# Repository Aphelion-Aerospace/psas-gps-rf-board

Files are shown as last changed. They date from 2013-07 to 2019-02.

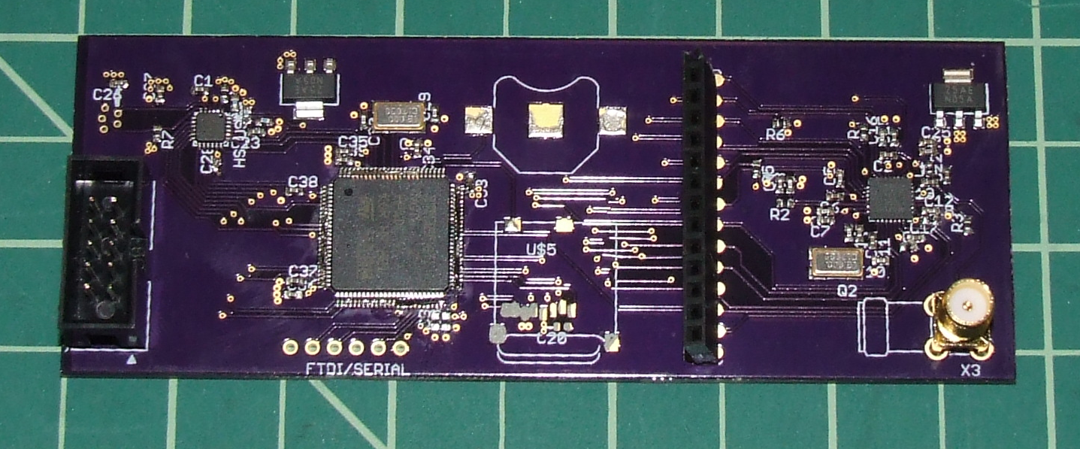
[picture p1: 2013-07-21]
poster/rf-board.png

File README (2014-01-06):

Universal GPS RF Front-end Board

Current status: January 2014 - Ready to order v2 board and parts 

Author: Jenner Hanni <wicker>
School: Portland State University

License: BSD "3 clause" license.

BOM available at 
https://docs.google.com/spreadsheet/ccc?key=0Aj2ugLxWTS6bdDNQeDJjXzUxYTRNRFFiaVJvZ1Nmanc&usp=sharing

This is an RF front-end board that breaks out I and Q signals to serial, USB, and Ethernet for GPS receiver development. 

Several GPS receiver boards exist on the market to receive GPS satellite signals and process it to provide location data but these GPS receivers only give the final location. Getting access to the raw data before they go into correlators means you have to purchase a “RF front end” for hundreds of dollars, at which point you can work on projects like building an FPGA receiver board or developing a software radio receiver. 

Both of these projects are in-progress projects at Portland State, and are stalled on purchasing the very expensive RF front end. This project proposes to design, build, and release an open-source GPS receiver RF front-end board that would offer the GPS raw data over USB and serial outputs. Open source GPS receiver boards do exist, including in Andrew Greenberg’s GPL-GPS Master’s thesis, but all are based on very out dated and out-of-production GPS chipsets and are not easily acquired. 

Cost is also a factor: commercial RF front end boards are hundreds to thousands of dollars. And while the proposed chip for this project, the MAX2769 Universal GPS Receiver, costs only $5, the development kit is $600 -- in other words, cost prohibitive for a small project and frustrating for embedded software developers who may not have the time or experience to design and build their own hardware.

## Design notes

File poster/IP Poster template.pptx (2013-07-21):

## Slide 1

  - Universal GPS RF Front-end Board

  - Jenner Hanni, MEng, ECE

Summary

This is an open source, hand held device that makes raw GPS satellite data available for the development of custom receivers.

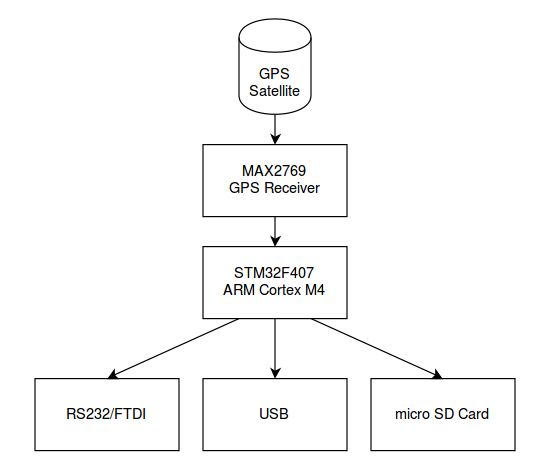
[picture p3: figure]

Figure 1. Data path from satellite to user.

Implementation

Powered by either a 3.3V Coin cell battery or 5V DC power over USB from a laptop.
The data stream is available over USB, serial, or directly to the micro SD card.
STM32F407 is an ARM Cortex M4 chip.
MAX2769 GPS Receiver chip supports a powered or unpowered antenna.
The STM32F407 is a newer chip with extensive documentation and a hobbyist developer community.
All schematics and software are open source so the board can be modified.
Total component cost is under $100.

Claim

GPS receivers turn the reference data from the satellites into an absolute position. Making new and better GPS receivers is good for both consumer product development and academic research with applications from medical devices to autonomous vehicles.
There are many techniques that can be used in the GPS receivers but developers need the raw I and Q signals from a front-end board.
Current boards are closed-source, don't make enough streaming data available or allow for enough of it to be saved, and in any case are prohibitively expensive.


Figure 2. Hardware prototype.

Requirements

Mobile, hand-held. Low cost with readily available components. Multiple ways to save the data and platform independent.
Open source schematics and software.

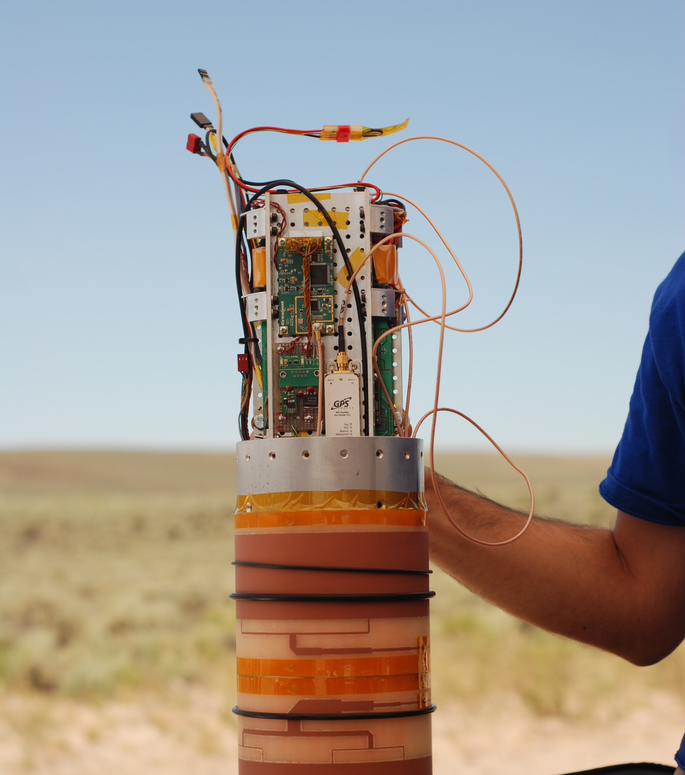
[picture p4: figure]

Figure 3. Rocket avionics module

Collaborators

Bart Massey, Andrew Greenberg and
the Portland State Aerospace Society.
Source code and schematics available at
http://github.com/wicker/

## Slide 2

Hardware

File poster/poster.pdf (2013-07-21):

l Jenner Hanni, MEng, ECE

## lUniversal GPS RF Front-end Board

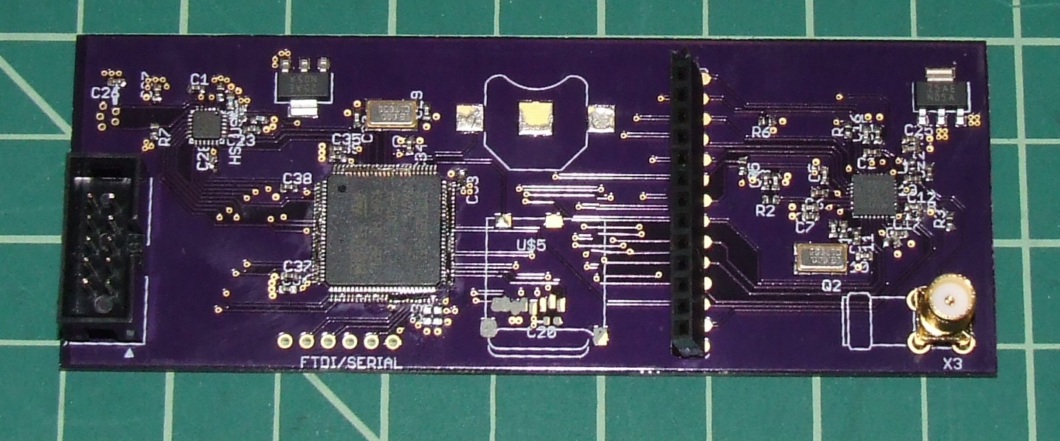
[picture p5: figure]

Figure 2. Hardware prototype.

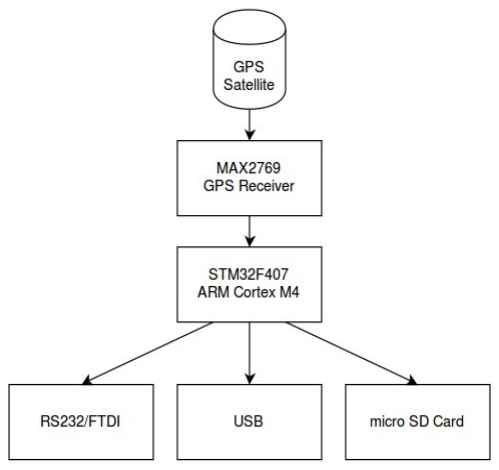
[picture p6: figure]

Figure 1. Data path from satellite to user.

This is an open source, hand held device that makes raw GPS satellite data available for the development of custom receivers.

### Summary

GPS receivers turn the reference data from the satellites into an absolute position. Making new and better GPS receivers is good for both consumer product development and academic research with applications from medical devices to autonomous vehicles.

There are many techniques that can be used in the GPS receivers but developers need the raw I and Q signals from a front-end board.

Current boards are closed-source, don't make enough streaming data available or allow for enough of it to be saved, and in any case are prohibitively expensive.

### Claim

Mobile, hand-held. Low cost with readily available components. Multiple ways to save the data and platform independent. Open source schematics and software.

### Requirements

Powered by either a 3.3V Coin cell battery or 5V DC power over USB from a laptop.

The data stream is available over USB, serial, or directly to the micro SD card.

STM32F407 is an ARM Cortex M4 chip.

MAX2769 GPS Receiver chip supports a powered or unpowered antenna.

The STM32F407 is a newer chip with extensive documentation and a hobbyist developer community.

All schematics and software are open source so the board can be modified.

Total component cost is under $100.

### Implementation

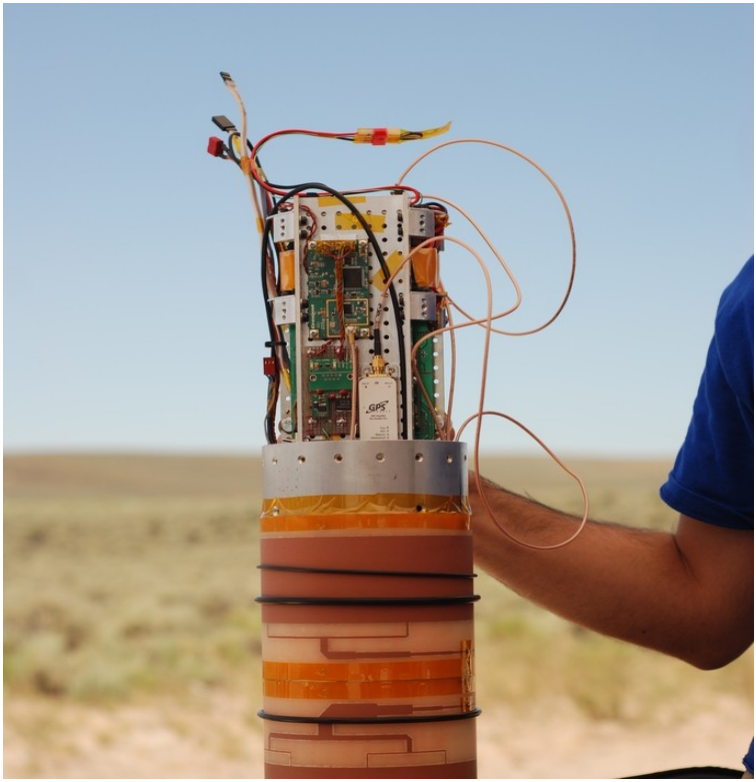
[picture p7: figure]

Figure 3. Rocket avionics module

Bart Massey, Andrew Greenberg and the Portland State Aerospace Society.

Source code and schematics available at http://github.com/wicker/

### Collaborators

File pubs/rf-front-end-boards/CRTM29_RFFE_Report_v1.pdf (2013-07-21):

## Design and Development of an RF Front End Board for NIJ Public Safety Radio

### S.M. Shajedul Hasan∗ and S.W. Ellingson

### July 22, 2008

## Contents

1 Introduction | 2
2 RFFE Board Overview | 2
3 Analog Signal Path Planning | 4
4 Description of Multiplexer Section | 6
5 Description of Amplifier Section | 8
6 Description of Attenuator Section | 8
7 Description of Power Supply Section | 10
8 Description of the Settings | 10
9 Summary | 10
A Bill of Materials | 14
B Schematic | 19
C Layout | 24

∗Bradley Dept. of Electrical & Computer Engineering, 432 Durham Hall, Virginia Polytechnic Institute & State University, Blacksburg, VA 24061 USA. E-mail: hasan@vt.edu

## 1 Introduction

An experimental multi-band/multi-mode radio for public safety applications is being developed in Virginia Tech under a project sponsored by the U.S. Department of Justice [1]. The goal of this project is to develop and demonstrate a single radio which can operate in all the public safety frequency bands presented in [2, 3]. To provide context, Figure 1 shows a conceptual “board-level” overview of a prototype of the proposed radio, consisting of a RF front end board, RFIC transceiver board, ADC/DAC board, baseband processing board, and other control boards. The design and development of the RF front end (RFFE) board is described here.

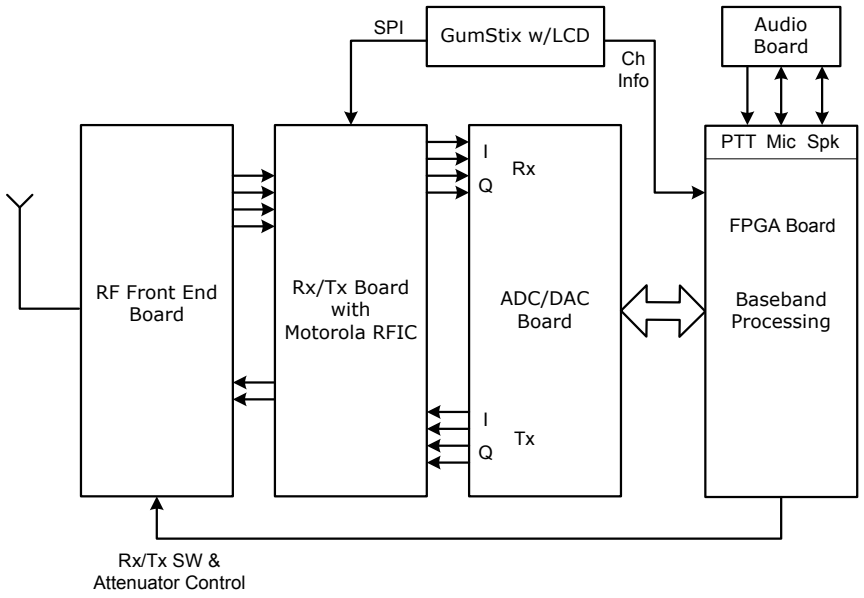
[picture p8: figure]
Rx/Tx Board with Motorola RFIC; RF Front End Board; ADC/DAC Board; Rx/Tx SW & Attenuator Control; Baseband Processing; FPGA Board; GumStix w/LCD SPI; Audio; Board; PTT Mic Spk; Ch Info

Figure 1: Conceptual board-level overview.

Figure 2 shows the image of the RF front end board.

This report is organized as follows. Section 2 presents the summary of the input/output ports of RFFE board. Section 3 describes the signal path planning and Section 4 presents multiplexer design methodology. Section 5 and 6 presents the circuit description of the amplifier and attenuator respectively. Section 6 describes the various jumper and switch settings. Section 7 concludes the report presenting the total cost. Finally, three appendices present the bill of materials, complete schematic and layout images.

## 2 RFFE Board Overview

Figure 3 and Table 1 present all the input/output ports of the RFFE board.

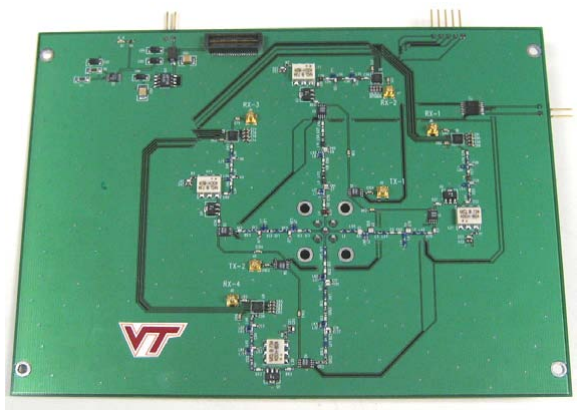
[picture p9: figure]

Figure 2: Image of RF Front End board.

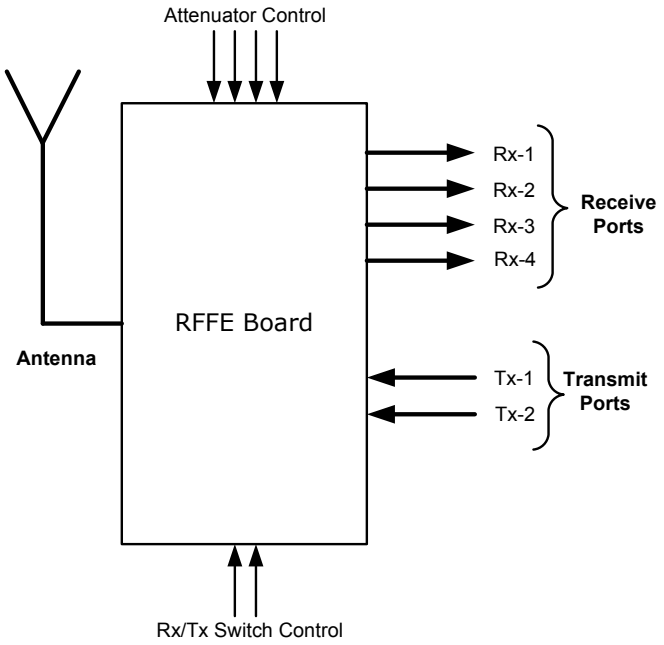
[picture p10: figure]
RFFE Board; Receive; Ports; Transmit; Attenuator Control; Rx/Tx Switch Control; Antenna

Figure 3: Summary of RFFE board.

Function | Port Name | Conn. Name | Characteristics
Receive Ports | RX-1 | J6 | RF Mux Ch-1 receive port
| RX-2 | J7 | RF Mux Ch-2 receive port
| RX-3 | J8 | RF Mux Ch-3 receive port
| RX-4 | J9 | RF Mux Ch-4 receive port
Transmit Ports | TX-1 | J2 | RF Mux Ch-1 or Ch-2 transmit port
| TX-2 | J3 | RF Mux Ch-3 or Ch-4 transmit port
Attenuator Control | ATT CTL | J5 | Attenuator control signals
Rx/Tx switch | SW CTL | J4 | Rx/Tx switch control signals

Table 1: Input/Output ports of the RFFE board.

## 3 Analog Signal Path Planning

This section describes some considerations in planning of the RFFE analog signal path. “Analog signal path” is defined here as the section beginning at the antenna terminals and ending at the input to the analog-to-digital converter (ADC). The analog signal path under consideration contains all the circuitry in the RFFE board, which includes multiplexer, amplifier, additional filtering and attenuators, and the RFIC transceiver board described in [4].

This signal path requirements are developed following the general strategy described in [5]. In order to receive the signal and digitize it appropriately the level of incoming signal should meet the specification of ADC. In this document we use the specifications of Analog Devices AD9248 ADC described in [6]. The relevant parameters and design constraints are shown in Table 2. Given this information, we can compute the required number of bits:

Nb ≥ 1.67 log10

Ptγr

Pextδr

(1)

where Pt

is the sum of the total receive signal power plus Pext, which is approximately equal to the total external noise power calculated using the table from [7]. Also, the minimum required gain in the analog signal path Gmin, and the maximum allowed gain Gr can be found using the following equations:

Gmin =

PQγq

Pext

(2)

Gr =

Pclipδr
Pt

(3)

A summary of the analysis is provided in Table 3, which shows the values of various design parameters (Nb,Gmin,Gr) corresponding to our frequency bands. Table 4, 5, 6, and 7 present the GNI analysis of the analog section for various channels using nominal gain.

Parameter | Value | Definition
Pclip PQ γq δr | +4 dBm -62 dBm +10 dB -10 dB | ADC full scale ADC quantization noise power, referenced to ADC input Desired ratio of Pext to PQ Maximum acceptable input power relative to Pclip

Table 2: Assumed analog-to-digital converter (ADC) specifications and associated design constraints.

Frequency | Pt | Pext | Nb | Gmin | Gr
138-174 MHz | -90.0 dBm | -122.5 dBm | 8.8 | 70.5 dB | 84.0 dB
220-222 MHz | -90.0 dBm | -128.1 dBm | 9.7 | 76.1 dB | 84.0 dB
406-512 MHz | -90.0 dBm | -135.3 dBm | 10.9 | 83.3 dB | 84.0 dB
764-862 MHz | -90.0 dBm | -142.9 dBm | 12.2 | 90.9 dB | 84.0 dB

Table 3: Design implications (Nb,Gmin,Gr) corresponding to various choices of frequency range and response. Gain here defined is defined from antenna terminals to ADC input.

Section | Gain (dB) | IP3 (dBm) | Noise Figure (dB)
Muiltiplexer | -8 | 200 | 8
Preamp | 25 | 12.9 | 2.7
Filter | -1 | 200 | 1
Attenuator | -1 | 30 | 1
RFIC | 69 | -6 | 7
GNI Analysis | 84 | -21.0 | 10.75
Sensitivity | -117.8 dBm

Table 4: GNI analysis of Channel-1 for nominal gain.

Section | Gain (dB) | IP3 (dBm) | Noise Figure (dB)
Muiltiplexer | -4 | 200 | 4
Preamp | 25 | 12.9 | 2.7
Filter | -1 | 200 | 1
Attenuator | -5 | 30 | 5
RFIC | 69 | -6 | 7
GNI Analysis | 84 | -21.0 | 6.84
Sensitivity | -120.8 dBm

Table 5: GNI analysis of Channel-2 for nominal gain.

Section | Gain (dB) | IP3 (dBm) | Noise Figure (dB)
Muiltiplexer | -1 | 200 | 1
Preamp | 25 | 12.9 | 2.7
Filter | -1 | 200 | 1
Attenuator | -8 | 30 | 8
RFIC | 69 | -6 | 7
GNI Analysis | 84 | -21.0 | 3.98
Sensitivity | -127.8 dBm

Table 6: GNI analysis of Channel-3 for nominal gain.

Section | Gain (dB) | IP3 (dBm) | Noise Figure (dB)
Muiltiplexer | -5.0 | 200 | 5.0
Preamp | 25 | 12.9 | 2.7
Filter | -1 | 200 | 1
Attenuator | -1.0 | 30 | 1.0
RFIC | 66 | -6 | 7
GNI Analysis | 84 | -24.0 | 7.75
Sensitivity | -125.5 dBm

Table 7: GNI analysis of Channel-4 for nominal gain.

## 4 Description of Multiplexer Section

A four channel multiplexer has been designed using the methodology described in [8]. As we know sensitivity depends on signal to noise ratio and external noise can be very strong in practical scenarios, especially at low frequencies (below ˜400 MHz). So, when the ratio of external noise to internal noise is large, additional effort to minimize reflection co-efficient or internal noise will have little effect on sensitivity. Therefore, our main idea is to design a multiplexer, which may be poorly matched with the antenna impedance, in such a way that the front end is dominated by the external noise and provide acceptable sensitivity.

In our design we use a simple monopole antenna ANT-433-CW from Antenna Factor. The length of this antenna is 17.3 cm long and diameter is 6 mm. The measured impedance of this antenna is shown in Figure 4.

Figure 5 shows the response of the designed multiplexer optimized to match with the antenna impedance to provide acceptable sensitivity. These results are expressed in terms of transducer power gain (TPG), defined as the ratio of power delivered by a matching network to a load, to the power delivered to a perfectly matched load directly from the antenna. Note that the performance is unacceptable, especially in the 138-174 MHz band. However, this poor matching gives us the sensitivity of -117.8 dBm, which is acceptable for our receiver.

Each of the channel of our designed multiplexer uses fifth order chebyshev topology, which is shown in Figure 6. Table 8 shows the component values of multiplexer before and

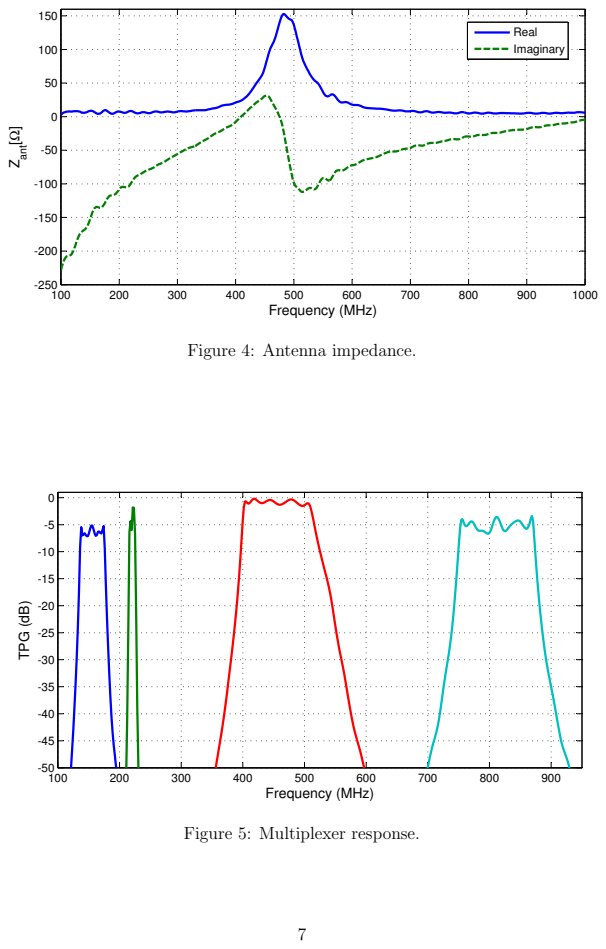
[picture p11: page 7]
Frequency (MHz); Zant; Real; Imaginary; TPG (dB)

Figure 4: Antenna impedance.

Figure 5: Multiplexer response.

after the optimization. L1 | C1
L2 | C2
L3 | C3
L4 | C4
L5 | C5

50Ω

Receiver
Input To Antenna

Figure 6: Multiplexer topology of each channel.

Component | Channel–1 | Channel–2 | Channel–3 | Channel–4
| Before | After | Before | After | Before | After | Before | After
L1 (nH) | 377.1 | 306.0 | 1357.4 | 1350 | 111.2 | 120 | 114.9 | 130
C1 (pF) | 2.8 | 5.4 | 0.4 | 0.41 | 1.1 | 1.1 | 0.3 | 0.308
L2 (nH) | 9.7 | 7.8 | 1.3 | 1.32 | 3.1 | 3.1 | 0.9 | 1.15
C2 (pF) | 108.7 | 139.0 | 391.4 | 399 | 39.0 | 39.0 | 42.8 | 33.8
L3 (nH) | 561.6 | 426.0 | 2021.9 | 2027 | 173.4 | 175 | 182.0 | 178
C3 (pF) | 1.9 | 2.45 | 0.3 | 0.255 | 0.7 | 0.7 | 0.2 | 0.216
L4 (nH) | 9.7 | 9.0 | 1.3 | 1.32 | 3.1 | 3.1 | 0.9 | 1.15
C4 (pF) | 108.7 | 118.0 | 391.4 | 393.0 | 39.0 | 39.0 | 42.8 | 33.7
L5 (nH) | 377.1 | 246.0 | 1357.4 | 1380 | 112.2 | 110 | 114.9 | 105.6
C5 (pF) | 2.8 | 4.33 | 0.4 | 0.375 | 1.1 | 1.1 | 0.3 | 0.368

Table 8: Component values of the multiplexer before and after the optimization.

## 5 Description of Amplifier Section

In our design we use GALI-74 amplifier from Minicircuits. This amplifier is chosen mainly for its low cost and low noise characteristics. ADCH-80A, a wideband choke from Minicircuits, is also used to minimize the RF loss caused by the DC biasing resistor. The circuit of this amplifier is designed for 9V DC bias. Fig. 7 shows the circuit diagram example for the amplifier. Detailed circuit diagrams can be found in “Amplifier” sheet in Appendix B. This sheet also contains four fifth order chebyshev bandpass filters after each of the amplifiers to perform additional filtering.

## 6 Description of Attenuator Section

To control the attenuation of the received signal we use a 5-bit digitally controlled attenuator HMC470LP3 from Hittite Microwave Inc. Fig. 8 shows the circuit diagram of the attenuator. Detailed circuit diagrams can be found in “Attenuator” sheet in Appendix B.

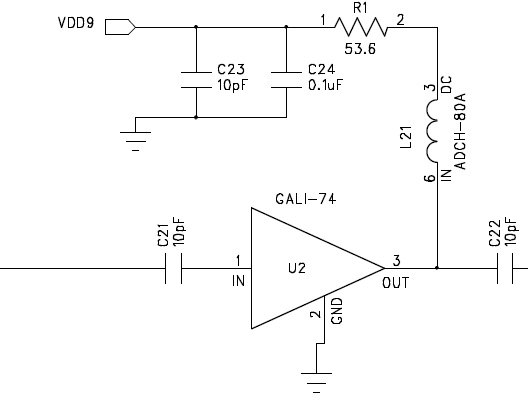
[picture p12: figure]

Figure 7: Amplifier section ( the unconnected line on the left side connects the input port of the amplifier with the RX switches and right side goes to input of the bandpass filter).

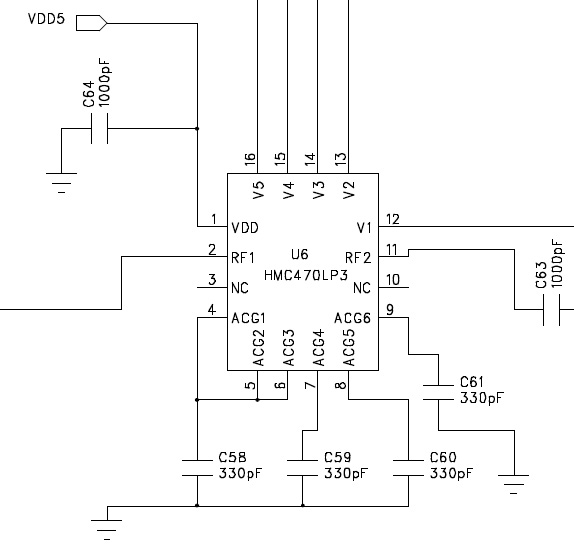
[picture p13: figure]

Figure 8: Attenuator section (RF1 and RF2 are the input and output port of the attenuator. Other unconnected lines in the figure are the control signal to vary the attenuation).

## 7 Description of Power Supply Section

One 9V supply voltage for amplifiers and one 5V supply voltage for RF switches and attenuators, have been created from a single 16V power source. This 16V input voltage is fed into a 1.1A low dropout regulator IC LT1965 to create a 9V positive voltage. 5V regulated voltage is supplied by the 500 mA low dropout regulator ICs LT763. Both of these regulator ICs are manufactured by Linear Technology Inc. Detailed circuit diagrams can be found in “Power Supply” sheet in Appendix B.

## 8 Description of the Settings

Table 9 shows the specification of attenuator control signals to get various attenuation.

V1 16dB | V2 8dB | v3 4dB | V4 2dB | V5 1dB | ATT State
High | High | High | High | High | Insertion Loss
High | High | High | High | Low | 1dB
High | High | High | Low | High | 2dB
High | High | Low | High | High | 4dB
High | Low | High | High | High | 8dB
Low | High | High | High | High | 16dB
Low | Low | Low | Low | Low | 31dB

Table 9: Attenuator control signals.

Table 10 shows the Rx/Tx swtich control signals.

S0 | S1 | Rx/Tx Mode
High | X | RX Mode
Low | Low | TX Mode ( Ch.1 or Ch.3 )
Low | High | TX Mode ( Ch.2 or Ch.4 )

Table 10: Rx/Tx Switch Control Signals.

## 9 Summary

A summary of the cost for one RFFE board is given in Table 11. Since we prepared just two boards for the present study using the quickest manufacturing time, the PCB fabrication and assembly cost is not representative of the cost to build the same device in large quantities.

Component | Quantity | Price(US $)
Regulator ICs | 2 | 8.58
Amplifier | 4 | 18.80
RF Choke | 4 | 59.0
Attenuator | 4 | 15.32
RF Switch | 6 | 7.08
Capacitor | 109 | 16.35
Inductor | 61 | 45.75
Resistor | 7 | 1.00
MMCX Connector | 6 | 60.30
Other Connectors | 5 | 10.0
Other Components | 3 | 3.50
| Subtotal | 245.68
PC Board | 1 | 450.00
PC Board Assembly | 1 | 925.00
| Total | 1620.68

Table 11: Summary of the cost for one RFFE board.

## References

[1] NIJ project web site, http://www.ece.vt.edu/swe/chamrad/.
[2] S. W. Ellingson, “Phase I Technical Report,” Virginia Tech, VA, Tech. Rep. 15, Oct. 2006. [Online]. Available: http://www.ece.vt.edu/swe/chamrad/.
[3] S. W. Ellingson, S.M. Hasan, M. Harun, and C.R. Anderson, “Phase II Technical Report,” Virginia Tech, VA, Tech. Rep. 23, Oct. 2007. [Online]. Available: http://www.ece.vt.edu/swe/chamrad/.
[4] S.M. Hasan and S.W. Ellingson, “Design and Development of an Evaluation Board with RFIC Ver. 4,” Virginia Tech, VA, Tech. Rep. 22, Sep. 2007. [Online]. Available: http://www.ece.vt.edu/swe/chamrad/.
[5] D.W.A. Taylor III, Design of Ultrawideband Digitizing Receivers for the VHF Low Band, M.S. Thesis, Virginia Polytechnic Institute & State University, 2006. [Online]. Available: http://scholar.lib.vt.edu/theses/available/etd-05162006-161217/.
[6] S.M. Hasan and S.W. Ellingson, “ Design and Development of an ADC/DAC Evaluation Board for NIJ Public Safety Radio,” Virginia Tech, VA, Tech. Rep. 24, Nov. 2007. [Online]. Available: http://www.ece.vt.edu/swe/chamrad/.
[7] S.M. | Hasan | and | S.W. | Ellingson, | “ | Optimum | Noise | Figure | Specifica-
tion,” | Virginia Tech, | VA, Tech. Rep. 20, | Apr. 2007. [Online]. Available:
http://www.ece.vt.edu/swe/chamrad/.
[8] S.M. Hasan and S.W. Ellingson, “Multiband Antenna-Receiver Integration using an RF Multiplexer with Sensitivity-Constrained Design”, IEEE 2008 International Symposium on Antenna and Propagation, San Diego, July, 2008.

# Appendices

## A Bill of Materials

This section presents the bill of materials.

Bill of Materials
RFFE Board, Ver.2.0
MPRG/Virginia Tech
Prepared By: S.M. Hasan, Date: MAR 11, 2008
Item | Qty | Reference | Part Name | Package | Manufacturer | Manufacturer Part# | Distributor | Distributor Part# | Description
1 | 1 | U1 | 74VHCT04AMTC | 14-TSSOP | FAIRCHILD | 74VHCT04AMTC | Mouser | 512-74VHCT04AMTC | HEX INVERTER
2 | 4 | L21 L27 L33 L39 | ADCH-80A | CD542 | Minicircuits | ADCH-80A+ | Minicircuits | ADCH-80A+ | RF Choke
3 | 1 | C93 | 0.01uF 100V | CAP_1210 | AVX Corporation | 12101C103KAT2A | Digikey | 478-1608-1-ND | SURFACE MOUNT CAPACITOR 0.098 X 0.126 INCHES
4 | 1 | C92 | 1uF 100V | CAP_1210 | AVX Corporation | 12101C105KAT2A | Digikey | 478-2570-1-ND | SURFACE MOUNT CAPACITOR 0.098 X 0.126 INCHES
5 | 4 | C24 C33 C42 C51 | 0.1uF 50V | CAP_0603 | Murata Electronics | GRM188R71H104KA93D | Digikey | 490-1519-1-ND | SURFACE MOUNT CAPACITOR 0603 Size
6 | 3 | C52 C54 C56 | 0.3pF 50V | CAP_0603 | AVX Corporation | 06035J0R3PBTTR | Digikey | 478-2801-1-ND | SURFACE MOUNT CAPACITOR 0603 Size
7 | 1 | C86 | 0.4pF 250V | CAP_0603 | AVX Corporation | SQCSVA0R4BAT1A | Digikey | 478-3483-1-ND | SURFACE MOUNT CAPACITOR 0603 Size
8 | 3 | C10 C36 C99 | 0.5pF 100V | CAP_0603 | Murata Electronics | GQM1885C2AR50CB01D | Digikey | 490-3551-1-ND | SURFACE MOUNT CAPACITOR 0603 Size
9 | 1 | C106 | 0.6pF 250V | CAP_0603 | AVX Corporation | SQCSVA0R6BAT1A | Digikey | 478-3484-1-ND | SURFACE MOUNT CAPACITOR 0603 Size
10 | 4 | C8 C13 C78 C107 | 0.7pF 50V | CAP_0603 | AVX Corporation | 06035J0R7PBSTR | Digikey | 478-4445-1-ND | SURFACE MOUNT CAPACITOR 0603 Size
11 | 4 | C16 C34 C38 C101 | 0.8pF 250V | CAP_0603 | AVX Corporation | SQCSVA0R8BAT1A | Digikey | 478-3485-1-ND | SURFACE MOUNT CAPACITOR 0603 Size
12 | 3 | C20 C105 C109 | 0.9pF 50V | CAP_0603 | AVX Corporation | 06035J0R9PBTTR | Digikey | 478-2807-1-ND | SURFACE MOUNT CAPACITOR 0603 Size
13 | 2 | C11 C15 | 1.1pF 250V | CAP_0603 | AVX Corporation | SQCSVA1R1BAT1A | Digikey | 478-3487-1-ND | SURFACE MOUNT CAPACITOR 0603 Size
14 | 4 | C43 C47 C97 C108 | 1.5pF 250V | CAP_0603 | AVX Corporation | SQCSVA1R5BAT1A | Digikey | 478-3489-1-ND | SURFACE MOUNT CAPACITOR 0603 Size
15 | 1 | C27 | 1.8pF 250V | CAP_0603 | AVX Corporation | SQCSVA1R8BAT1A | Digikey | 478-3490-1-ND | SURFACE MOUNT CAPACITOR 0603 Size
16 14 | | C63-64 C71-72 C79-80 C87-88 C96 C98 C100 C102-104 | 1000pF 50V | CAP_0603 | AVX Corporation | 06035C102KAT2A | Digikey | 478-1215-1-ND | SURFACE MOUNT CAPACITOR 0603 Size
17 | 2 | C2 C4 | 100pF 50V | CAP_0603 | AVX Corporation | 06035A101KAT2A | Digikey | 478-3717-1-ND | SURFACE MOUNT CAPACITOR 0603 Size
18 | 12 | C21-23 C30-32 C39-41 C48-50 | 10pF 250V | CAP_0603 | AVX Corporation | SQCSVA100JAT1A | Digikey | 478-3502-1-ND | SURFACE MOUNT CAPACITOR 0603 Size
19 | 2 | C26 C28 | 110pF 100V | CAP_0603 | Murata Electronics | GRM1885C2A111JA01D | Digikey | 490-1352-1-ND | SURFACE MOUNT CAPACITOR 0603 Size
20 | 1 | C70 | 18pF 250V | CAP_0603 | AVX Corporation | SQCSVA180JAT1A | Digikey | 478-3505-1-ND | SURFACE MOUNT CAPACITOR 0603 Size
21 | 3 | C6 C18 C45 | 1pF 250V | CAP_0603 | AVX Corporation | SQCSVA1R0BAT1A | Digikey | 478-3486-1-ND | SURFACE MOUNT CAPACITOR 0603 Size

Item | Qty | Reference | Part Name | Package | Manufacturer | Manufacturer Part# | Distributor | Distributor Part# | Description
22 | 1 | C57 | 2.4pF 250V | CAP_0603 | AVX Corporation | SQCSVA2R4BAT1A | Digikey | 478-3493-1-ND | SURFACE MOUNT CAPACITOR 0603 Size
23 | 2 | C25 C29 | 2.7pF 250V | CAP_0603 | AVX Corporation | SQCSVA2R7BAT1A | Digikey | 478-3494-1-ND | SURFACE MOUNT CAPACITOR 0603 Size
24 | 2 | C35 C37 | 200pF 100V | CAP_0603 | Murata Electronics | GRM1885C2A201JA01D | Digikey | 490-1358-1-ND | SURFACE MOUNT CAPACITOR 0603 Size
25 | 16 | C58-61 C66-69 C74-77 C82-85 | 330pF 50V | CAP_0603 | Panasonic | ECJ-1VC1H331J | Digikey | PCC331ACVCT-ND | SURFACE MOUNT CAPACITOR 0603 Size
26 | 5 | C17 C19 C53 C55 C95 | 33pF 250V | CAP_0603 | AVX Corporation | SQCSVA330JAT1A | Digikey | 478-3511-1-ND | SURFACE MOUNT CAPACITOR 0603 Size
27 | 2 | C7 C9 | 360pF 100V | CAP_0603 | Murata Electronics | GRM1885C2A361JA01D | Digikey | 490-1364-1-ND | SURFACE MOUNT CAPACITOR 0603 Size
28 | 6 | C12 C14 C44 C46 C62 C81 | 39pF 250V | CAP_0603 | AVX Corporation | SQCSVA390JAT1A | Digikey | 478-3512-1-ND | SURFACE MOUNT CAPACITOR 0603 Size
29 | 1 | C1 | 3pF 250V | CAP_0603 | AVX Corporation | SQCSVA3R0BAT1A | Digikey | 478-3495-1-ND | SURFACE MOUNT CAPACITOR 0603 Size
30 | 1 | C65 | 4.7pF 250V | CAP_0603 | AVX Corporation | SQCSVA4R7CAT1A | Digikey | 478-3498-1-ND | SURFACE MOUNT CAPACITOR 0603 Size
31 | 1 | C3 | 5.1pF 100V | CAP_0603 | Murata Electronics | GQM1885C2A5R1CB01D | Digikey | 490-3559-1-ND | SURFACE MOUNT CAPACITOR 0603 Size
32 | 1 | C5 | 8.2pF 250V | CAP_0603 | AVX Corporation | SQCSVA8R2CAT1A | Digikey | 478-3501-1-ND | SURFACE MOUNT CAPACITOR 0603 Size
33 | 1 | C73 | 9.1pF 50V | CAP_0603 | Murata Electronics | GQM1885C1H9R1CB01D | Digikey | 490-3569-1-ND | SURFACE MOUNT CAPACITOR 0603 Size
34 | 4 | C89-91 C94 | 10uF 16V | CAP_3216 | Rohm | TCA1C106M8R | Digikey | 511-1473-1-ND | CAP TANTALUM
35 | 1 | J11 | CONN_SAM8128_HEADE R | Plug | Samtec Inc | QTE-020-01-X-D-A | Digikey | SAM8128-ND | HIGH SPEED HEADER 40 PINS
36 | 1 | J1 | CONN_RPSMA-THROUGH | SMA | Linx Technologies | CONREVSMA001 | Digikey | CONREVSMA001-ND | SMA Through Hole Connector
37 | 4 | U2-5 | GALI-74 | DF782 | Mincircuits | GALI-74+ | Minicircuits | GALI-74+ | Monolithic Amplifier
38 | 6 | S1-6 | HMC284MS8G | MS8G | HITTITE | HMC284MS8G | HITTITE | HMC284MS8G | RF SWITHC
39 | 4 | U6-9 | HMC470LP3 | LP3 | HITTITE | HMC470LP3 | HITTITE | HMC470LP3 | 5 BIT DIGITAL ATTENUATOR
40 | 1 | D1 | LED_SMT | SMT | LITE-ON | LTST-C190GKT | Digikey | 160-1183-1-ND | LIGHT EMITTING DIODE
41 | 1 | E2 | LT1965 | MSOP8G | LINEAR TECHNOLOGY | LT1965 | Digikey | LT1965IMS8E#PBF-ND | LINEAR LDO REGULATOR
42 | 4 | L17 L19 L41 L43 | 1.6nH | L_0603 | Coilcraft | 0603CS-1N6X_LU | Coilcraft | 0603CS-1N6X_LU | Surface Mount Inductor 0603 Size
43 | 1 | L30 | 1000nH | L_0603 | Coilcraft | 0603LS-102X_LB | Coilcraft | 0603LS-102X_LB | Surface Mount Inductor 0603 Size
44 | 4 | L15-16 L20 L56 | 100nH | L_0603 | Coilcraft | 0603CS-R10X_LU | Coilcraft | 0603CS-R10X_LU | Surface Mount Inductor 0603 Size
45 | 1 | L58 | 10nH | L_0603 | Coilcraft | 0603CS-10NX_LU | Coilcraft | 0603CS-10NX_LU | Surface Mount Inductor 0603 Size
46 | 1 | L18 | 110nH | L_0603 | Coilcraft | 0603CS-R11X_LU | Coilcraft | 0603CS-R11X_LU | Surface Mount Inductor 0603 Size
47 | 2 | L8 L10 | 1200nH | L_0603 | Coilcraft | 0603LS-122X_LB | Coilcraft | 0603LS-122X_LB | Surface Mount Inductor 0603 Size
48 | 5 | L11 L36 L40 L42 L44 | 120nH | L_0603 | Coilcraft | 0603CS-R12X_LU | Coilcraft | 0603CS-R12X_LU | Surface Mount Inductor 0603 Size

Item | Qty | Reference | Part Name | Package | Manufacturer | Manufacturer Part# | Distributor | Distributor Part# | Description
49 | 1 | L2 | 12nH | L_0603 | Coilcraft | 0603CS-12NX_LU | Coilcraft | 0603CS-12NX_LU | Surface Mount Inductor 0603 Size
50 | 1 | L54 | 180nH | L_0603 | Coilcraft | 0603CS-R18X_LU | Coilcraft | 0603CS-R18X_LU | Surface Mount Inductor 0603 Size
51 | 2 | L7 L53 | 2.2nH | L_0603 | Coilcraft | 0603CS-2N2X_LU | Coilcraft | 0603CS-2N2X_LU | Surface Mount Inductor 0603 Size
52 | 6 | L29 L31 L62-65 | 2.6nH | L_0603 | Coilcraft | 0604HQ-2N6XJLB | Coilcraft | 0604HQ-2N6XJLB | Surface Mount Inductor 0603 Size
53 | 1 | L5 | 210nH | L_0603 | Coilcraft | 0603HP-R21X_LU | Coilcraft | 0603HP-R21X_LU | Surface Mount Inductor 0603 Size
54 | 1 | L46 | 22nH | L_0603 | Coilcraft | 0603CS-22NX_LU | Coilcraft | 0603CS-22NX_LU | Surface Mount Inductor 0603 Size
55 | 2 | L6 L50 | 2700nH | L_0603 | Coilcraft | 0603LS-272X_LB | Coilcraft | 0603LS-272X_LB | Surface Mount Inductor 0603 Size
56 | 1 | L1 | 270nH | L_0603 | Coilcraft | 0603HP-R27X_LU | Coilcraft | 0603HP-R27X_LU | Surface Mount Inductor 0603 Size
57 | 4 | L9 L35 L37 L51 | 3.3nH | L_0603 | Coilcraft | 0603HP-3N3X_LU | Coilcraft | 0603HP-3N3X_LU | Surface Mount Inductor 0603 Size
58 | 1 | L59 | 30nH | L_0603 | Coilcraft | 0603HP-30NX_LU | Coilcraft | 0603HP-30NX_LU | Surface Mount Inductor 0603 Size
59 | 3 | L45 L47 L49 | 36nH | L_0603 | Coilcraft | 0603HP-36NX_LU | Coilcraft | 0603HP-36NX_LU | Surface Mount Inductor 0603 Size
60 | 3 | L3 L22 L26 | 390nH | L_0603 | Coilcraft | 0603CS-R39X_LU | Coilcraft | 0603CS-R39X_LU | Surface Mount Inductor 0603 Size
61 | 1 | L48 | 4.3nH | L_0603 | Coilcraft | 0603HP-4N3X_LU | Coilcraft | 0603HP-4N3X_LU | Surface Mount Inductor 0603 Size
62 | 1 | L4 | 4.7nH | L_0603 | Coilcraft | 0603HP-4N7X_LU | Coilcraft | 0603HP-4N7X_LU | Surface Mount Inductor 0603 Size
63 | 3 | L12 L14 L61 | 5.6nH | L_0603 | Coilcraft | 0603HP-5N6X_LU | Coilcraft | 0603HP-5N6X_LU | Surface Mount Inductor 0603 Size
64 | 1 | L24 | 560nH | L_0603 | Coilcraft | 0603LS-561X_LB | Coilcraft | 0603LS-561X_LB | Surface Mount Inductor 0603 Size
65 | 2 | L55 L57 | 6.8nH | L_0603 | Coilcraft | 0603HP-6N8X_LU | Coilcraft | 0603HP-6N8X_LU | Surface Mount Inductor 0603 Size
66 | 2 | L28 L32 | 680nH | L_0603 | Coilcraft | 0603LS-681X_LB | Coilcraft | 0603LS-681X_LB | Surface Mount Inductor 0603 Size
67 | 1 | L60 | 68nH | L_0603 | Coilcraft | 0603HP-68NX_LU | Coilcraft | 0603HP-68NX_LU | Surface Mount Inductor 0603 Size
68 | 1 | L13 | 75nH | L_0603 | Coilcraft | 0603HP-75NX_LU | Coilcraft | 0603HP-75NX_LU | Surface Mount Inductor 0603 Size
69 | 1 | L52 | 827nH | L_0603 | Coilcraft | 0603LS-821X_LB | Coilcraft | 0603LS-821X_LB | Surface Mount Inductor 0603 Size
70 | 2 | L34 L38 | 82nH | L_0603 | Coilcraft | 0603HP-82NX_LU | Coilcraft | 0603HP-82NX_LU | Surface Mount Inductor 0603 Size
71 | 2 | L23 L25 | 9.5nH | L_0603 | Coilcraft | 0603HP-9N5X_LU | Coilcraft | 0603HP-9N5X_LU | Surface Mount Inductor 0603 Size
72 | 6 | J2-3 J6-9 | MMCX_PLUG | MMCX | Emerson | 135-3801-201 | Digikey | J601-ND | MMCX CONNECTOR
73 | 2 | J4 J10 | RA_SINGLEHEADER_2PIN | Male Header | TYCO | 87232-2 | Digikey | A28764-ND | 2-Pin R/A Single Row Header

Item | Qty | Reference | Part Name | Package | Manufacturer | Manufacturer Part# | Distributor | Distributor Part# | Description
74 | 1 | J5 | RA_SINGLEHEADER_5PIN | Male Header | TYCO | 87232-5 | Digikey | A28770-ND | 5-Pin R/A Single Row Header
75 | 4 | R1-4 | 53.6 1/10W | RES_0603 | Panasonic | ERJ-3EKF53R6V | Digikey | P53.6HCT-ND | SURFACE MOUNT RESISTOR 0603 Size
76 | 1 | R5 | 698 1/10W | RES_0603 | Rohm | MCR03EZPFX6980 | Digikey | RHM698HCT-ND | SURFACE MOUNT RESISTOR 0603 Size
77 | 1 | R6 | 26.1K 1/4W | RES_1206 | Rohm | MCR18EZHF2612 | Digikey | RHM26.1KFCT-ND | SURFACE MOUNT RESISTOR 1206 Size
78 | 1 | R7 | 4.02K 1/14W | RES_1206 | Rohm | MCR18EZHF4021 | Digikey | RHM4.02KFCT-ND | SURFACE MOUNT RESISTOR 1206 Size
79 | 1 | E1 | SM_BEADS_DIFF | SMT | FAIR-RITE PRODUCTS CORP | 2743019447 | Mouser | 623-2743019447LF | SM BEADS DIFFERENTIAL
80 | 1 | U10 | REGULATOR | SO-8 | Linear Technology | LT1763CS8-5 | Digikey | LT1763CS8-5-ND | Linear Regulator

## B Schematic

This section presents the schematic of the RFFE board. This schematic contains the following four pages-

- Multiplexer and Switch Circuits
- Amplifier Circuits
- Attenuator Circuits
- Power Supply Circuits

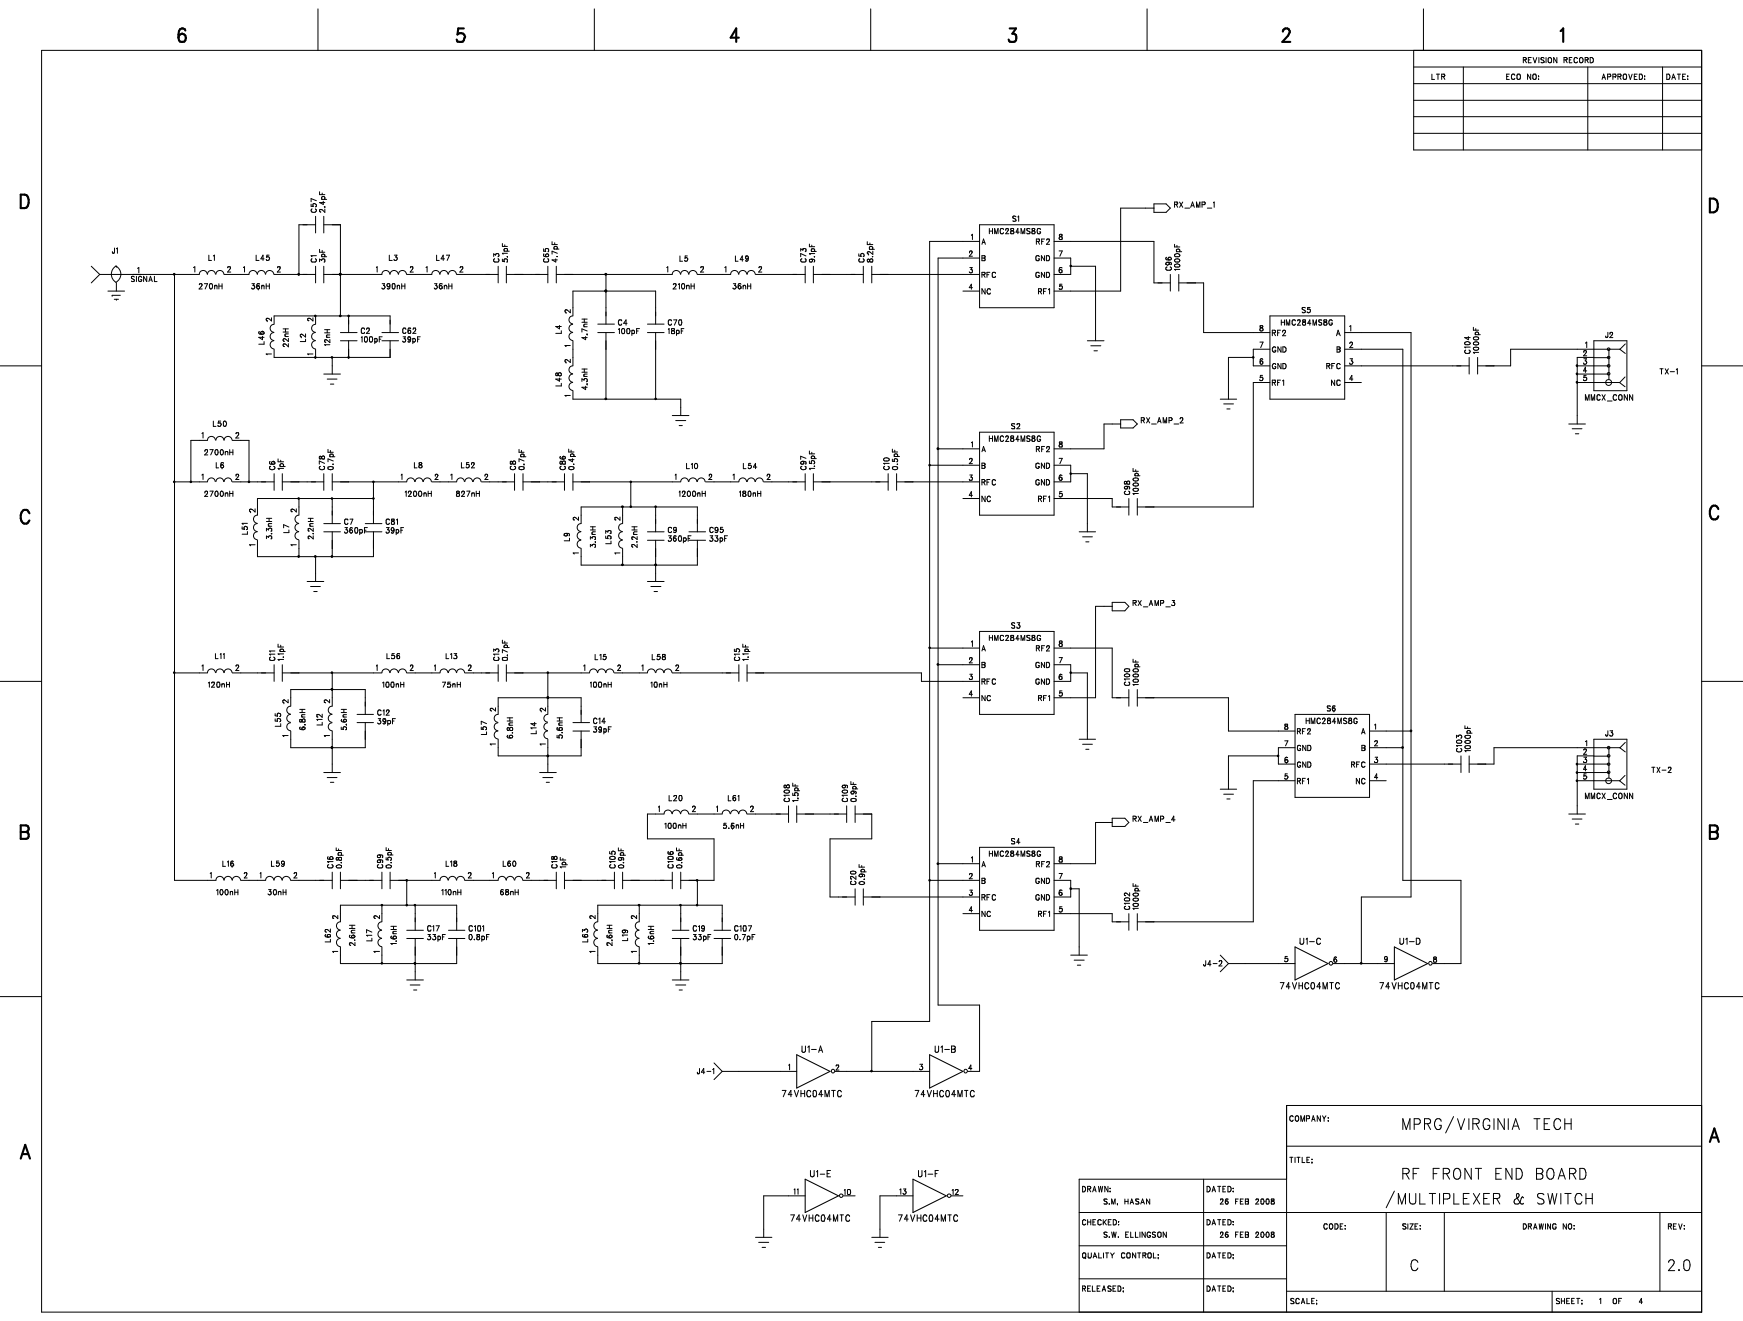
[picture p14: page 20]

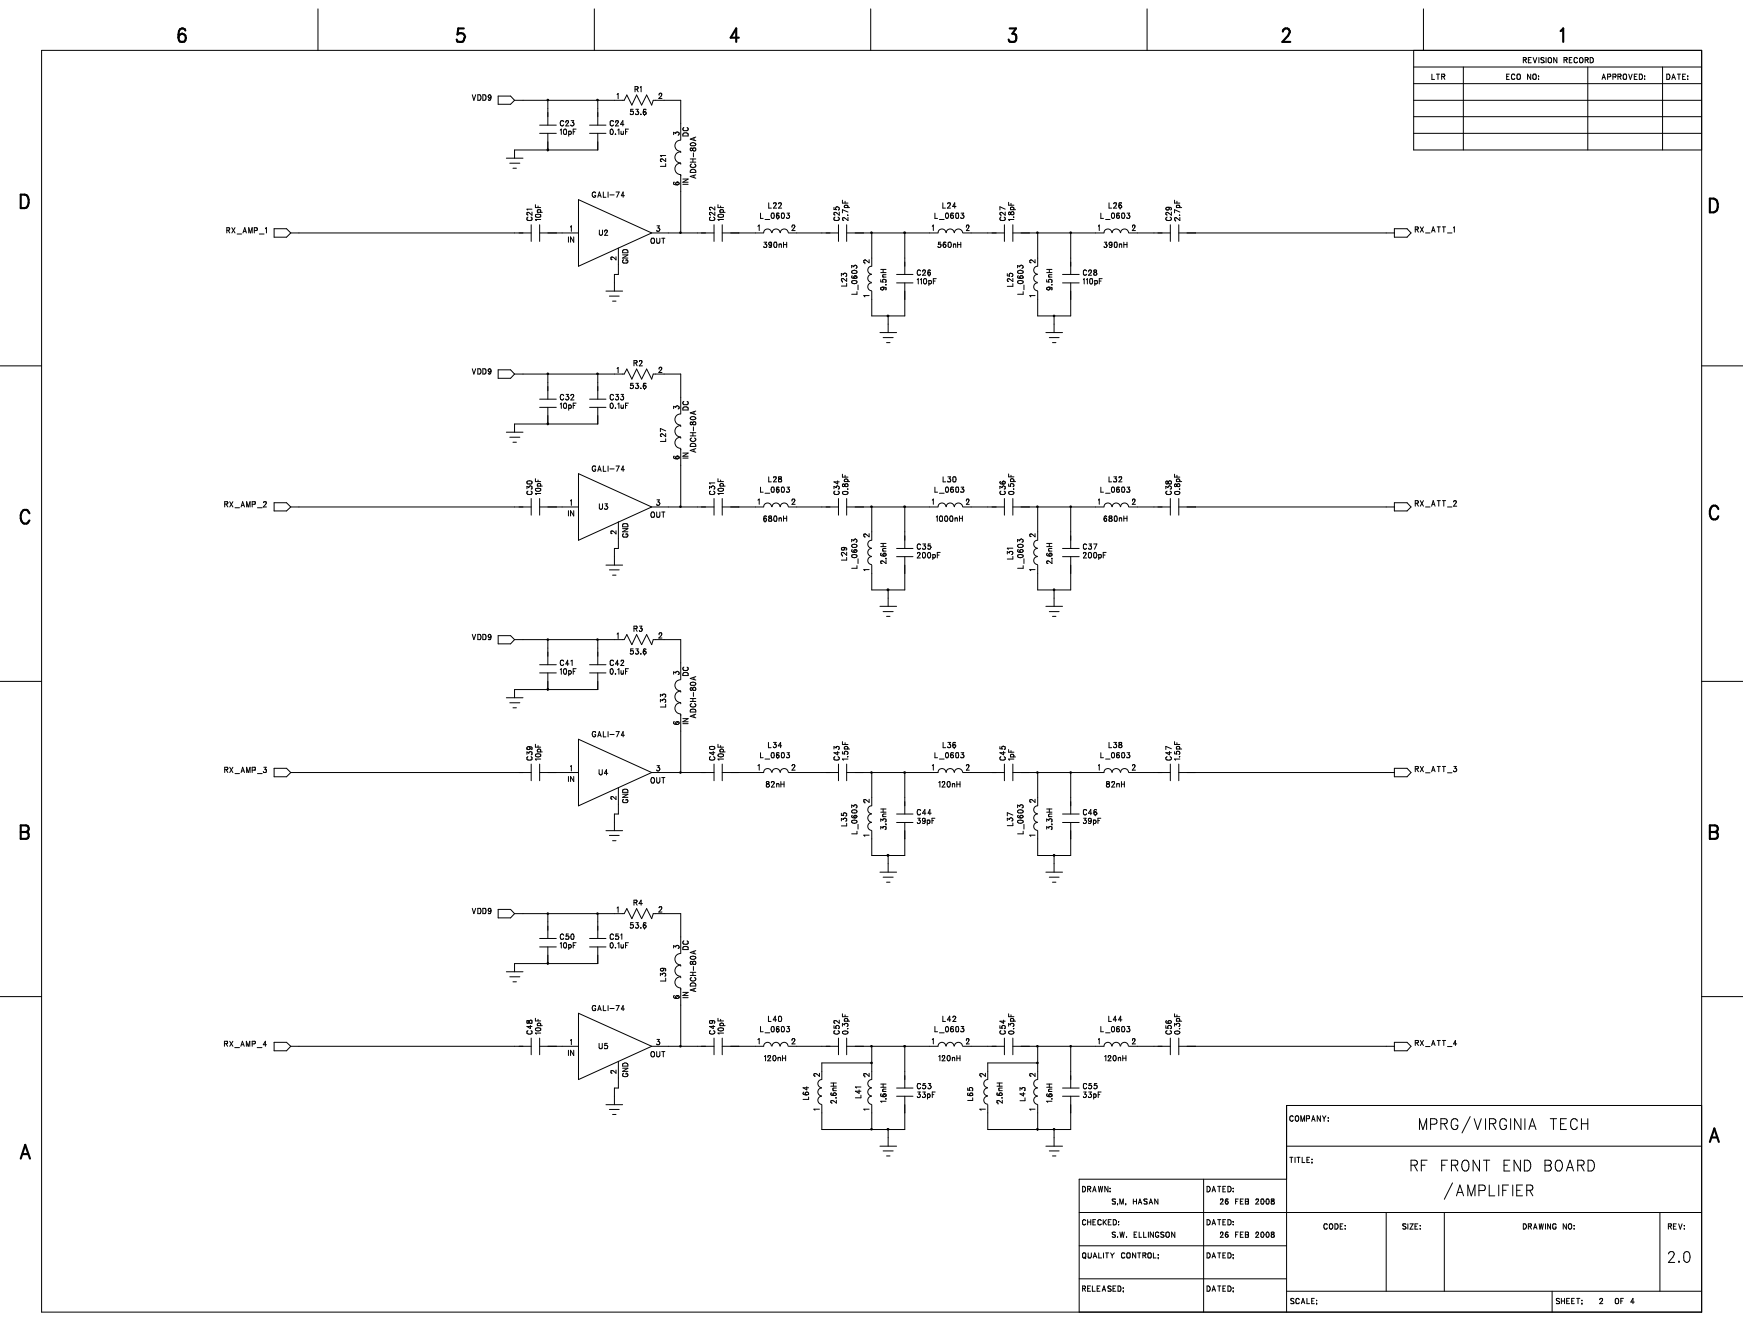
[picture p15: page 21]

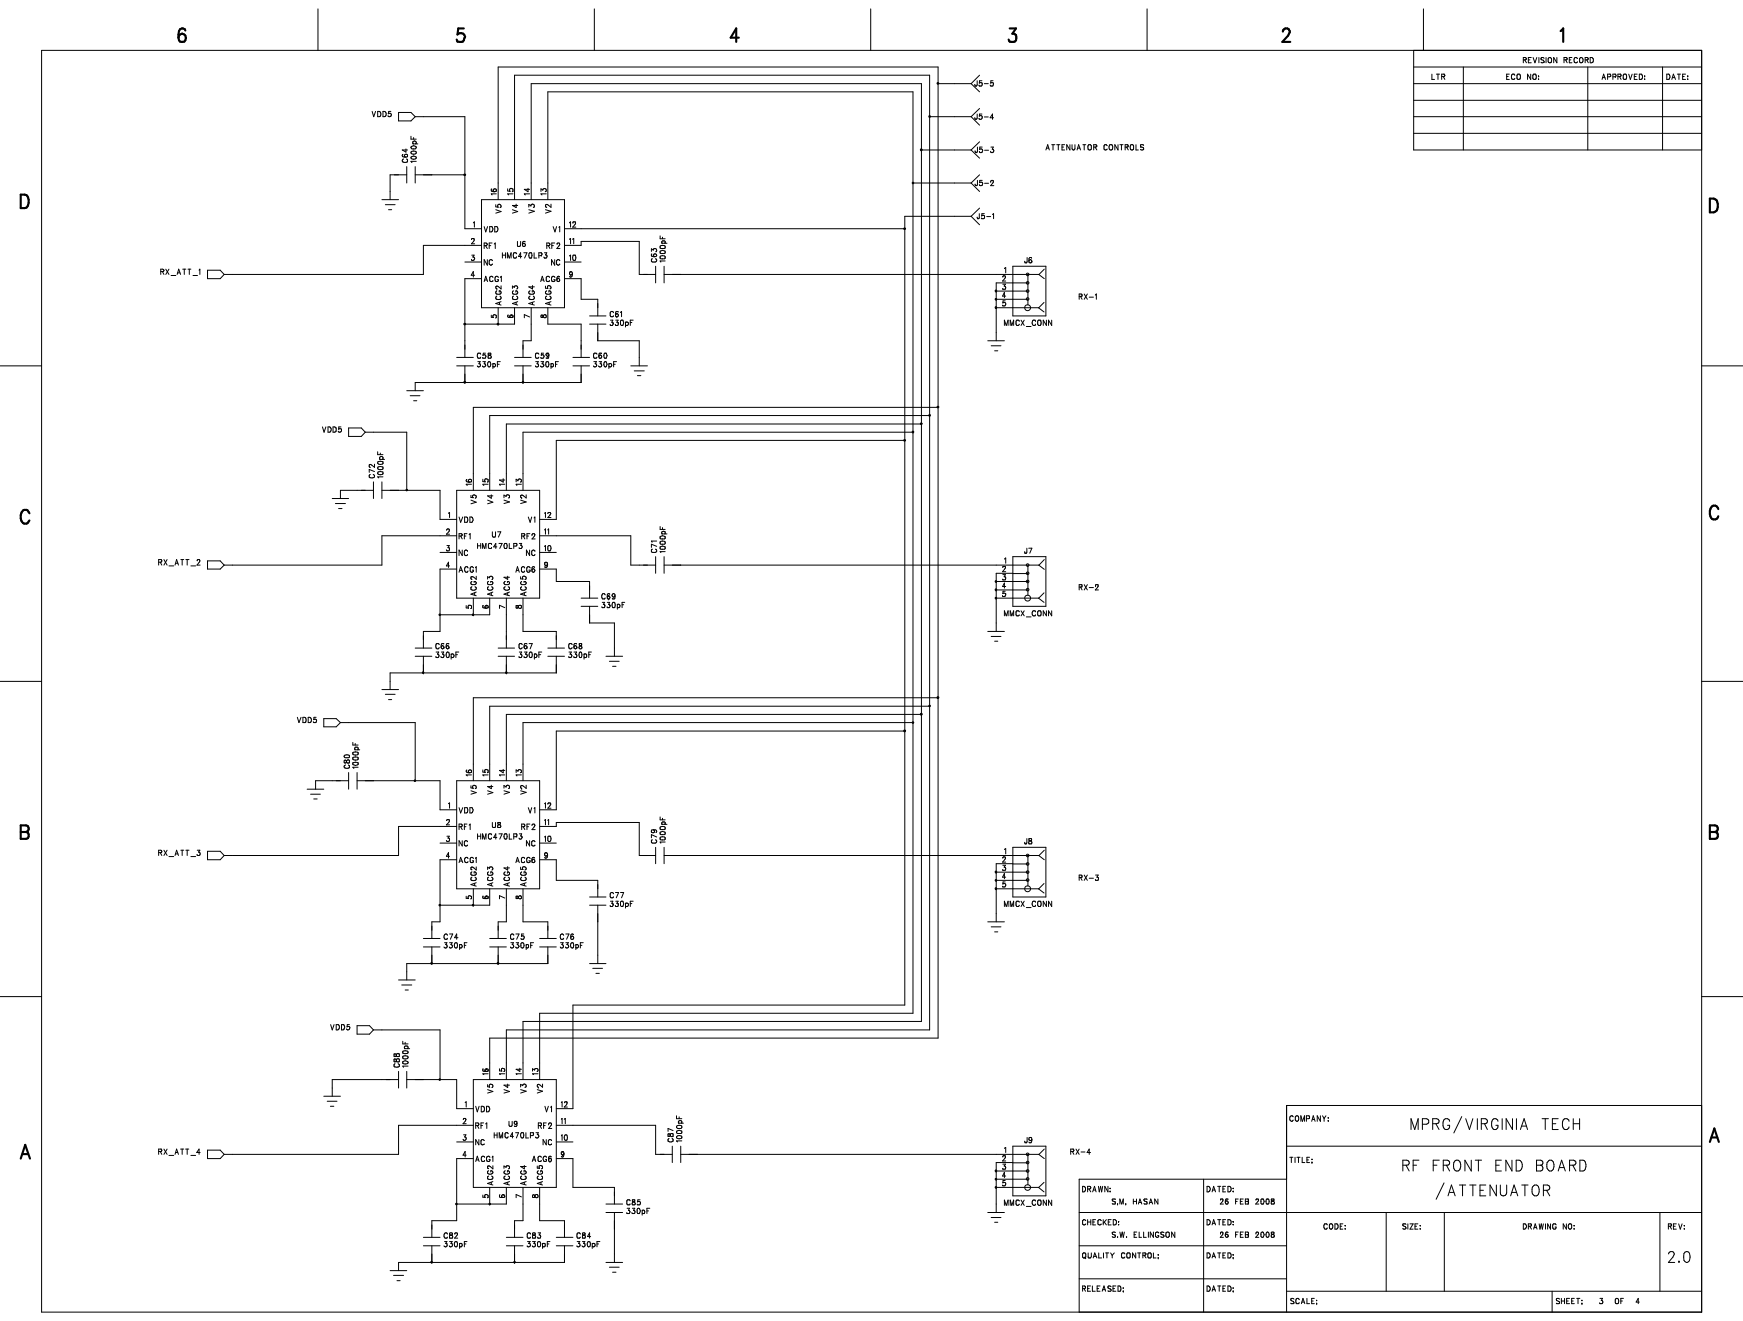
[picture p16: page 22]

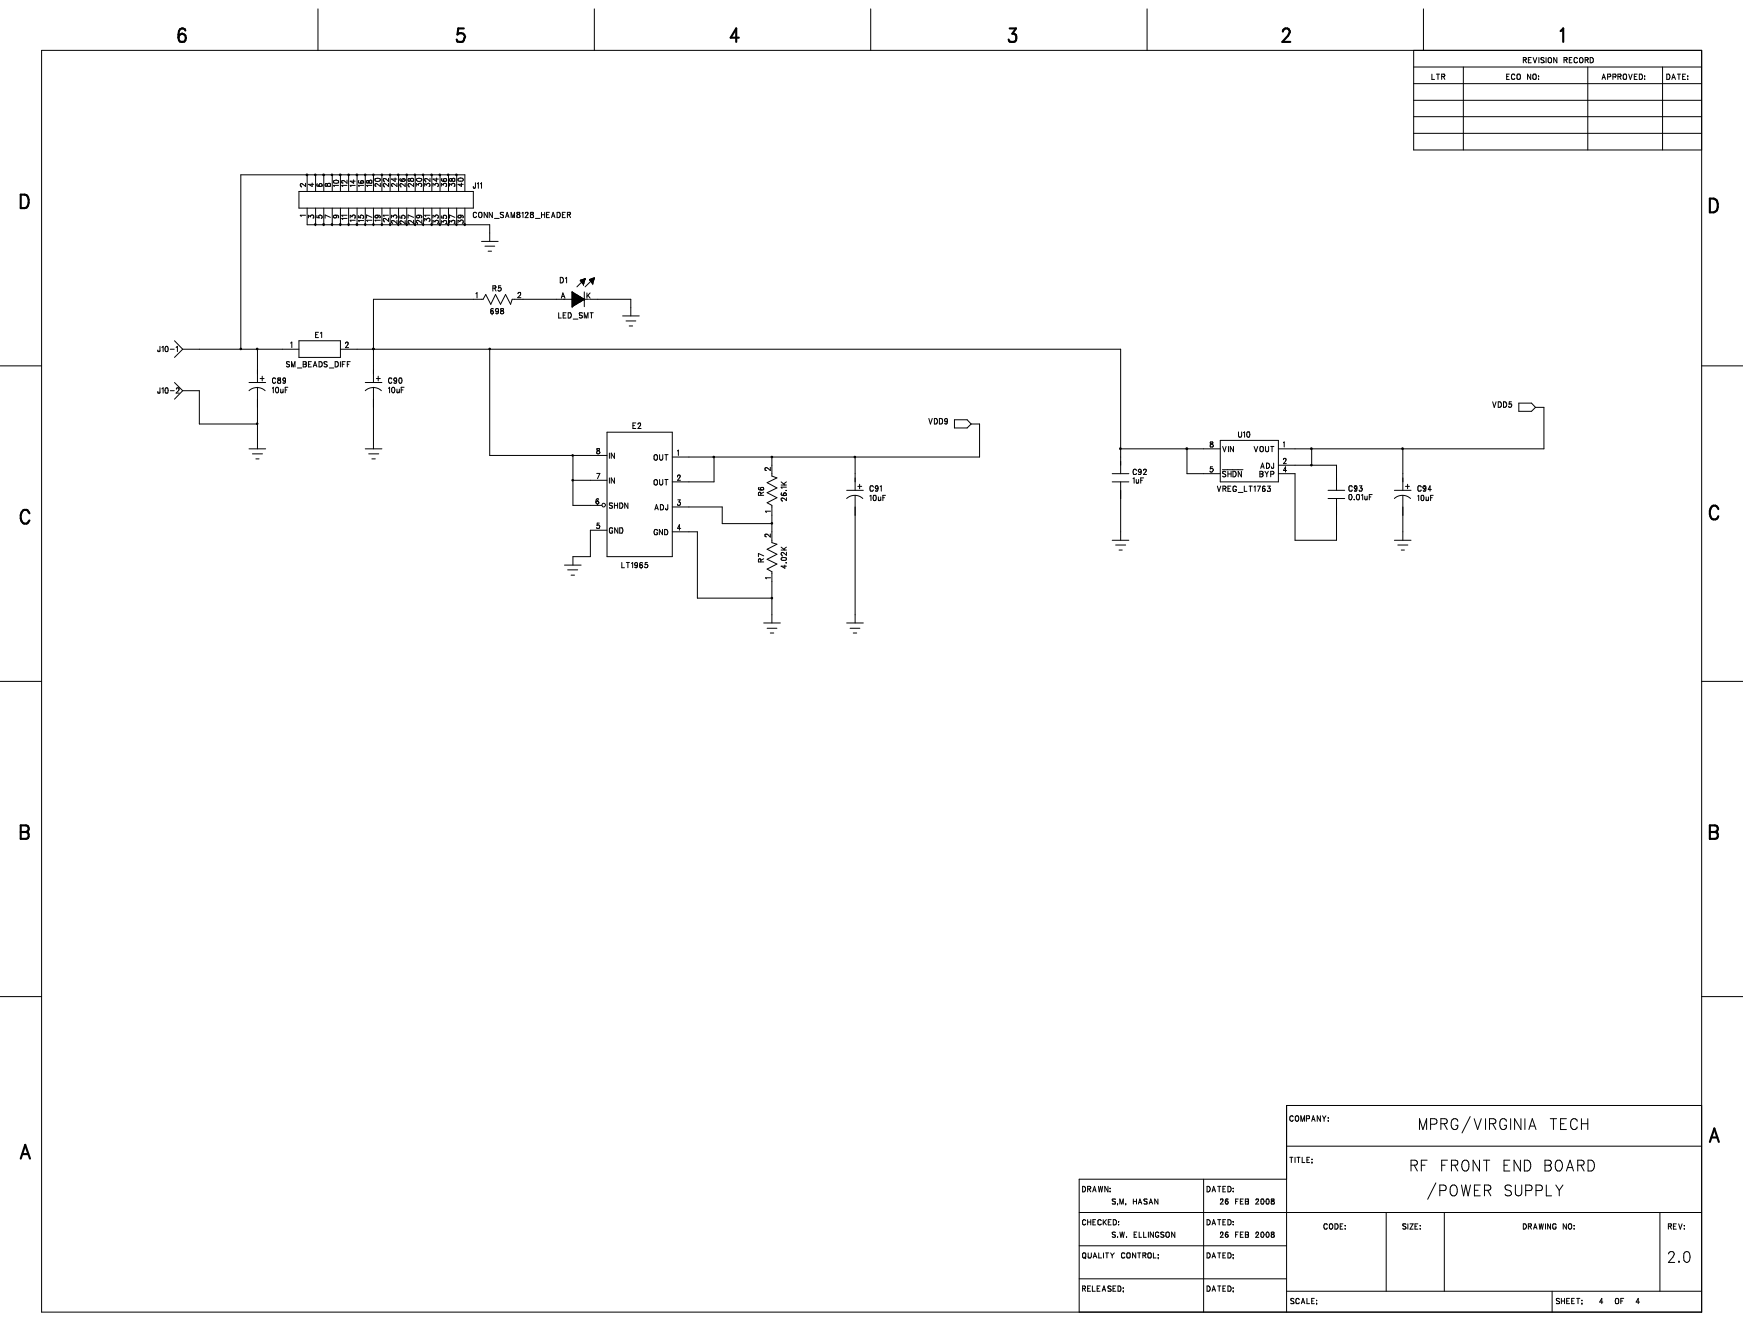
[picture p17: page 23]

## C Layout

This section presents the layout and component placement of the RFFE board. The pages are added in the following order -

- Top layer (primary component side)
- Bottom layer (secondary component side)
- First inner layer (power layer)
- Second inner layer (ground layer)
- Component placement in top layer, and
- Component placement in bottom layer.

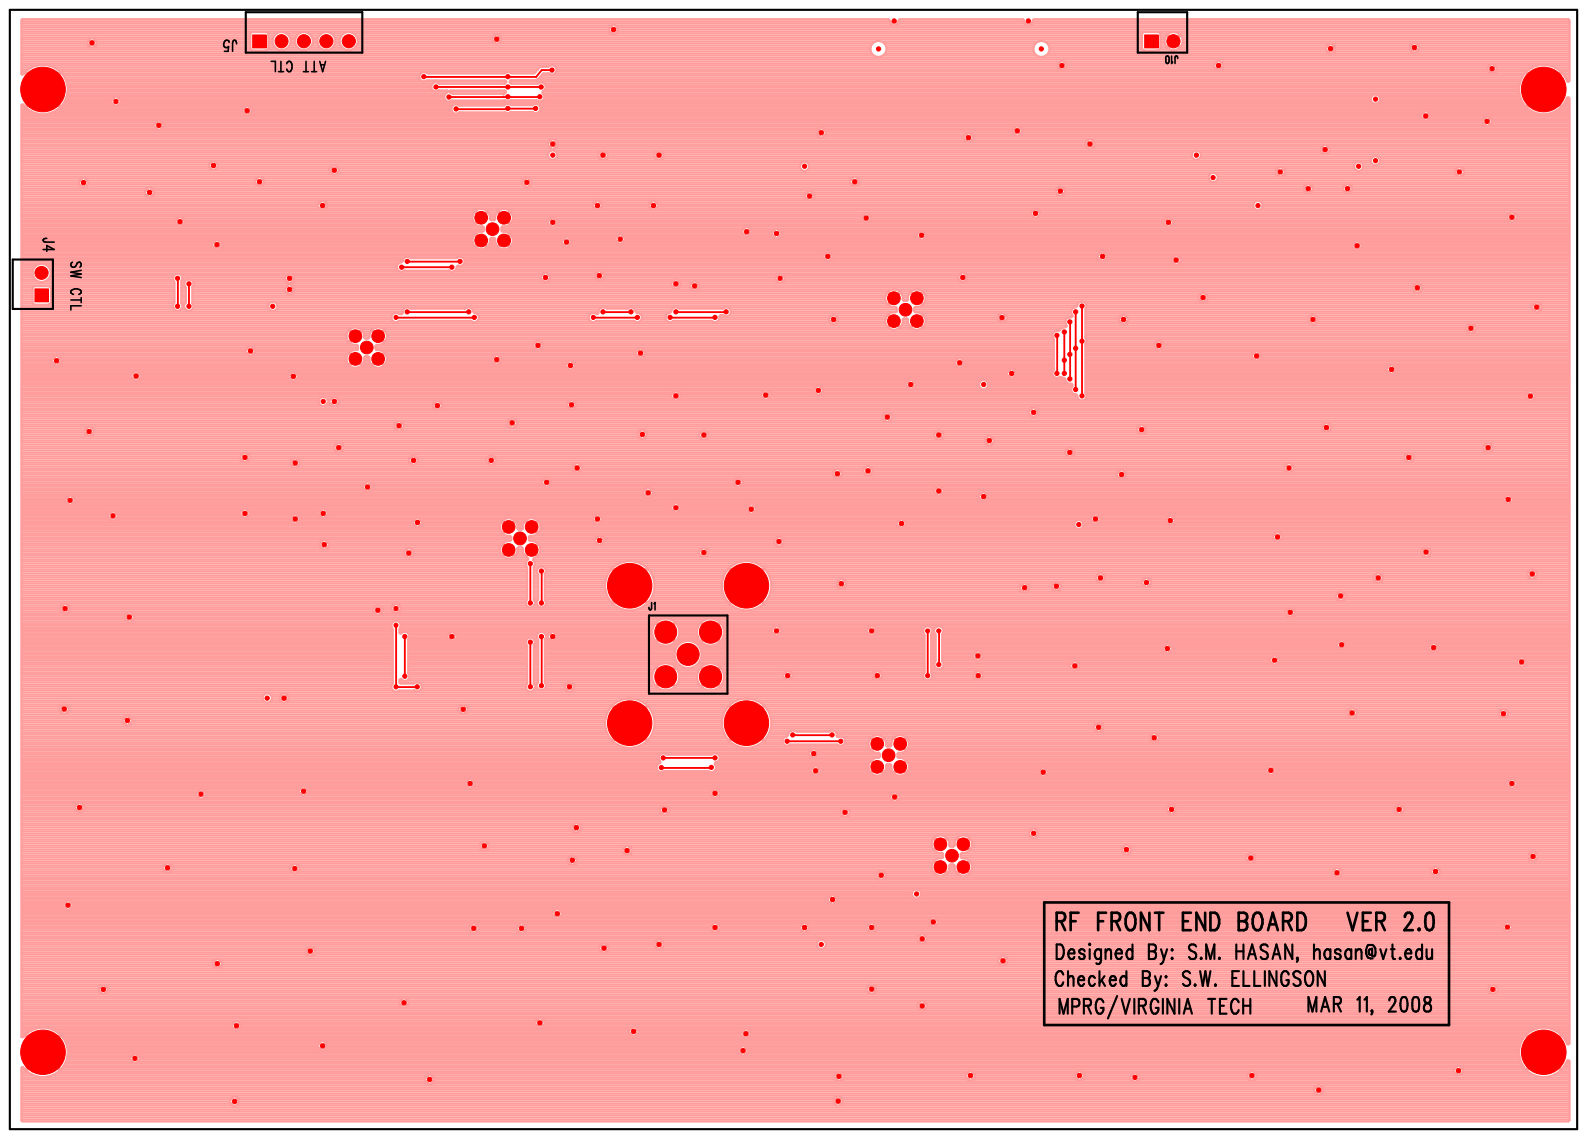
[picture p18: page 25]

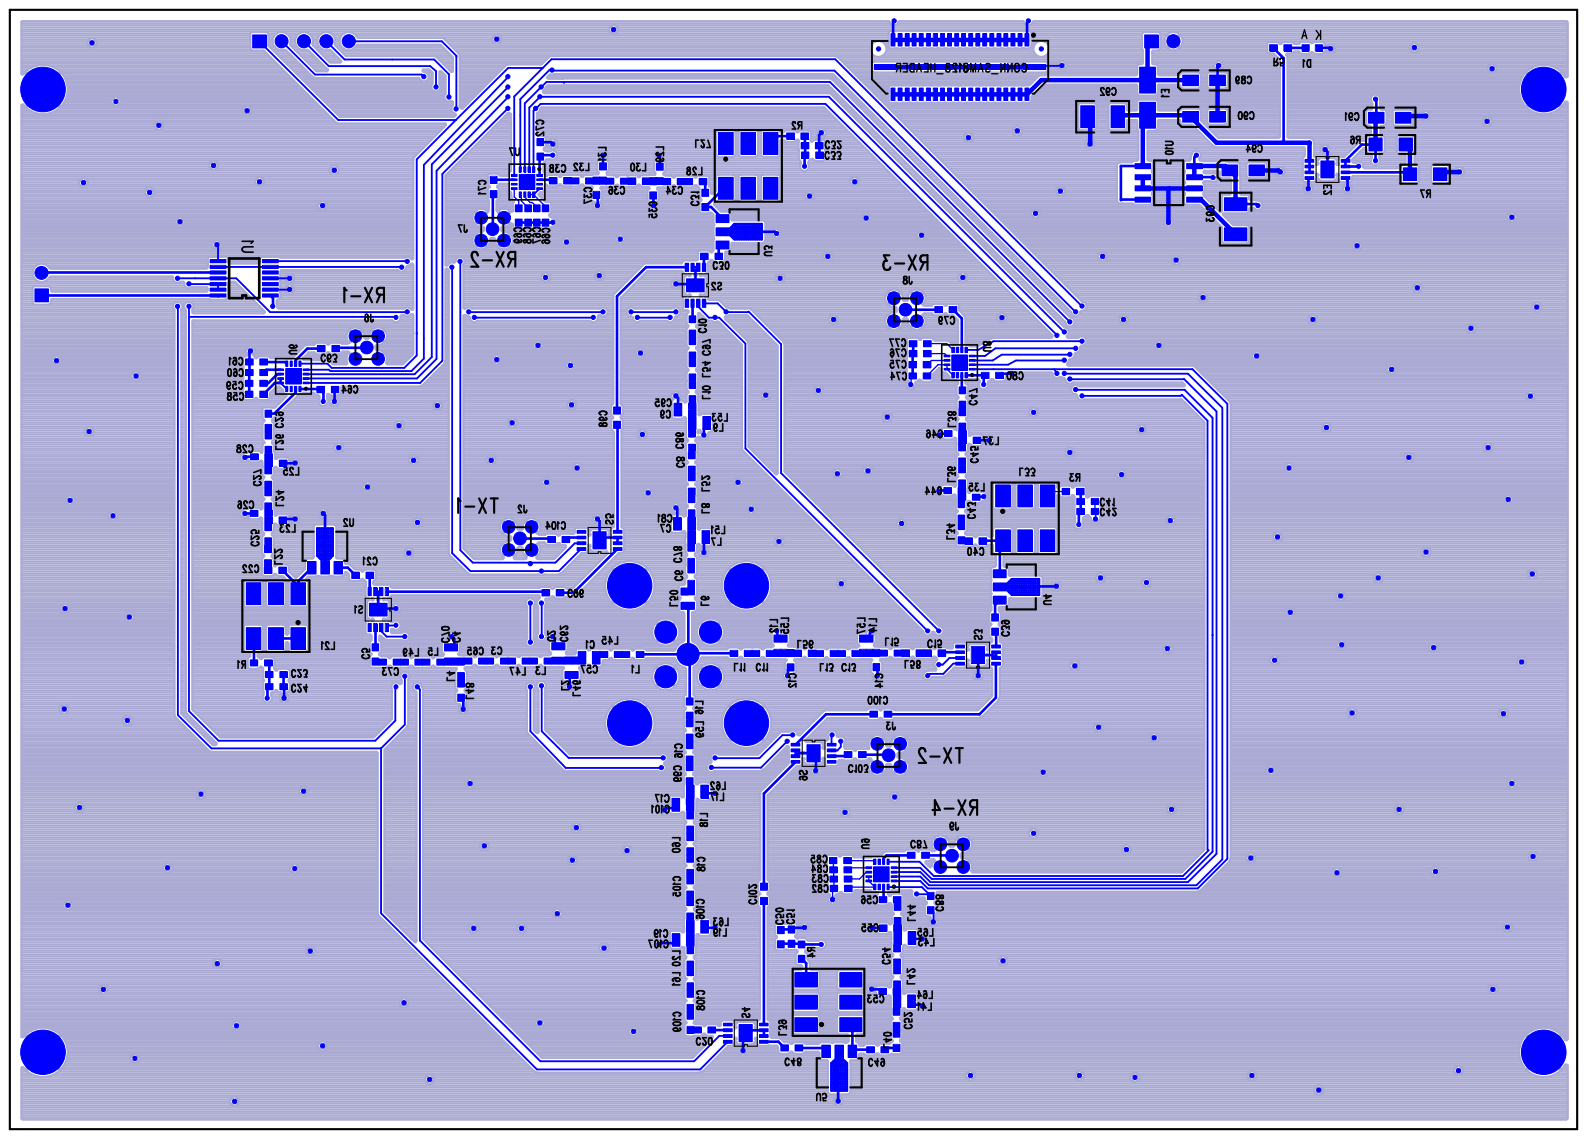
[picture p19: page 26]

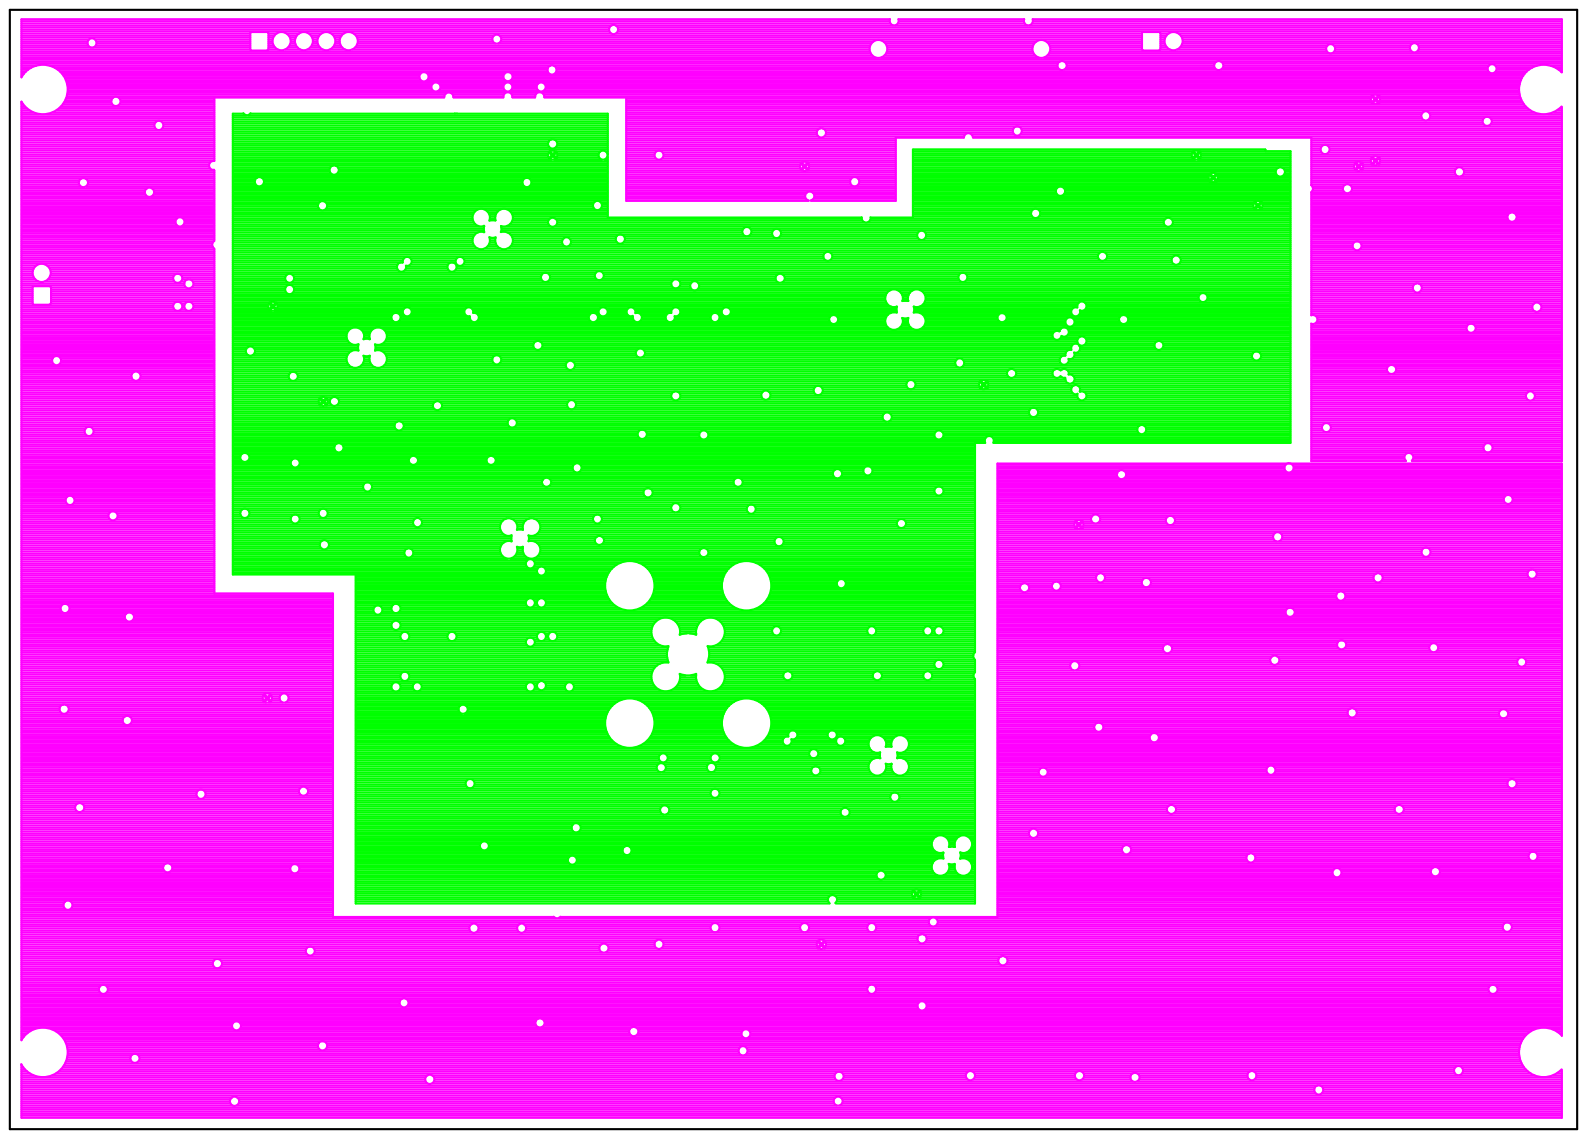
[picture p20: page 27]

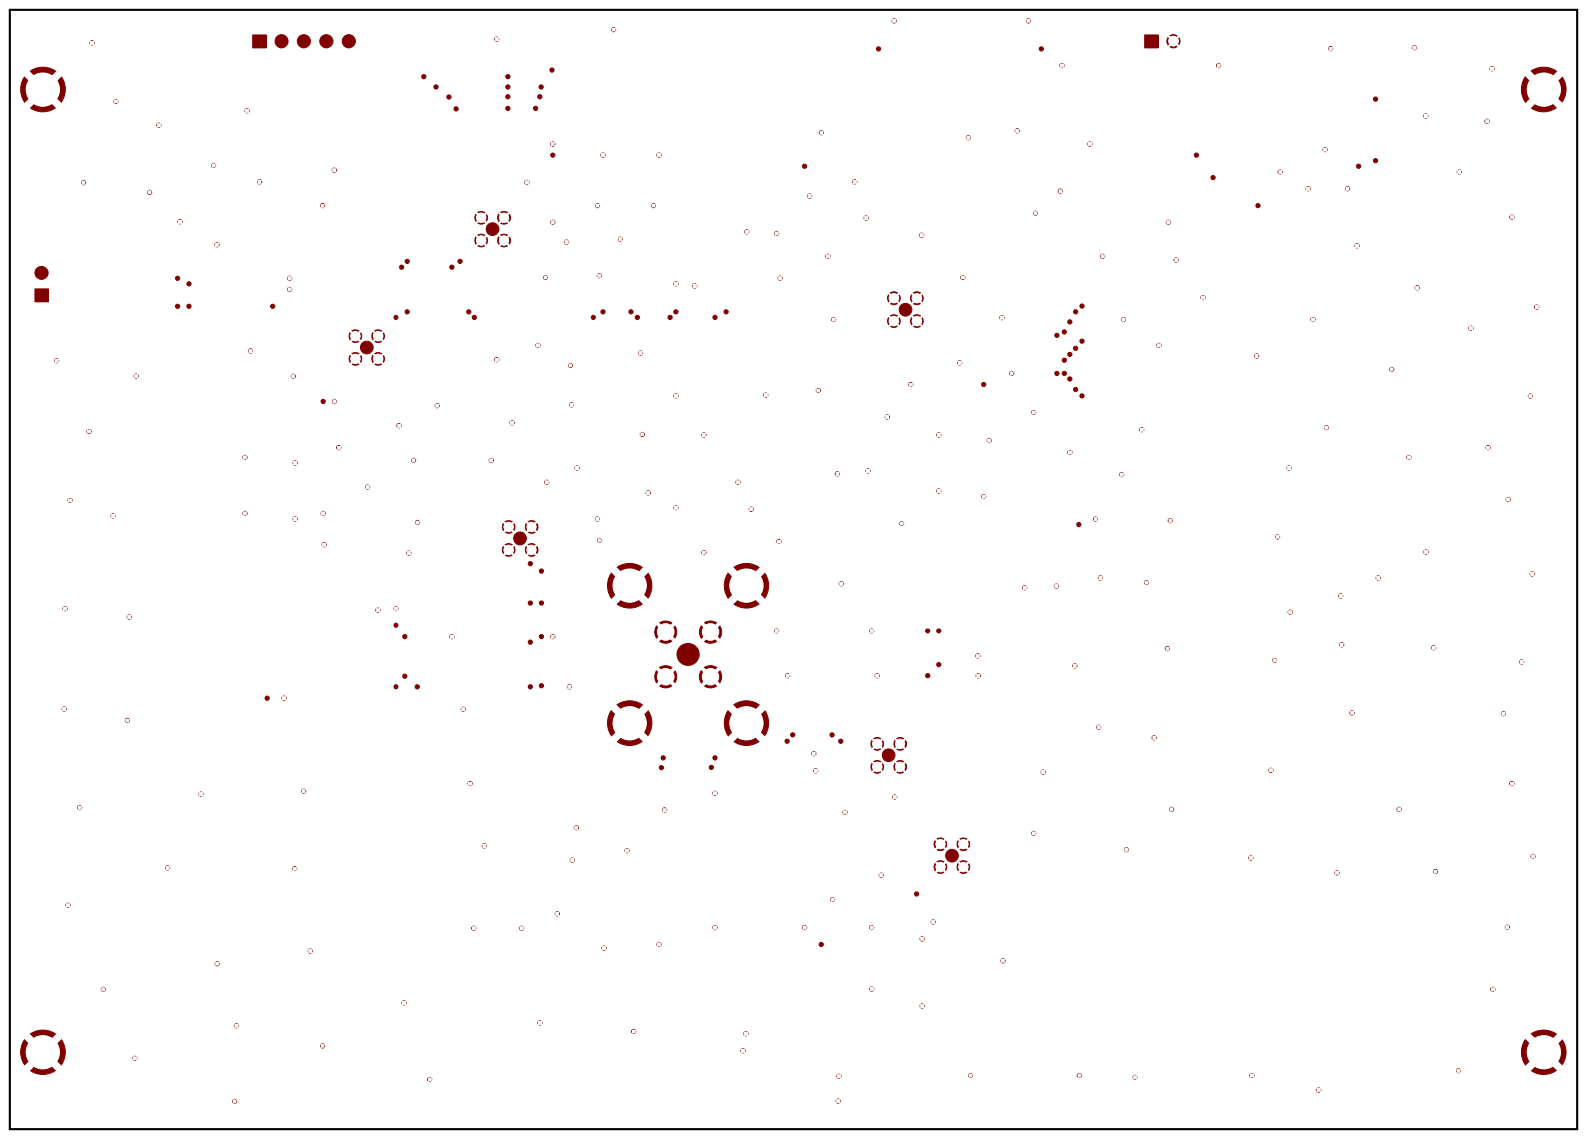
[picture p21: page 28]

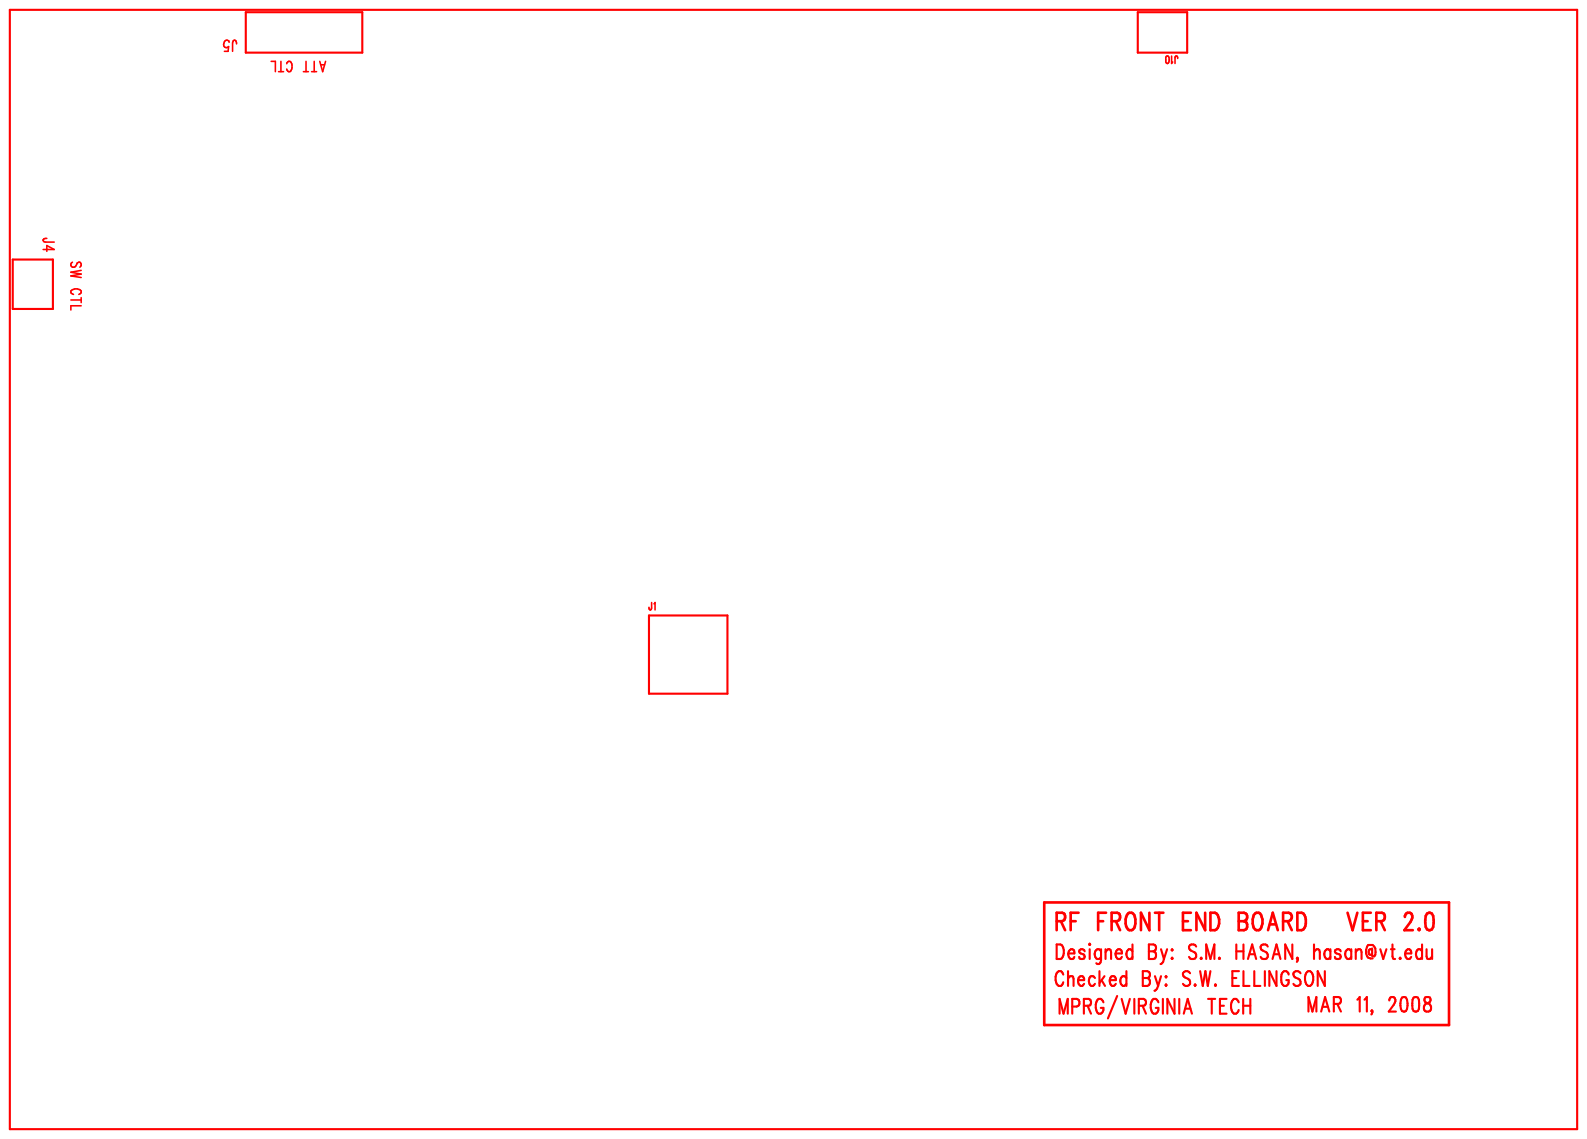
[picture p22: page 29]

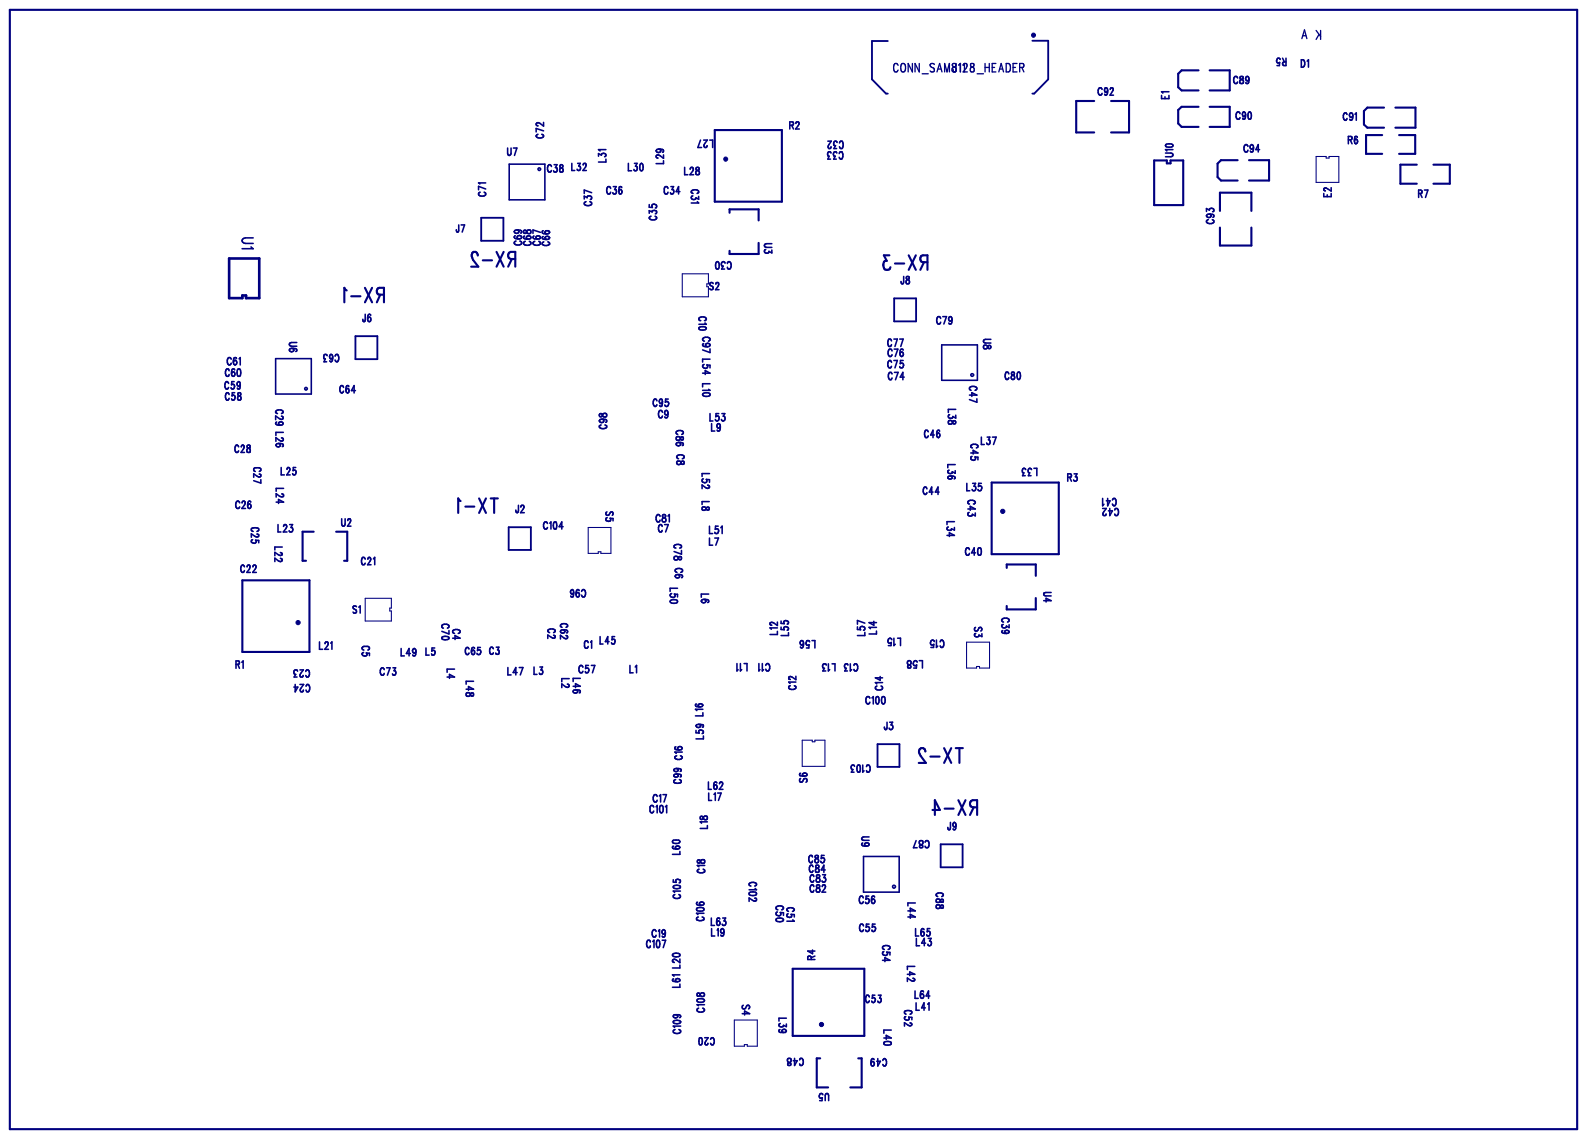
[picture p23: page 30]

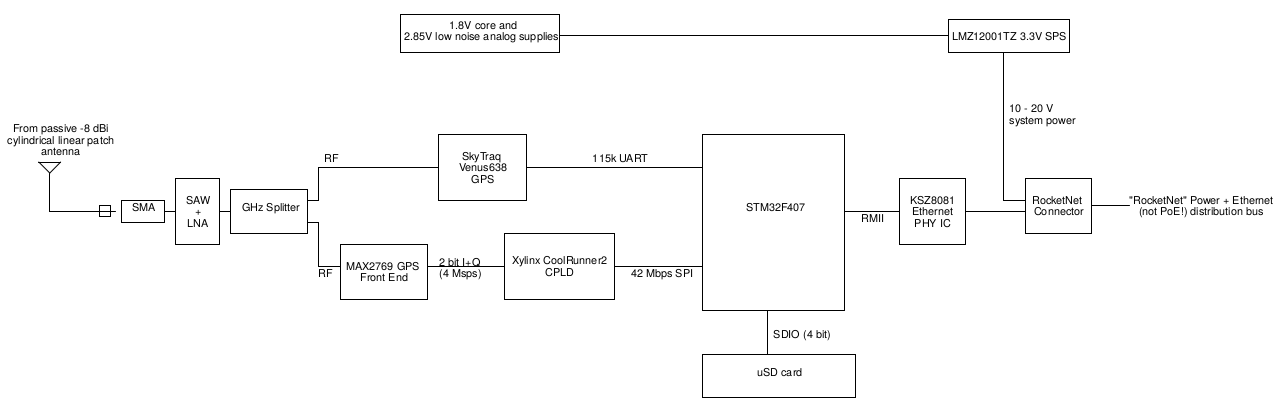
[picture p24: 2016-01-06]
media/gps-v3-block-diagram.png

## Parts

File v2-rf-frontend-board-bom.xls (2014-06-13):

Qty | Parts | Value | Mfg | Device | Package | Description | Digi-Key | Mouser
2 | C29,C30 | 10p | Samsung | CL05C100JB5NNNC | 0402-C-NOSILK |  | 1276-1139-1-ND
1 | C3 | 27p | Samsung | CL05C270JB5NCNC | 0402-C-NOSILK |  | 1276-1671-1-ND
11 | C6,C8,C12,C14,C16,C17,C19,C22,C24, C57,C63 | 100p | Samsung | CL05C101JB5NNNC | 0402-C-NOSILK |  | 1276-1025-1-ND
1 | C4 | 470p | Samsung | CL05C471JB5NNNC | 0402-C-NOSILK |  | 1276-1117-1-ND
1 | C44 | 1n 2kv | TDK | CGA2B3X7S2A102K050BB | 0402-C-NOSILK |  | 445-6904-1-ND
4 | C2,C43,C56,C60 | 10n | Samsung | CL05B103KA5NNNC | 0402-C-NOSILK |  | 1276-1057-1-ND
1 | C26 | 22n | Samsung | CL05B223KA5NNNC | 0402-C-NOSILK |  | 1276-1537-1-ND
27 | C5,C7,C9,C10,C11,C13,C15,C18,C21,C23,C25,C27,C31,C34,C35,C37,C45,C46,C47,C48,C49,C50,C54,C55,C61,C62,C64 | 100n 50V | Samsung | CL05B104KP5NNNC | 0402-C-NOSILK |  | 1276-1002-1-ND
6 | C39,C40,C41,C42,C59,C65 | 1u 50V | Samsung | CL10A105KB8NNNC | 0603-B-NOSILK |  | 1276-1860-1-ND
6 | C20,C36,C53,C58,C51,C52 | 2.2u | Samsung | CL10A225KQ8NNNC | 0603-B-NOSILK |  | 1276-1183-1-ND
1 | C33 | 10u 50V | Samsung | CL31A106KBHNNNE | 1206-C |  | 1276-2876-1-ND
2 | C28,C32 | 22u | Samsung | CL31A226KAHNNNE | 1206-C |  | 1276-3047-1-ND
1 | C38 | 100u | Vishay | TR3C107K010C0100 | EIA6032 |  | 718-1324-1-ND
1 | D2 | - | Comchip | CDBU0520 | 0603-B-NOSILK-DIODE | 500mA diode | 641-1332-1-ND
1 | J1 | - | Samtec | FTSH-105-01-F-D-K | 1.27MM_2X5 | STM32 SWD connector | FTSH-105-01-F-D-K-ND
1 | J2 | - | Emerson | 142-0701-801 | SMA-CON-EMERSON | SMA end-fire connector | J502-ND
1 | J3 | - | Harwin | M50-3500842 | ROCKETNET-M-16 | Rocketnet connector | 952-1385-ND
1 | J4 | - | Hirose | ZX62D-B-5P8 | ZX62D-B-5P8 | MicroUSB connector for debug | H11610CT-ND
1 | J5 | - |  | HEADER-11X02 | HEADER-11X02 | 0.1" 2x11 pin header | --
1 | J6 | - |  | PINHD-1X6 | 1X06 | 0.1" 1x6 pin header | --
1 | J7 | - | Hirose | DM3D-SF | HIROSE_DM3D(MICRO-SD) | MicroSD card connector push/pull | HR1941CT-ND
2 | L1,L4 | 190mOhm | TDK | ACM2012-900-2P-T002 | TDK-ACM2012 | Ethernet common mode choke | 445-2207-1-ND
1 | L2 | 6.2nH | Abracon | AISC-0402-6N2J-T | 0402-C-NOSILK | 6.2 nH 0402 inductor | 535-10433-1-ND
1 | L3 | 10 Ohm | TDK | HF70ACC201209-T | 0805-C-NOSILK | FERRITE CHIP 10 OHM 1.5A | 445-6183-1-ND
1 | L5 | 9.1nH | TDK | MHQ1005P9N1JT000 | 0402-C-NOSILK | 9.1 nH 0402 inductor | 445-9424-1-ND
2 | L6,L8 |  | AVX | SF14-1575F5UU19 | SAW_1.4X1.1 | 1.57542 GHz SAW filter | 478-5246-1-ND |  | NO STOCK ANYWHERE
1 | LED1 | GRN | OSRAM | LEDCHIPLED_0603 | CHIPLED_0603 | Green 0603 LED | 475-1409-1-ND
4 | LED2,LED4,LED5,LED6 | YLW | OSRAM | LEDCHIPLED_0603 | CHIPLED_0603 | Yellow 0603 LED | 475-2558-1-ND
1 | LED3 | RGB | OSRAM | LED_RGB_PLCC-6 | PLCC-6 | TOVA LED | -- |  | NO STOCK ANYWHERE?!
1 | Q1 |  | ON | NTR4101PT1G | SOT23 | MOSFET P-CH 20V 1.8A SOT-23 | NTR4101PT1GOSCT-ND | 863-NTR4101PT1G | NO STOCK ANYWHERE
1 | R40 | 27 | Panasonic | R-US_0402-C-NOSILK | 0402-C-NOSILK |  | P27.0LCT-ND
2 | R38,R39 | 68 | Panasonic | R-US_0402-C-NOSILK | 0402-C-NOSILK |  | P68.0LCT-ND
2 | R10,R11 | 75 | Panasonic | R-US_0402-C-NOSILK | 0402-C-NOSILK |  | P75.0LCT-ND
1 | R13 | 470 | Panasonic | R-US_0402-C-NOSILK | 0402-C-NOSILK |  | P470LCT-ND
8 | R4,R6,R14,R16,R17,R20,R42,R43 | 1k | Panasonic | R-US_0402-C-NOSILK | 0402-C-NOSILK |  | P1.00KLCT-ND
1 | R3 | 1.07k | Panasonic | R-US_0402-C-NOSILK | 0402-C-NOSILK |  | P1.07KLCT-ND
1 | R12 | 1.5k | Panasonic | R-US_0402-C-NOSILK | 0402-C-NOSILK |  | P1.50KLCT-ND
1 | R1 | 3.32k | Panasonic | R-US_0402-C-NOSILK | 0402-C-NOSILK |  | P3.32KLCT-ND
1 | R15 | 6.49k | Panasonic | R-US_0402-C-NOSILK | 0402-C-NOSILK |  | P6.49KLCT-ND
5 | R5,R8,R9,R18,R19 | 10k | Panasonic | R-US_0402-C-NOSILK | 0402-C-NOSILK |  | P10.0KCT-ND
1 | R2 | 20k | Panasonic | R-US_0402-C-NOSILK | 0402-C-NOSILK |  | P20.0KLCT-ND
1 | R7 | 61.9k | Panasonic | R-US_0402-C-NOSILK | 0402-C-NOSILK |  | P61.9KLCT-ND
2 | T1,T2 | 220uH | TDK | ALT4532M-201-T001 | TDK-ALT4532 | Ethernet transformer | 445-15085-1-ND
1 | U1 |  | Maxim | MAX2769ETI+ | 90-0023 | GPS receiver IC | MAX2769ETI+-ND
1 | U2 |  | ST | STM32F407VGT6 | LQFP100 | ARM CORTEX-M4 microcontroller | 497-11605-ND
1 | U3 |  | Micrel | KSZ8081RNDCA TR | QFN-24 | Ethernet PHY IC | 576-4177-1-ND
1 | U4 |  | TXC | 7Q-16.368MBG-T | TCX_7Q | 16.386 MHz TCXO | 887-1548-1-ND
1 | U5 |  | Torex | XC2401A8167R-G | USPN-4B02 | GPS LNA | 893-1155-1-ND
2 | U6,U7 |  | Maxim | MAX8510EXK29+T | SC70 | 2.85V LDO | NON-STOCK
1 | U8 |  | TI | LMZ12001TZ-ADJ/NOPB | TO-PMOD-7 | Monolithic buck DC-DC | LMZ12001TZ-ADJ/NOPBCT-ND
1 | X1 | 25MHz | TXC | 8Y-25.000MEEQ-T | 8Y | 25 MHz SMT crystal | 887-1819-1-ND
122 | TOTAL PARTS (!)

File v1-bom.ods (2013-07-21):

GPS RF Board parts list (v1)
Note
Bought a kit for the resistors and capacitors.
microUSB part shown here is the wrong footprint.
Category | Part | Qty | Unit | P/N | Vendor
Battery | 12mm Coin | 1 | $0.25 | P189-ND | Digikey/Panasonic
Card | microSD | 1 | $37.23 | SFSD1024N1BN1TO-E-DF-151-STD | Digikey/Swissbit
Connector | SMA | 1 | $2.85 | 5-1814832-1 | Digikey/TE Connect
Connector | microSD | 1 | $2.42 | 2908-05WB-MG | Mouser/3M
Connector | 12mm Batt | 1 | $0.55 | 3003K-ND | Digikey/Keystone
IC | MAX2769 | 1 | $4.00 | MAX2769ETI+ | Digikey/Maxim
IC | STM32F407 | 1 | $12.78 | STM32FR07VGT6 | Digikey/STM
IC | USB3318 | 1 | $2.80 | USB3318-CP-TR | Digikey/SMSC
Ind | 33nH | 1 | $0.08 | ELJ-RF33NJFB | Digikey/Panasonic
Voltage Reg | LM1117SOT223 | 2 | $1.10 | LM1117MPX-3.3CT | Digikey/National Semi
Connector | microUSB | 1 | $1.50 | PRT-08533 | Sparkfun
Crystal | CTS406 | 2
Header | 1x14 | 1
Caps (0402) | 4.7uF | 1
Caps (0402) | 2.2uF | 8
Caps (0402) | 1uF | 1
Caps (0402) | 100nF | 5
Caps (0402) | 10nF | 2
Caps (0402) | 6.8nF | 2
Caps (0402) | 470pF | 1
Caps (0402) | 100pF | 14
Caps (0402) | 27pF | 1
Caps (0402) | 16pF | 2
Res (0402) | 0.47nF | 1
Res (0402) | 1.5k | 1
Res (0402) | 10k | 1
Res (0402) | 1k | 3
Res (0402) | 20k | 5
Connector | Molex_CortexM3 | 1

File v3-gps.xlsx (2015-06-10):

Qty | Parts | Value | Description | Mfg | Mfg Part No | Digkey Part No | Other | $/1 | $/10 | $/100 |  | Extended
2 | C29,C30 | 10p | 0402 cap, X7R, 10%, Vw >= 6V | Samsung | CL05C100JB5NNNC | 1276-1139-1-ND |  | 0.1 | 0.0013 | 0.006 |  | 0.6
1 | C3 | 27p | 0402 cap, X7R, 10%, Vw >= 6V | Samsung | CL05C270JB5NCNC | 1276-1671-1-ND |  | 0.1 | 0.0013 | 0.006 |  | 0.3
1 | C81 | 47p | 0402 cap, X7R, 10%, Vw >= 6V | Samsung | CL05C470JB5NNNC | 1276-1699-1-ND |  | 0.1 | 0.0013 | 0.006 |  | 0.3
10 | C6,C8,C12,C14,C16,C17,C22,C57,C63,C80 | 100p | 0402 cap, X7R, 10%, Vw >= 6V | Samsung | CL05C101JB5NNNC | 1276-1025-1-ND |  | 0.1 | 0.0013 | 0.006 |  | 0.039
1 | C1 | 330p | 0402 cap, X7R, 10%, Vw >= 6V | Samsung | CL05C331JB5NNNC | 1276-1685-1-ND |  | 0.1 | 0.0013 | 0.006 |  | 0.3
1 | C4 | 470p | 0402 cap, X7R, 10%, Vw >= 6V | Samsung | CL05C471JB5NNNC | 1276-1117-1-ND |  | 0.1 | 0.0013 | 0.006 |  | 0.3
2 | C44,C62 | 1n 2kv | 0402 cap, X7R, 10%, Vw >= 6V | TDK | CGA2B3X7S2A102K050BB | 445-6904-1-ND |  | 0.1 | 0.072 | 0.033 |  | 0.6
5 | C2,C43,C60,C69 | 10n | 0402 cap, X7R, 10%, Vw >= 6V | Samsung | CL05B103KA5NNNC | 1276-1057-1-ND |  | 0.1 | 0.0013 | 0.006 |  | 0.0195
1 | C26 | 22n | 0402 cap, X7R, 10%, Vw >= 6V | Samsung | CL05B223KA5NNNC | 1276-1537-1-ND |  | 0.1 | 0.0013 | 0.006 |  | 0.3
36 | C5,C7,C9,C10,C11,C13,C15,C18,C21,C23,C24,C27,C31,C34,C35,C37,C45,C46,C47,C48,C49,C50,C54,C55,C56,C61,C64,C70,C71,C72,C73,C74,C77,C78,C82,C83,C84 | 100n | 0402 cap, X7R, 10%, Vw >= 6V | TDK | CGA2B3X7R1H104K050BB | 445-6899-1-ND |  | 0.16 | 0.11 | 0.052 |  | 5.616
1 | C25 | 100n 50V | 0402 cap, X7R, 10%, Vw >= 50V | TDK | CGA2B3X7R1H104K050BB | 445-6899-1-ND |  | 0.16 | 0.11 | 0.052 |  | 0.48
11 | C19,C39,C40,C41,C42,C59,C67,C68,C75,C79 | 1u | 0603 cap, X7R, 10%, Vw >= 6V | Samsung | CL10A105KB8NNNC | 1276-1860-1-ND |  | 0.16 | 0.11 | 0.052 |  | 3.63
1 | C65 | 1u 50V | 0603 cap, X7R, 10%, Vw >= 50V | Samsung | CL10A105KB8NNNC | 1276-1860-1-ND |  | 0.16 | 0.11 | 0.052 |  | 0.48
6 | C20,C36,C51,C52,C53,C58,C76 | 2.2u | 0603 cap, X7R, 10%, Vw >= 6V | Samsung | CL10A225KQ8NNNC | 1276-1183-1-ND |  | 0.12 | 0.87 | 0.0398 |  | 15.66
1 | C33 | 10u 50V | 1206 cap, X7R, 10%, Vw >= 50V | Samsung | CL31A106KBHNNNE | 1276-2876-1-ND |  | 0.65 | 0.624 | 0.303 |  | 1.95
2 | C28,C32 | 22u | 1206 cap, X7R, 10%, Vw >= 6V | Samsung | CL31A226KAHNNNE | 1276-3047-1-ND |  | 0.83 | 0.791 | 0.384 |  | 4.98
1 | C38 | 100u | 2312 cap, Tant, 10%, 10V | Vishay | TR3C107K010C0100 | 718-1324-1-ND |  | 1.44 | 1.18 | 0.95 |  | 4.32
1 | C85 | 330m | 330 mF supercap | Elna | DSK-3R3H334T-HL | 604-1160-1-ND |  | 2.52 | 2.089 | 1.84 |  | 7.56
2 | D1,D2 | - | 0603 500mA schottky | Comchip | CDBU0520 | 641-1332-1-ND |  | 0.47 | 0.331 | 0.217 |  | 2.82
1 | J1 | - | 0.050" 2x5 SWD connector | Samtec | FTSH-105-01-F-D-K | FTSH-105-01-F-D-K-ND | STOCK? | 2.89 | 2.89 | 2.89 |  | 8.67
1 | J2 | - | SMA end-fire connector | Emerson | 142-0701-801 | J502-ND |  | 5.09 | 4.53 | 3.33 |  | 15.27
1 | J3 | - | Rocketnet connector (0.050" 2x8) | Harwin | M50-3500842 | 952-1385-ND |  | 1.47 | 1.33 | 1.145 |  | 4.41
1 | J4 | - | MicroUSB connector for debug | Hirose | ZX62D-B-5P8 | H11610CT-ND |  | 1.2 | 1.059 | 0.912 |  | 3.6
1 | J7 | - | MicroSD card connector push/pull | Hirose | DM3D-SF | HR1941CT-ND |  | 1.88 | 1.7 | 1.46 |  | 5.64
1 | JP1 | - | 0.1" 1x6 pin header | Harwin | M20-9990645 | 952-2269-ND |  | 0.26 | 0.244 | 0.169 |  | 0.78
2 | L1,L4 | - | Ethernet common mode choke | TDK | ACM2012-900-2P-T002 | 445-2207-1-ND |  | 0.5 | 0.448 | 0.336 |  | 3
1 | L3 | - | 0805 ferrite 10 OHM 1.5A | TDK | HF70ACC201209-T | 445-6183-1-ND |  | 0.25 | 0.193 | 0.124 |  | 0.75
1 | L8 | - | L band saw filter | AVX | SF14-1575F5UU19 | 478-5246-2-ND | STOCK? |  |  |  |  | 0
1 | L5 | 1.8n | L-US0402-B-NOSILK | Panasonic | ELJ-RF1N8DFB | PCD1926CT-ND |  | 0.08 | 0.074 | 0.065 |  | 0.24
1 | L2 | 22n | L-US0402-B-NOSILK | Murata | LQW15AN22NJ00D | 490-1150-1-ND |  | 0.32 | 0.286 | 0.206 |  | 0.96
1 | LED1 | GREEN | Green 0603 LED | Kingbright | APT1608SGC | 754-1121-1-ND |  | 0.16 | 0.117 | 0.085 |  | 0.48
5 | LED2,LED4,LED5,LED6,LED7 | YLW | Yellow 0603 LED | Kingbright | APT1608YC | 754-1125-1-ND |  | 0.16 | 0.117 | 0.085 |  | 1.755
1 | LED3 | SMLV56RGB1W1 | RGB LED | Rohm | SMLV56RGB1W1 | 846-1000-1-ND |  | 2.2 | 1.76 | 1.22 |  | 6.6
1 | Q1 | NTR4101P | NTR4101P | ON | NTR4101PT1G | NTR4101PT1GOSCT-ND |  | 0.45 | 0.317 | 0.208 |  | 1.35
1 | R13 | 10 | 0402 1% resistor | Panasonic | ERJ-2RKF10R0X | P10.0LCT-ND |  | 0.1 | 0.019 | 0.015 |  | 0.3
2 | R10,R11 | 75 | 0402 1% resistor | Panasonic | ERJ-2RKF75R0X | P75.0LCT-ND |  | 0.1 | 0.019 | 0.015 |  | 0.6
6 | R4,R6,R17,R23,R24,R42,R43 | 1k | 0402 1% resistor | Panasonic | ERJ-2RKF1001X | P1.00KLCT-ND |  | 0.1 | 0.019 | 0.015 |  | 0.342
1 | R3 | 1.07k | 0402 1% resistor | Panasonic | ERJ-2RKF1071X | P1.07KLCT-ND |  | 0.1 | 0.019 | 0.015 |  | 0.3
7 | R1,R14,R16,R20,R38,R39,R40 | 3.32k | 0402 1% resistor | Panasonic | ERJ-2RKF3321X | P3.32KLCT-ND |  | 0.1 | 0.019 | 0.015 |  | 0.399
1 | R25 | 4.7k | 0402 1% resistor | Panasonic | ERJ-2RKF4701X | P4.70KLCT-ND |  | 0.1 | 0.019 | 0.015 |  | 0.3
1 | R15 | 6.49k | 0402 1% resistor | Panasonic | ERJ-2RKF6491X | P6.49KLCT-ND |  | 0.1 | 0.019 | 0.015 |  | 0.3
11 | R5,R8,R9,R12,R18,R19,R22,R26,R27 | 10k | 0402 1% resistor | Panasonic | ERJ-2RKF1002X | P10.0KLCT-ND |  | 0.1 | 0.019 | 0.015 |  | 0.627
1 | R2 | 20k | 0402 1% resistor | Panasonic | ERJ-2RKF2002X | P20.0KLCT-ND |  | 0.1 | 0.019 | 0.015 |  | 0.3
1 | R21 | 33k | 0402 1% resistor | Panasonic | ERJ-2RKF3302X | P33.0KLCT-ND |  | 0.1 | 0.019 | 0.015 |  | 0.3
1 | R7 | 61.9k | 0402 1% resistor | Panasonic | ERJ-2RKF6192X | P61.9KLCT-ND |  | 0.1 | 0.019 | 0.015 |  | 0.3
1 | SH1 | BMI-S-202-SHIELD | RF shield with removable cover | Laird Technologies | BMI-S-202-F | 903-1051-1-ND |  | 1.79 | 1.58 | 1.25 |  | 5.37
1 | SH1 | BMI-S-202-SHIELD | Removable cover for RF shield | Laird Technologies | BMI-S-202-C | 903-1014-ND |  | 1.38 | 12.26 | 0.969 |  | 4.14
2 | T1,T2 | ALT4532 | Mini Ethernet transformer | TDK | ALT4532M-201-T001 | 445-15085-1-ND |  | 1.49 | 1.19 | 0.92 |  | 8.94
1 | U1 | MAX2769 | GPS receiver Front End | Maxim | MAX2769ETI+ | MAX2769ETI+T-ND | Mouser 700-MAX2769ETI+ | 7.15 | 6.5 | 4.88 |  | 21.45
1 | U2 | STM32F407VG | CORTEX-M4 uC, 100 pin LQFP | ST | STM32F407VGT6 | 497-11605-ND |  | 12.78 | 11.622 | 9.878 |  | 38.34
1 | U3 | KSZ8081 | Ethernet PHY | Micrel | KSZ8081RNDCA TR | 576-4177-1-ND |  | 1.52 | 13.4 | 1.0584 |  | 4.56
1 | U4 | 7Q-16.368MBG-T | 16.386Mhz TCXO, ? PPM | TXC | 7Q-16.368MBG-T | 887-1548-1-ND |  | 3.58 | 3.402 | 2.899 |  | 10.74
1 | U5 | LT1719S6 | Fast push/pull comparator | Linear | LT1719CS6#TRMPBF | LT1719CS6#TRMPBFCT-ND |  | 3.49 | 3.11 | 2.8 |  | 10.47
3 | U6,U7,U11 | MAX8510EXK29+T | 2.85V low noise LDO | Maxim | MAX8510EXK29+T | MAX8510EXK29+TCT-ND |  | 1.22 | 1.15 | 0.803 |  | 10.98
1 | U8 | LMZ12001TZ-ADJ/NOPB | Monolithic buck DC-DC | TI | LMZ12001TZ-ADJ/NOPB | LMZ12001TZ-ADJ/NOPBCT-ND |  | 7.92 | 7.7 | 7.05 |  | 23.76
1 | U9 | VENUS838FLPX-L | Single chip GPS COTS receiver | SkyTraq | Venus838FLPx-L | - | Tindie's Smokingresistor | 39.95 | 35.96 | 31.96 |  | 119.85
1 | U10 | BP2G+ | L band splitter | Minicircuits | BP2G+ | - | MiniCircuits BP2G+ | 0.96 | 0.96 | 0.96 |  | 2.88
1 | U12 | ALM-GP003 | L band SAW filter + LNA | Avago | ALM-GP003-BLKG | - | Mouser 630-ALM-GP003-BLKG | 3.59 | 2.88 | 2.44 |  | 10.77
1 | U13 | XC2C64A-5VQG44C | CPLD | Xilinx | XC2C64A-5VQG44C | 122-1420-ND |  | 1.25 | 1.25 | 1.25 |  | 3.75
1 | U14 | MIC5319-1.8YD5 | 1.8V LDO | Micrel | MIC5319-1.8YD5 | 576-2864-1-ND | STOCK? | 2.71 | 2.45 | 1.97 |  | 8.13
1 | X1 | 25 MHz | 25 Mhz SMT crystal, 20ppm | TXC | 8Y-25.000MEEQ-T | 887-1819-1-ND |  | 1.89 | 1.81 | 1.512 |  | 5.67
 |  |  |  |  |  |  |  |  |  |  | TOTAL | $397.63
Boards to manufacture: |  |  | 3

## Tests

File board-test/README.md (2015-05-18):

####Here lies the scattered remains of tools that may have been used to test board functionality.

* max2769-bit_density.py
  * Take a bitstream received from the max2769 and count bits.  Based on GAINREF configuration, we should see about 33% magnitude bit density.

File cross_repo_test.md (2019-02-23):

---
title: GPS SDR
layout: default
nav_data:
  - name: ADCS
    link: /OreSat_Review/Design/ADCS/
    defcolor: red
---

This markdown is in psas/gps-rf-board repo.  We can link to other stuff there like the [README](readme.mdwn).

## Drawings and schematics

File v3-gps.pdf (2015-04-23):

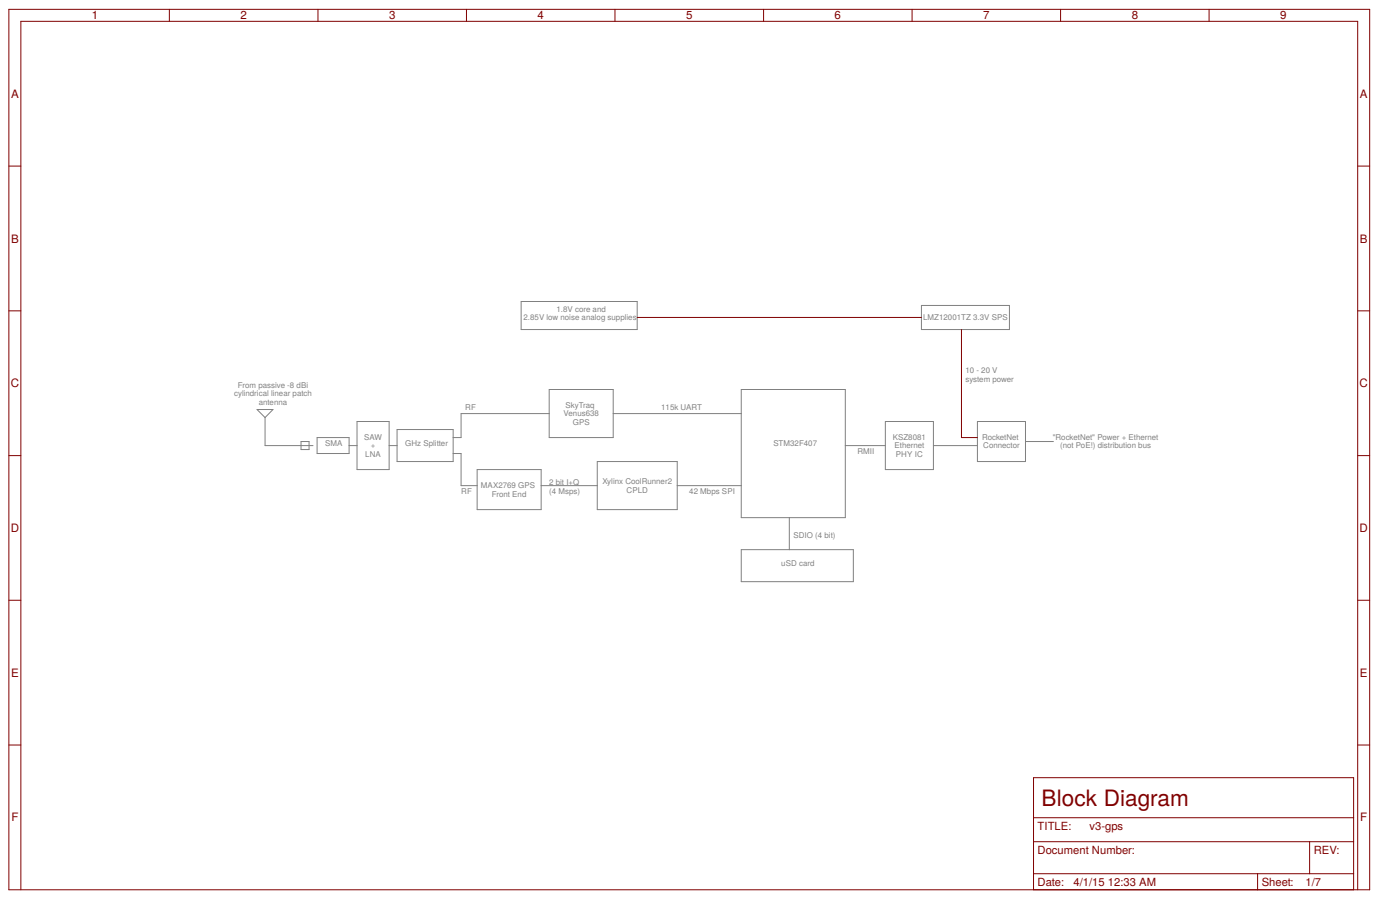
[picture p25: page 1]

2.85V low noise analog supplies

From passive -8 dBi cylindrical linear patch
antenna

(4 Msps) GHz Splitter RF

"RocketNet" Power + Ethernet (not PoE!) distribution bus

SDIO (4 bit) uSD card

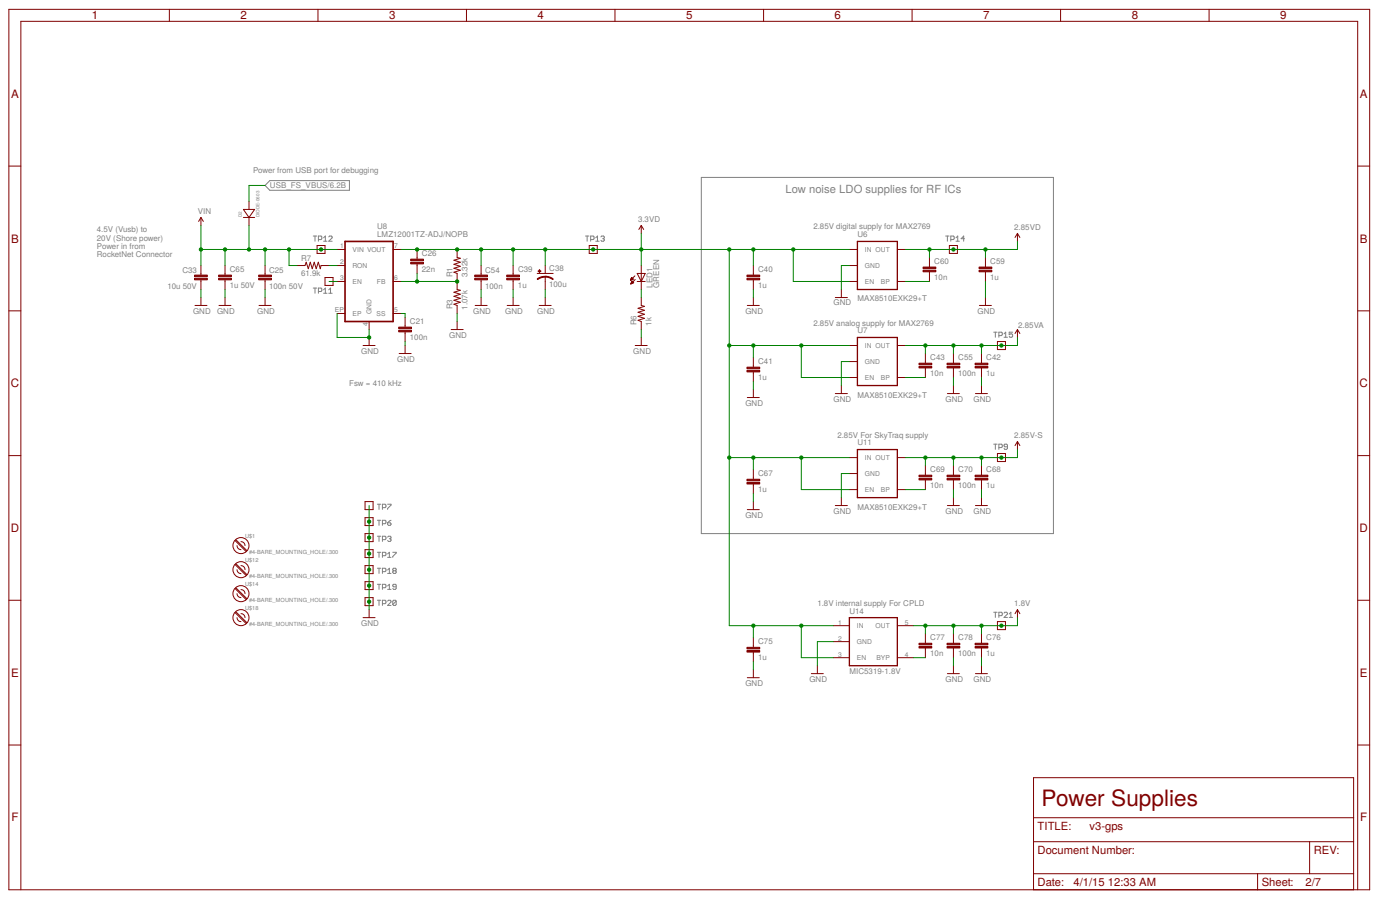
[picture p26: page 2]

Power from USB port for debugging
USB_FS_VBUS/6.2B

Low noise LDO supplies for RF ICs

4.5V (Vusb) to
20V (Shore power) Power in from

1.8V internal supply For CPLD

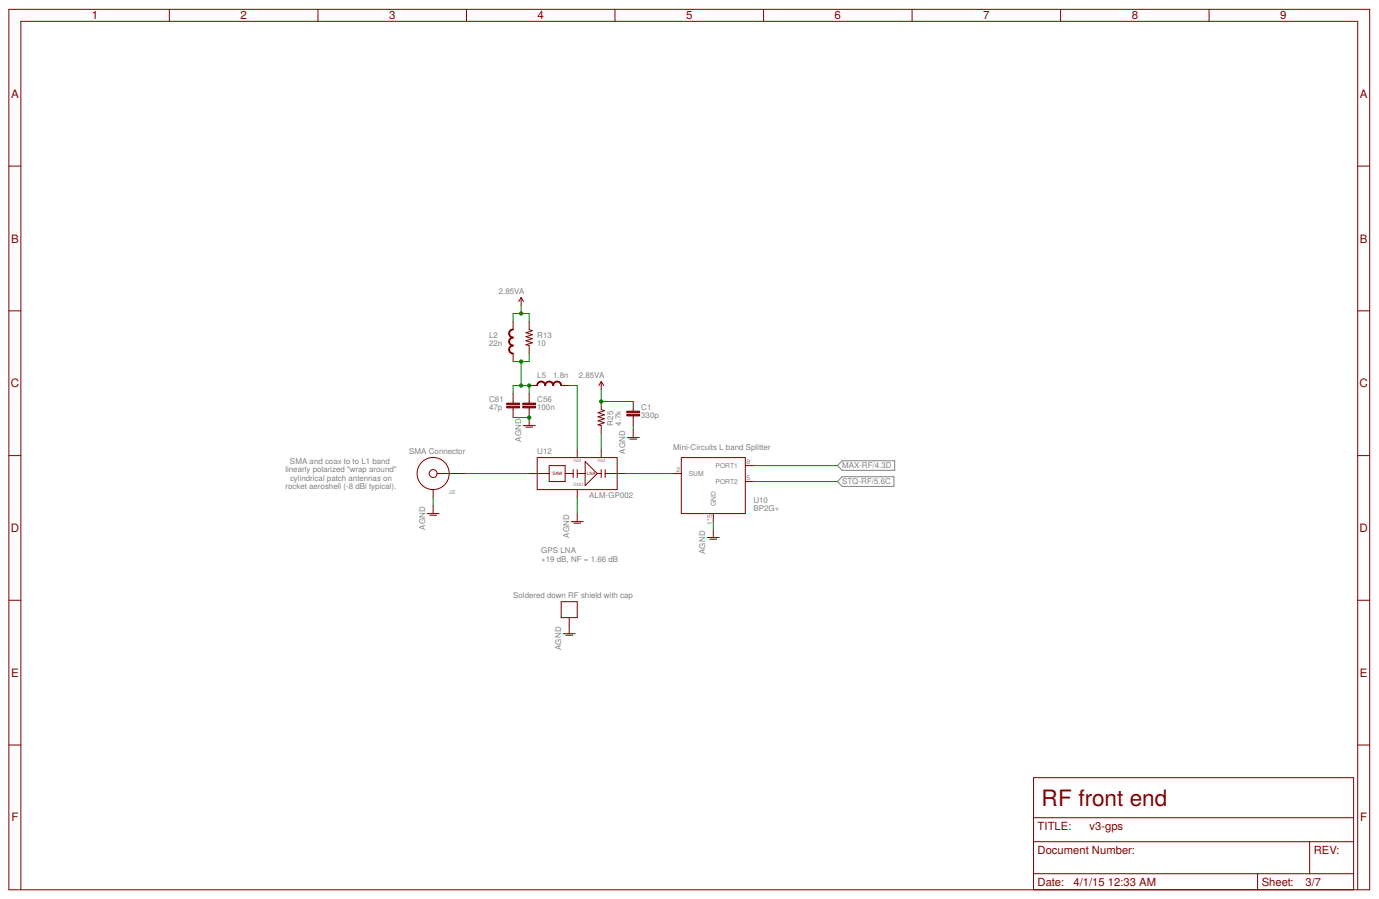
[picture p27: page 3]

Mini-Circuits L band Splitter

SMA and coax to to L1 band
linearly polarized "wrap around" cylindrical patch antennas on
rocket aeroshell (-8 dBi typical).

STQ-RF/5.6C MAX-RF/4.3D

Soldered down RF shield with cap

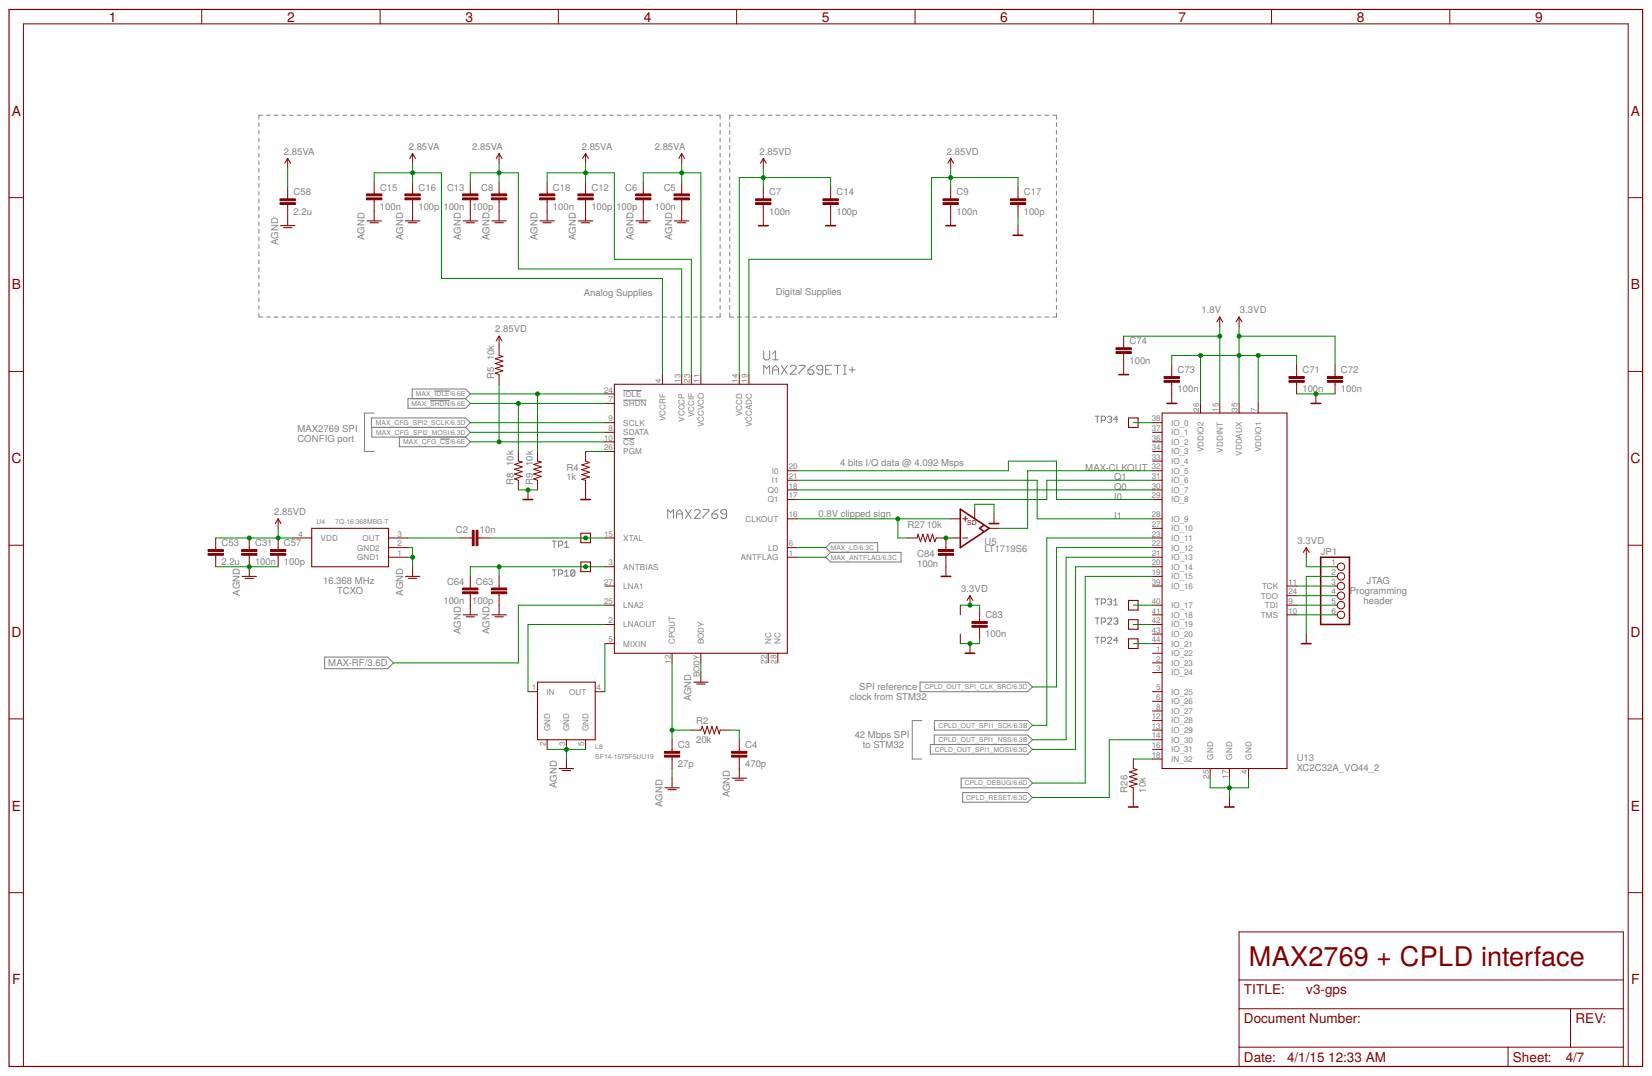
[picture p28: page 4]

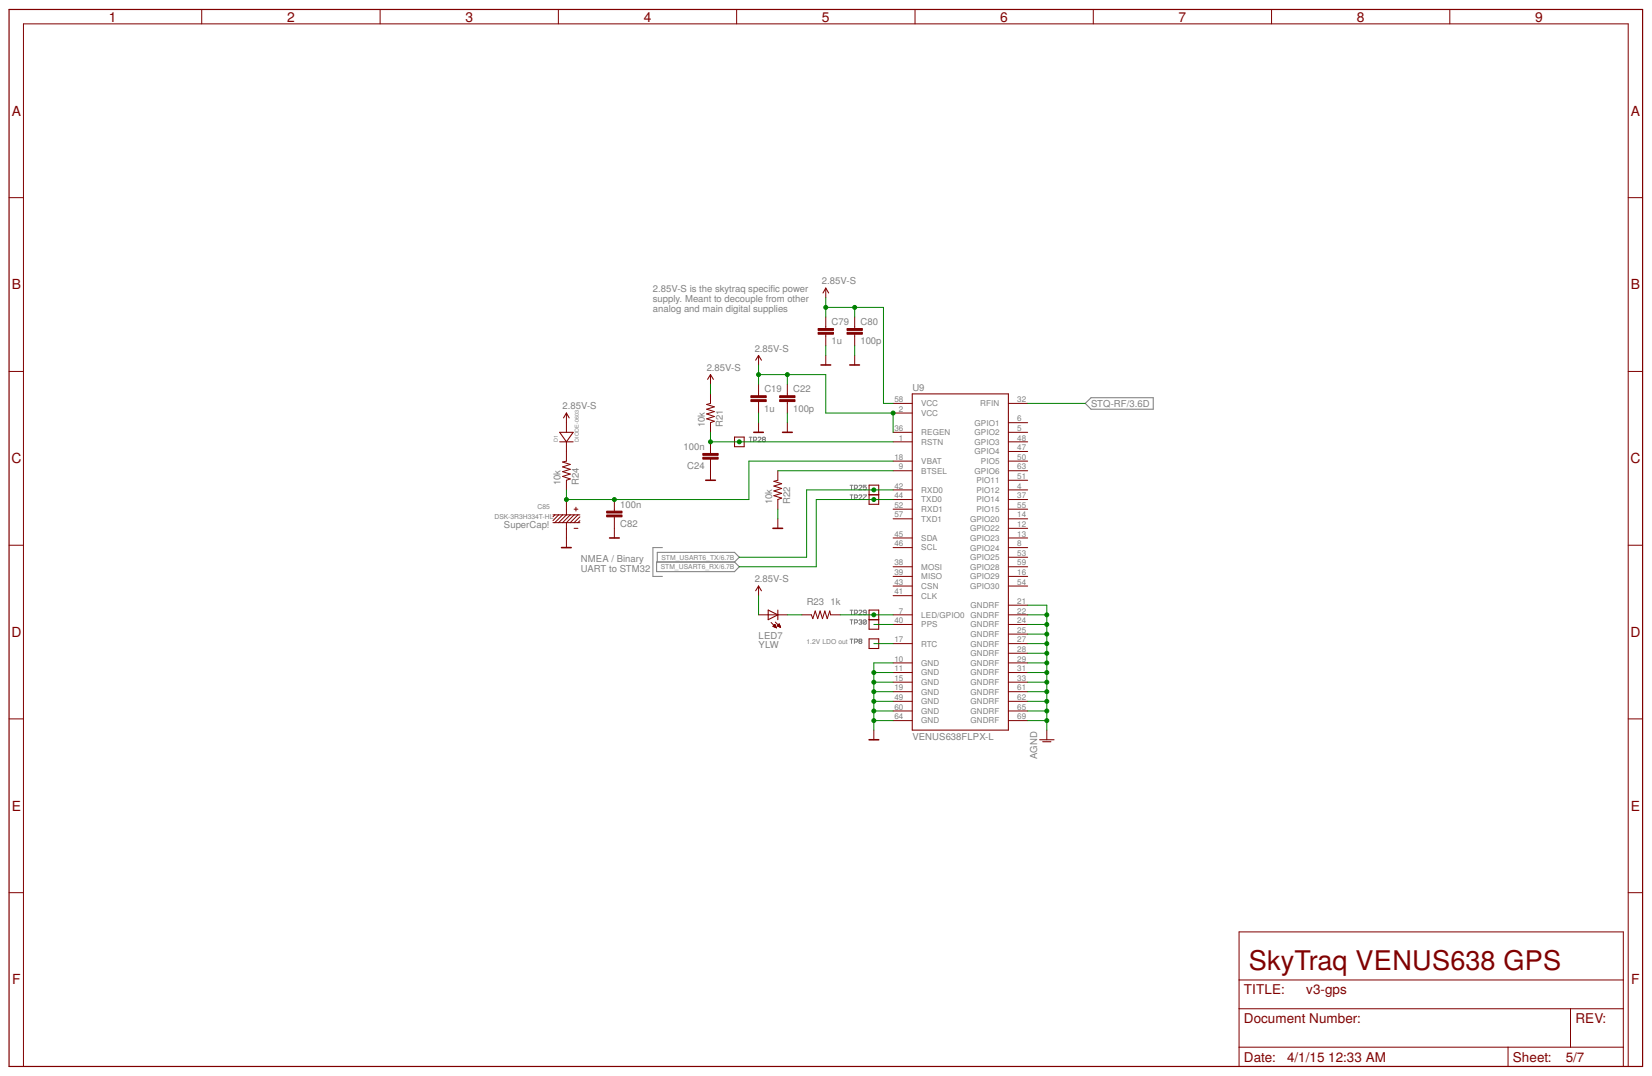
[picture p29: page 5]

2.85V-S is the skytraq specific power supply. Meant to decouple from other analog and main digital supplies

NMEA / Binary UART to STM32

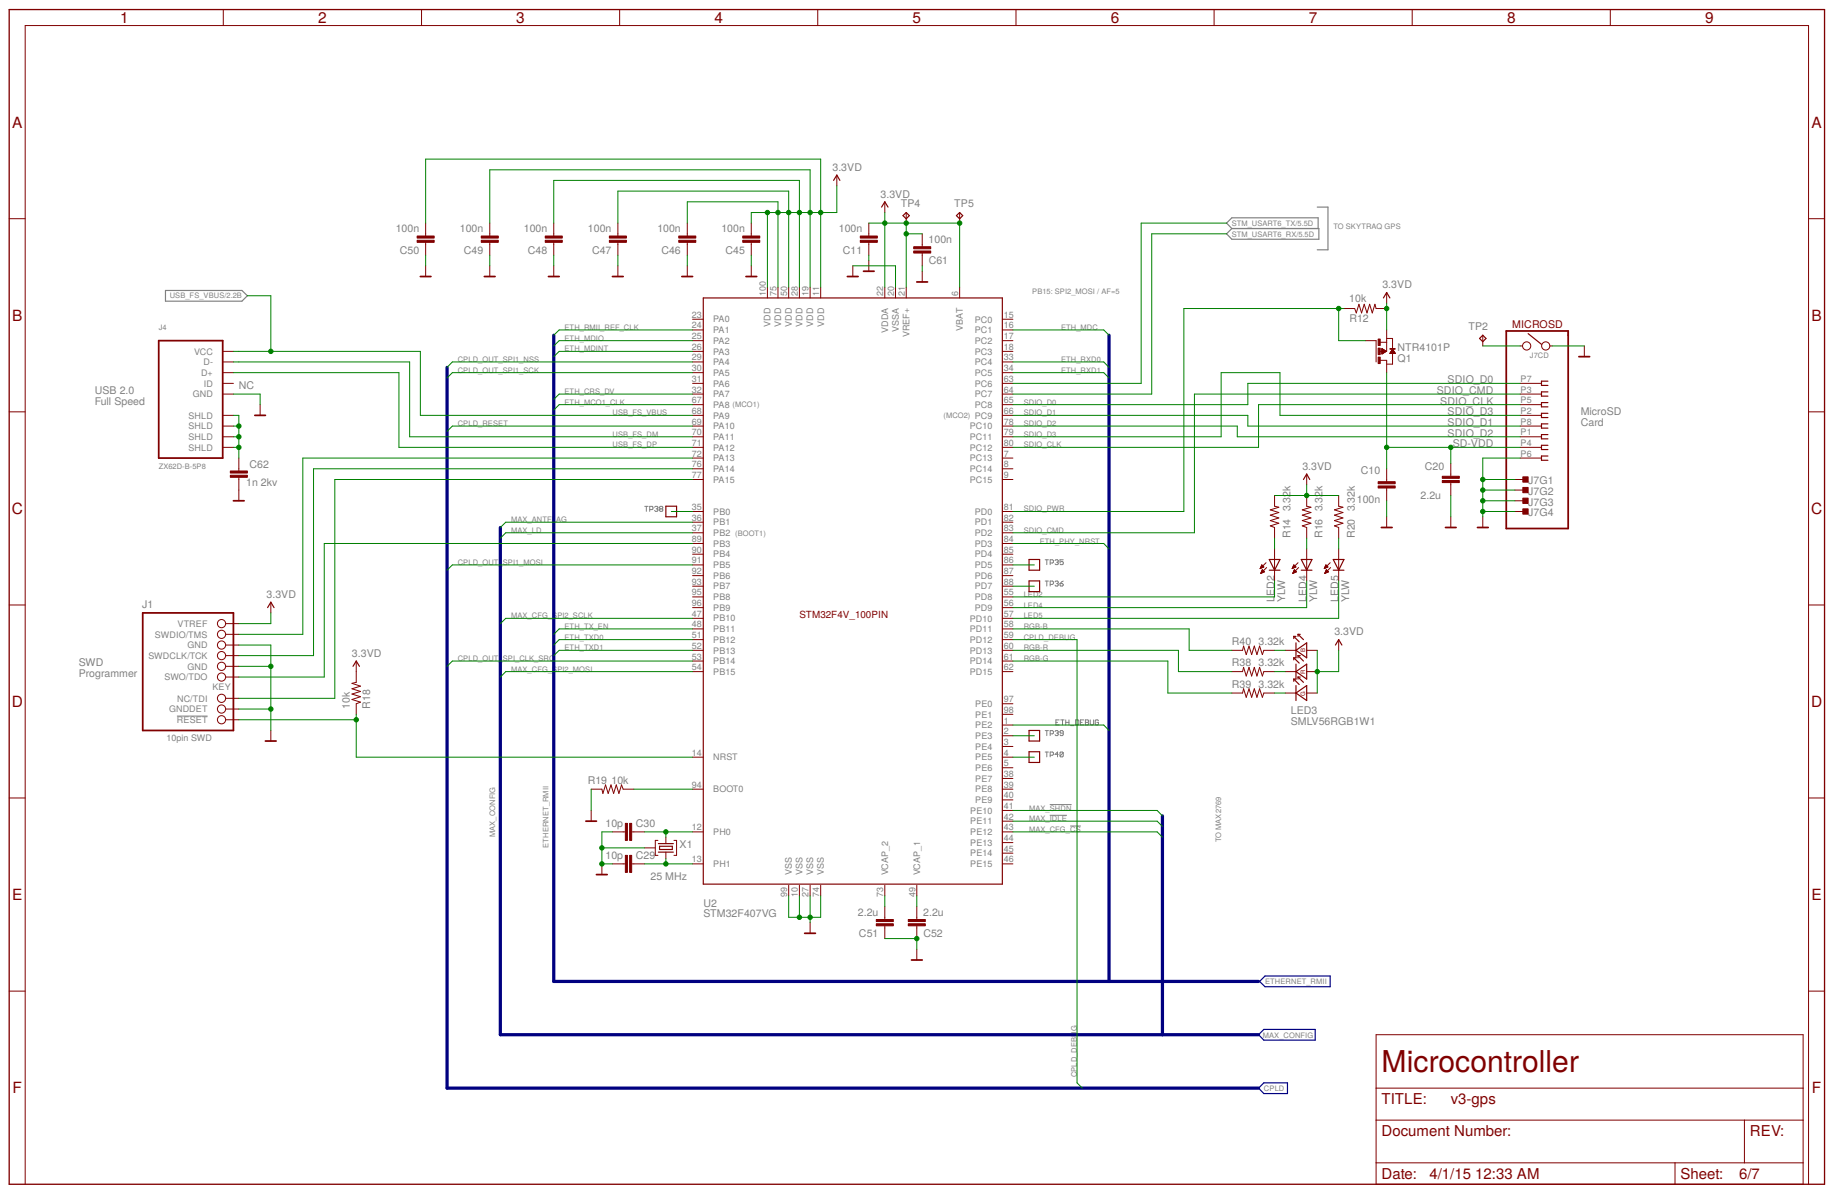
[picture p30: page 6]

VTREF SWDIO/TMS GND

ETH_TX_EN | | RGB-B | LED3
ETH_TXD0 ETH_TXD1 | | CPLD_DEBUG

SWDCLK/TCK GND
SWO/TDO
NC/TDI GNDDET RESET

MAX_CFG_SPI2_MOSI | 54 | 62

RGB-G

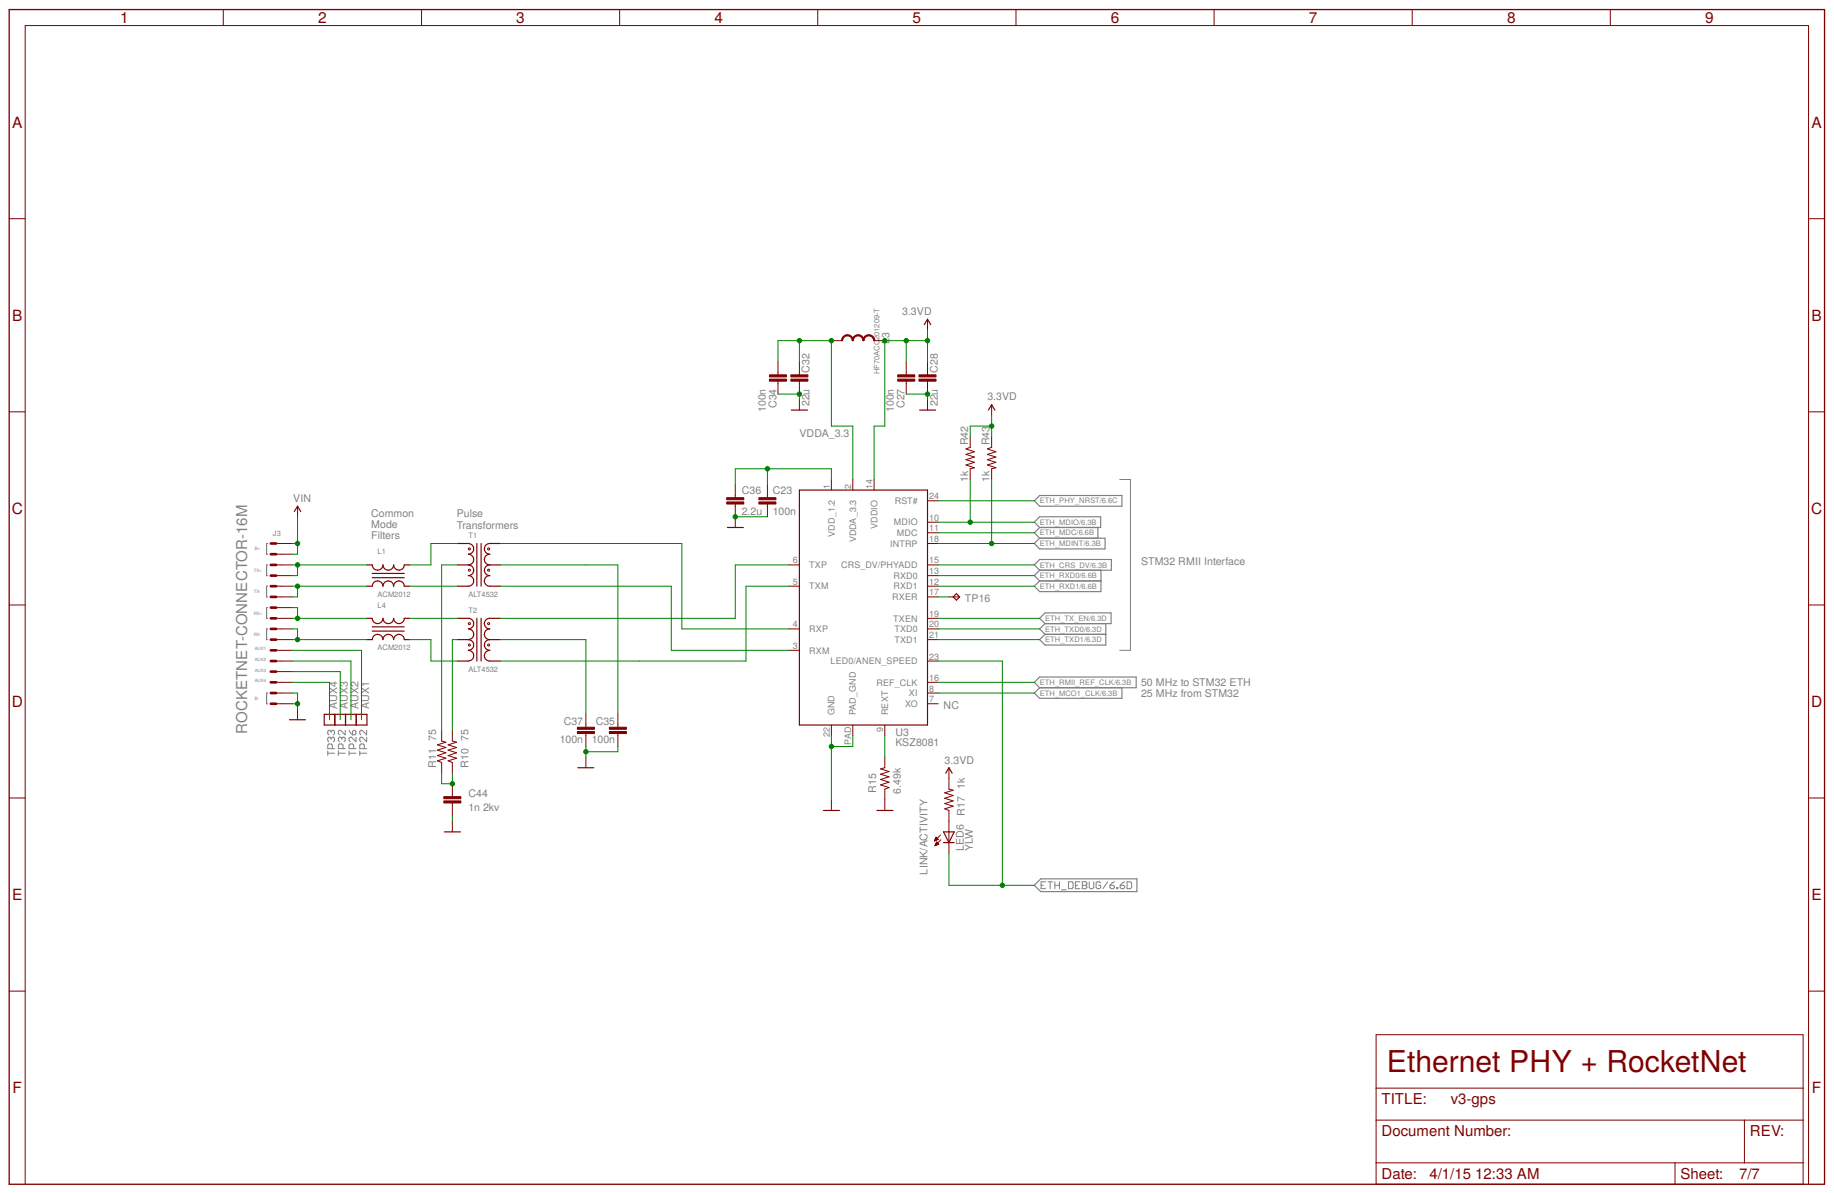
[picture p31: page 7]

VIN
RX+ RX- AUX1 AUX2 AUX3 AUX4 ROCKETNET-CONNECTOR-16M

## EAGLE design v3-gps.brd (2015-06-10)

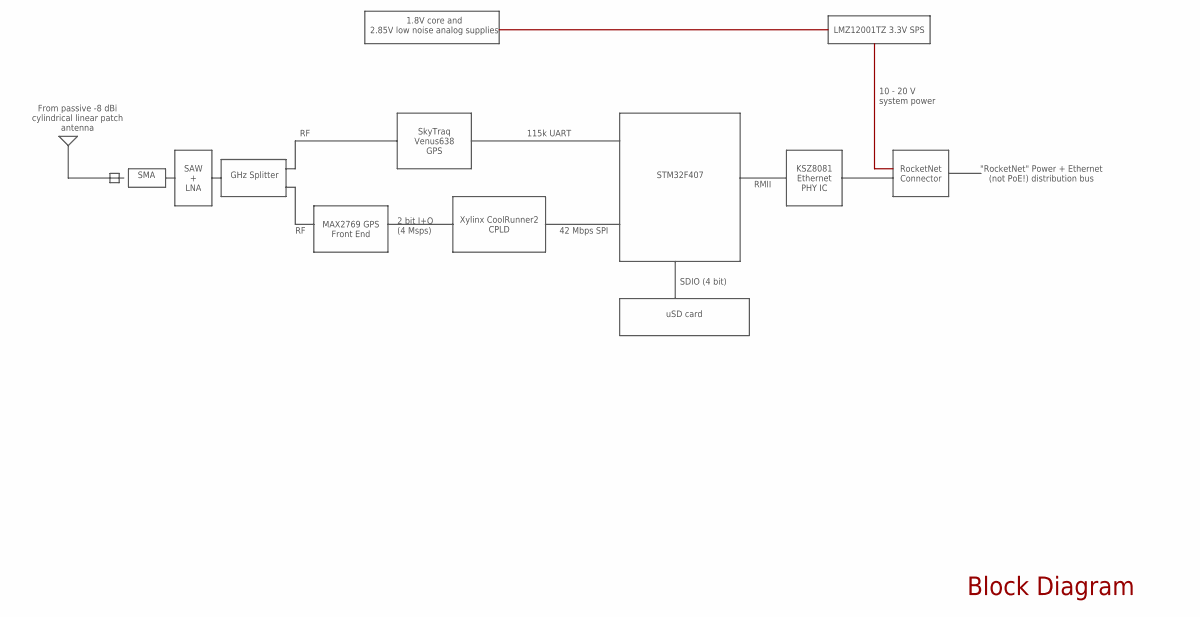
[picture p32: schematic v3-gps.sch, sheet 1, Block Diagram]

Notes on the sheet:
STM32F407
RMII
KSZ8081 Ethernet PHY IC
RocketNet Connector
SDIO (4 bit)
uSD card
SkyTraq Venus638 GPS
Xylinx CoolRunner2 CPLD
115k UART
42 Mbps SPI
MAX2769 GPS Front End
2 bit I+Q (4 Msps)
GHz Splitter
SAW + LNA
SMA
10 - 20 V system power
LMZ12001TZ 3.3V SPS
1.8V core and 2.85V low noise analog supplies
From passive -8 dBi cylindrical linear patch antenna
"RocketNet" Power + Ethernet (not PoE!) distribution bus
Block Diagram

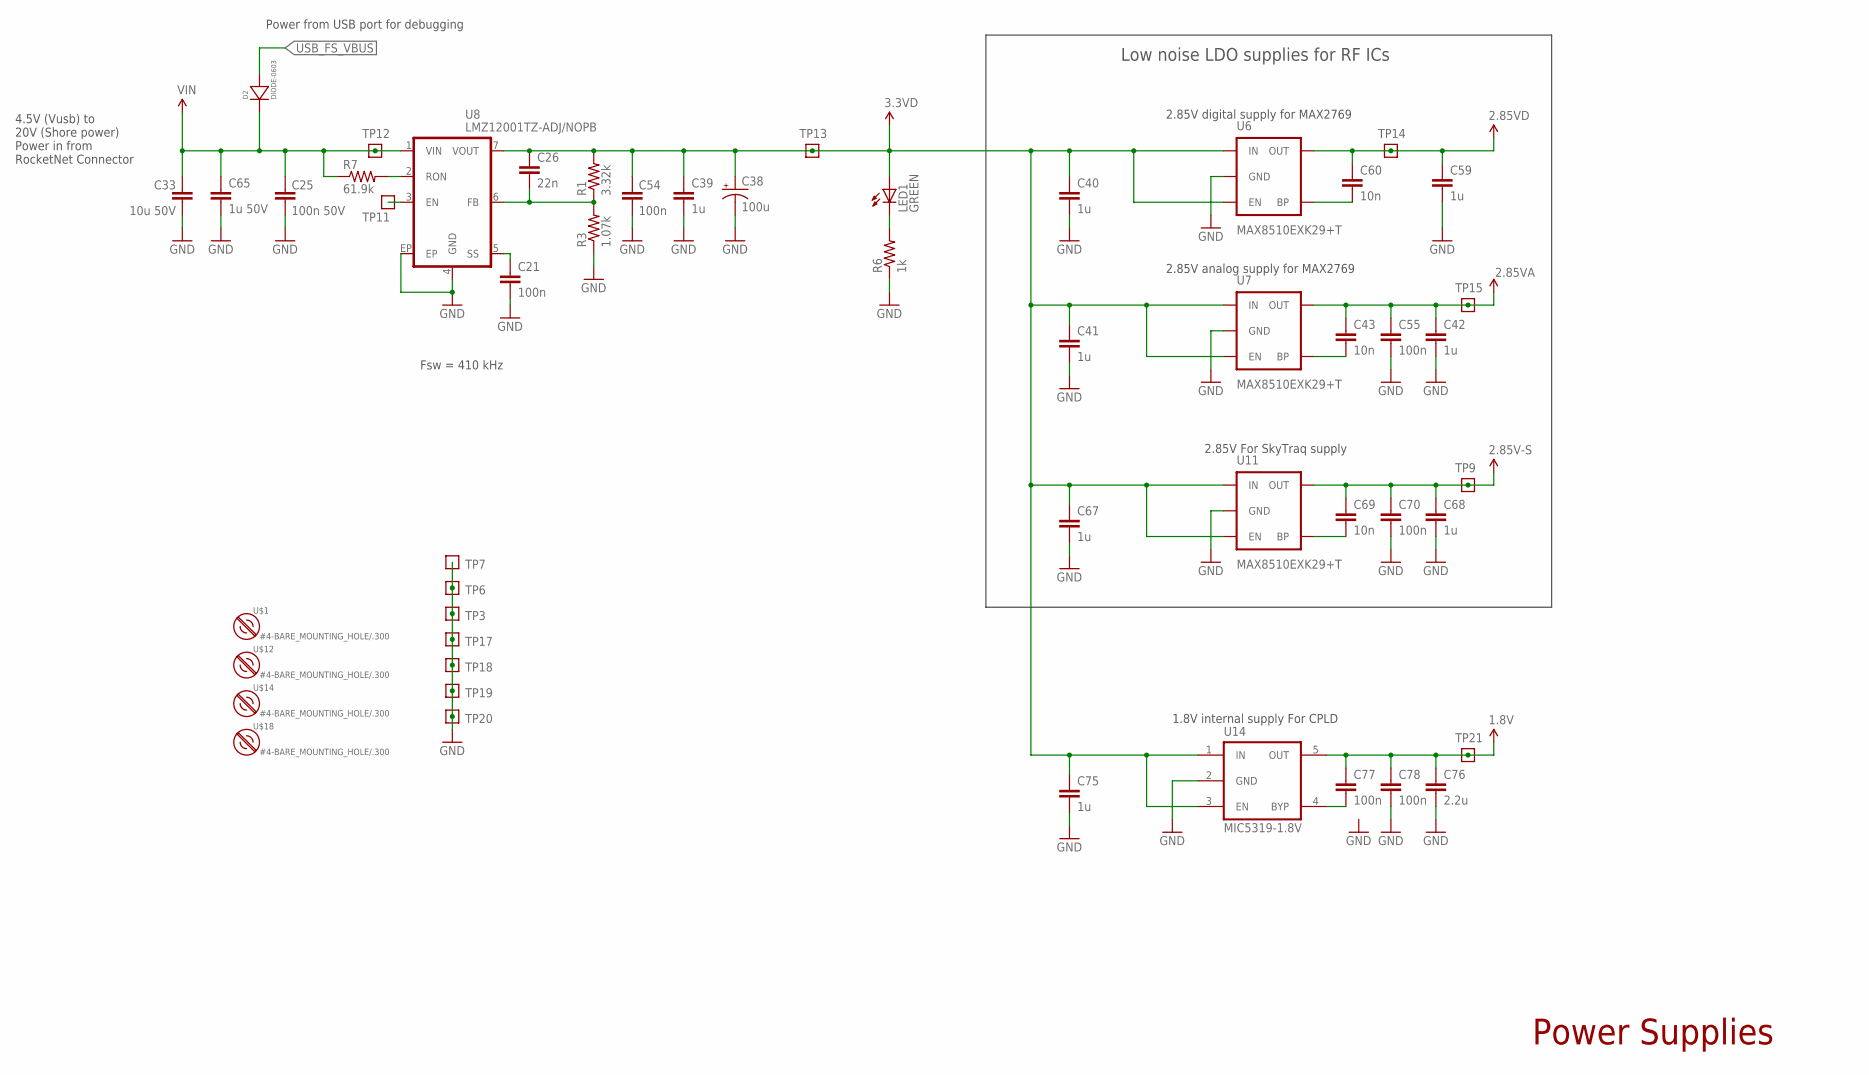
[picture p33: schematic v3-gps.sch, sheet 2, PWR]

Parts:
C21, C54, C55, C70, C77, C78: 100n; .0402-C-NOSILK
C25: 100n 50V; .0402-C-NOSILK
C26: 22n; .0402-C-NOSILK
C33: 10u 50V; 1206-C
C38: 100u; EIA6032
C39, C40, C41, C42, C59, C67, C68, C75: 1u; .0603-B-NOSILK
C43, C60, C69: 10n; .0402-C-NOSILK
C65: 1u 50V; .0603-B-NOSILK
C76: 2.2u; .0603-B-NOSILK
D2: DIODE-0603; 0603-B-NOSILK-DIODE
LED1: GREEN; CHIPLED_0603
R1: 3.32k; 0402-C-NOSILK@1
R3: 1.07k; 0402-C-NOSILK@1
R6: 1k; 0402-C-NOSILK@1
R7: 61.9k; 0402-C-NOSILK@1
TP3, TP6, TP7, TP9, TP11, TP12, TP13, TP14, TP15, TP17, TP18, TP19, TP20, TP21: TEST-POINT15MIL-TEST-POINT; 15MIL-TEST-POINT
U6, U7, U11: MAX8510EXK29+T; SC70
U8: LMZ12001TZ-ADJ/NOPB; TO-PMOD-7
U14: MIC5319-1.8V; SOT-23-5
U$1, U$12, U$14, U$18: #4-BARE_MOUNTING_HOLE/.300; #4/.300-BARE+STD_NUT_OR_STAR_WASHER

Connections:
1.8V: C76.1, C77.1, C78.1, TP21.P$1, U14.5 (OUT); also elsewhere on the board
2.85V-S: C68.1, C69.1, C70.1, TP9.P$1, U11.5 (OUT); also elsewhere on the board
2.85VA: C42.1, C43.1, C55.1, TP15.P$1, U7.5 (OUT); also elsewhere on the board
2.85VD: C59.1, C60.1, TP14.P$1, U6.5 (OUT); also elsewhere on the board
3.3VD: C26.1, C38.P$1 (+), C39.1, C40.1, C41.1, C54.1, C67.1, C75.1, LED1.A, R1.2, TP13.P$1, U6.1 (IN), U6.3 (EN), U7.1 (IN), U7.3 (EN), U8.7 (VOUT), U11.1 (IN), U11.3 (EN), U14.1 (IN), U14.3 (EN); also elsewhere on the board
GND: C21.2, C25.2, C33.2, C38.P$2 (-), C39.2, C40.2, C41.2, C42.2, C54.2, C55.2, C59.2, C65.2, C67.2, C68.2, C70.2, C75.2, C76.2, C78.2, R3.1, R6.1, TP3.P$1, TP6.P$1, TP7.P$1, TP17.P$1, TP18.P$1, TP19.P$1, TP20.P$1, U6.2 (GND), U7.2 (GND), U8.4 (GND), U8.EP, U11.2 (GND), U14.2 (GND); also elsewhere on the board
unnamed: TP11.P$1, U8.3 (EN)
unnamed: C69.2, U11.4 (BP)
unnamed: C21.1, U8.5 (SS)
unnamed: C26.2, R1.1, R3.2, U8.6 (FB)
unnamed: R7.2, U8.2 (RON)
unnamed: C43.2, U7.4 (BP)
unnamed: C60.2, U6.4 (BP)
unnamed: LED1.C, R6.2
unnamed: C77.2, U14.4 (BYP)
USB_FS_VBUS: D2.ANODE; also elsewhere on the board
VIN: C25.1, C33.1, C65.1, D2.CATHODE, R7.1, TP12.P$1, U8.1 (VIN); also elsewhere on the board

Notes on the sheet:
4.5V (Vusb) to 20V (Shore power) Power in from RocketNet Connector
2.85V digital supply for MAX2769
Power from USB port for debugging
2.85V For SkyTraq supply
1.8V internal supply For CPLD
2.85V analog supply for MAX2769
Low noise LDO supplies for RF ICs
Fsw = 410 kHz
Power Supplies

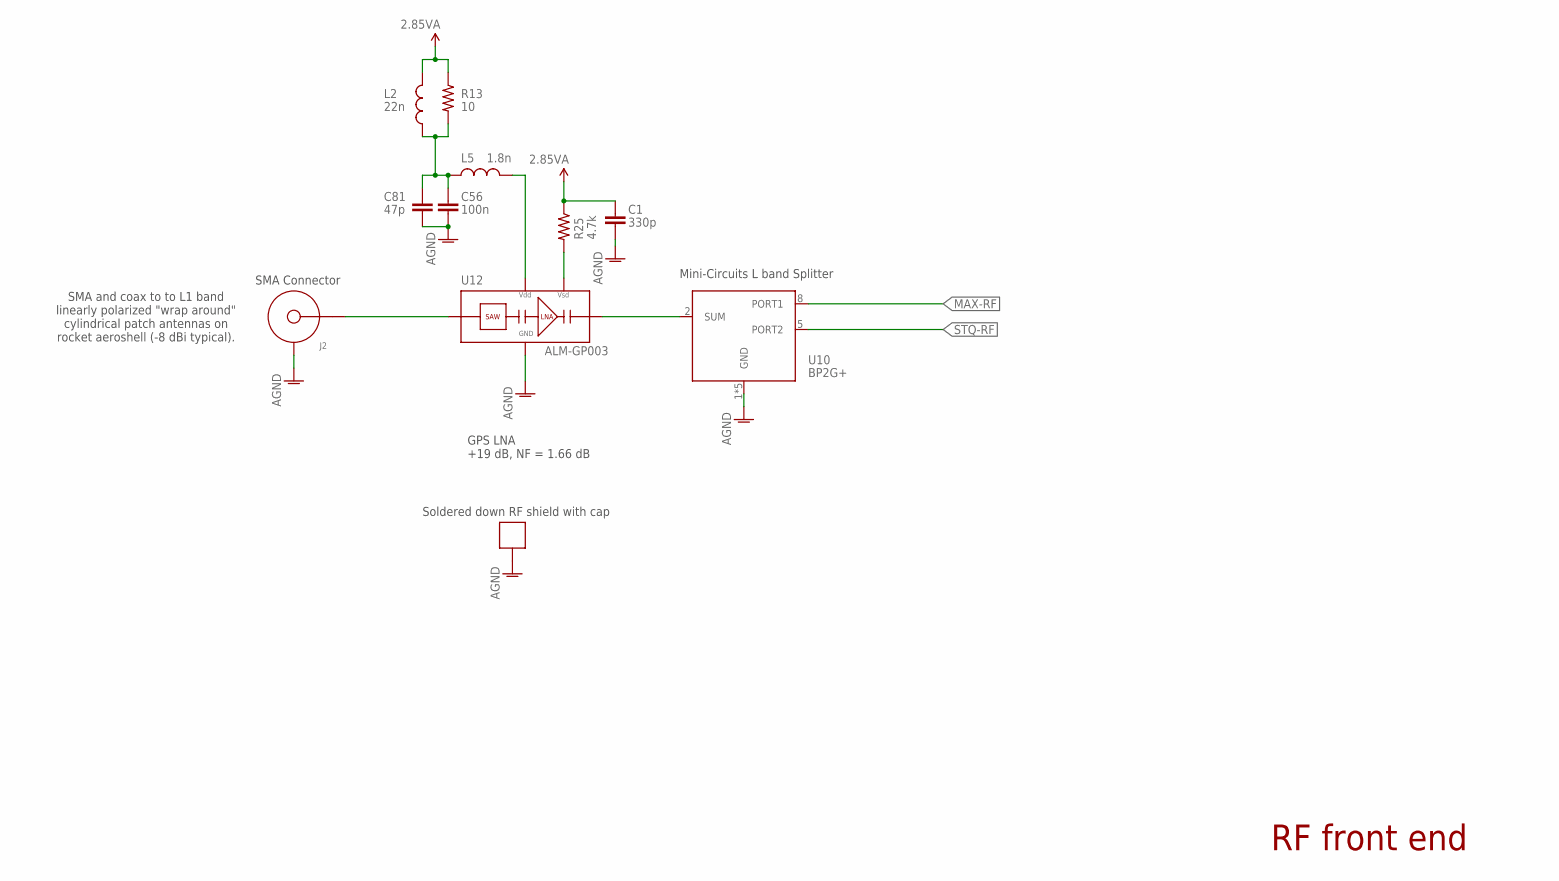
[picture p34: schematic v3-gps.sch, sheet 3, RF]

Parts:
C1: 330p; .0402-C-NOSILK
C56: 100n; .0402-C-NOSILK
C81: 47p; .0402-C-NOSILK
J2: CON_SMA-ENDFIRE_EMERSON_EMERSON-142-0701-801; SMA-CON-EMERSON
L2: 22n; .0402-B-NOSILK
L5: 1.8n; .0402-B-NOSILK
R13: 10; 0402-C-NOSILK@1
R25: 4.7k; 0402-C-NOSILK@1
SH1: BMI-S-202-SHIELD; BMI-S-202
U10: BP2G+; MINICIRCUITS
U12: ALM-GP003; AVAGO+SAW+LNA

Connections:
2.85VA: C1.1, L2.2, R13.1, R25.1; also elsewhere on the board
AGND: C1.2, C56.2, C81.2, J2.GND, J2.GND@1 (GND), J2.GND@2 (GND), J2.GND@3 (GND), SH1.P$1, SH1.P$2, SH1.P$3, SH1.P$4, SH1.P$5, SH1.P$6, SH1.P$7, SH1.P$8, SH1.P$9, SH1.P$10, SH1.P$11, SH1.P$12, U10.1 (GND), U10.3 (GND), U10.4 (GND), U10.6 (GND), U10.7 (GND), U12.2 (GND), U12.3 (GND), U12.4 (GND), U12.9 (GND), U12.P$1 (GND), U12.P$2 (GND); also elsewhere on the board
LNA-POWER-FILTERED: C56.1, C81.1, L2.1, L5.1, R13.2
MAX-RF: U10.8 (PORT1); also elsewhere on the board
unnamed: J2.SIG, U12.1 (RF-IN)
unnamed: U10.2 (SUM), U12.6 (RF-OUT)
unnamed: R25.2, U12.8 (SD)
unnamed: L5.2, U12.7 (VDD)
STQ-RF: U10.5 (PORT2); also elsewhere on the board

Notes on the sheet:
SMA Connector
Soldered down RF shield with cap
Mini-Circuits L band Splitter
GPS LNA +19 dB, NF = 1.66 dB
SMA and coax to to L1 band linearly polarized "wrap around" cylindrical patch antennas on rocket aeroshell (-8 dBi typical).
RF front end

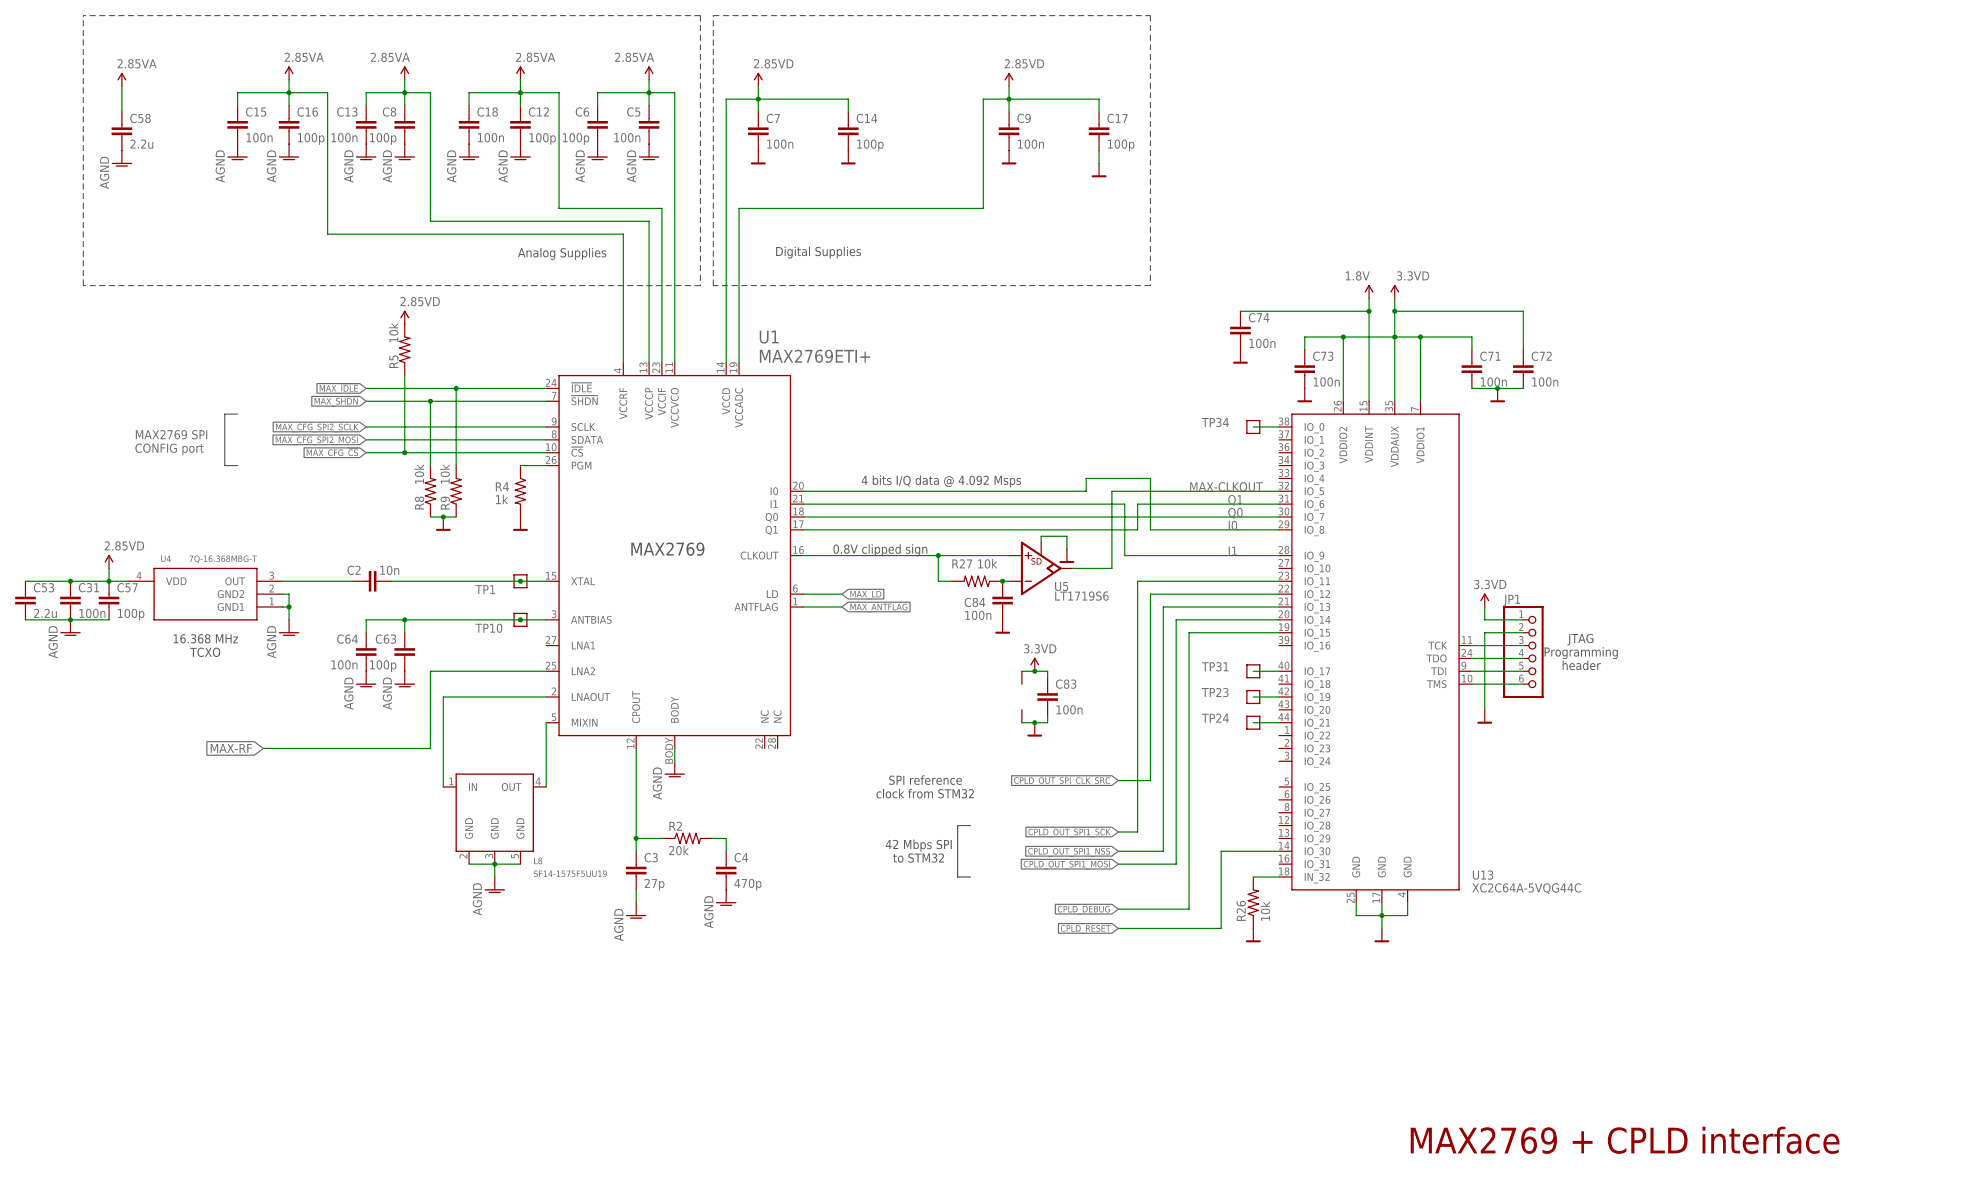
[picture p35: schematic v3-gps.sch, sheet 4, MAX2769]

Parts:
C2: 10n; .0402-C-NOSILK
C3: 27p; .0402-C-NOSILK
C4: 470p; .0402-C-NOSILK
C5, C7, C9, C13, C15, C18, C31, C64, C71, C72, C73, C74, C83, C84: 100n; .0402-C-NOSILK
C6, C8, C12, C14, C16, C17, C57, C63: 100p; .0402-C-NOSILK
C53, C58: 2.2u; .0603-B-NOSILK
JP1: PINHD-1X6; 1X06
L8: SF14-1575F5UU19; SAW_1.4X1.1
R2: 20k; 0402-C-NOSILK@1
R4: 1k; 0402-C-NOSILK@1
R5, R8, R9, R26, R27: 10k; 0402-C-NOSILK@1
TP1, TP10, TP23, TP24, TP31, TP34: TEST-POINT15MIL-TEST-POINT; 15MIL-TEST-POINT
U1: MAX2769ETI+; 90-0023
U4: 7Q-16.368MBG-T; TCX_7Q
U5: LT1719S6; SOT23-6
U13: XC2C64A-5VQG44C; VQ44

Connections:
1.8V: C74.1, U13.15 (VDDINT); also elsewhere on the board
2.85VA: C5.1, C6.1, C8.1, C12.1, C13.1, C15.1, C16.1, C18.1, C58.1, U1.4 (VCCRF), U1.11 (VCCVCO), U1.13 (VCCCP), U1.23 (VCCIF); also elsewhere on the board
2.85VD: C7.1, C9.1, C14.1, C17.1, C31.1, C53.1, C57.1, R5.2, U1.14 (VCCD), U1.19 (VCCADC), U4.4 (VDD); also elsewhere on the board
3.3VD: C71.1, C72.1, C73.1, C83.1, JP1.1, U5.4 (V+), U13.7 (VDDIO1), U13.26 (VDDIO2), U13.35 (VDDAUX); also elsewhere on the board
AGND: C3.2, C4.2, C5.2, C6.2, C8.2, C12.2, C13.2, C15.2, C16.2, C18.2, C31.2, C53.2, C57.2, C58.2, C63.2, C64.2, L8.2 (GND), L8.3 (GND), L8.5 (GND), U1.BODY, U4.1 (GND1), U4.2 (GND2); also elsewhere on the board
ANTBIAS: C63.1, C64.1, TP10.P$1, U1.3 (ANTBIAS)
CPLD_DEBUG: U13.19 (IO_15); also elsewhere on the board
CPLD_IN_ONLY: R26.2, U13.18 (IN_32)
CPLD_OUT_SPI1_MOSI: U13.20 (IO_14); also elsewhere on the board
CPLD_OUT_SPI1_NSS: U13.21 (IO_13); also elsewhere on the board
CPLD_OUT_SPI1_SCK: U13.23 (IO_11); also elsewhere on the board
CPLD_OUT_SPI_CLK_SRC: U13.22 (IO_12); also elsewhere on the board
CPLD_RESET: U13.14 (IO_30); also elsewhere on the board
CPOUT: C3.1, R2.1, U1.12 (CPOUT)
GND: C7.2, C9.2, C14.2, C17.2, C71.2, C72.2, C73.2, C74.2, C83.2, C84.2, JP1.2, R4.2, R8.1, R9.1, R26.1, U5.2 (V-), U5.6 (SD), U13.4 (GND), U13.17 (GND), U13.25 (GND); also elsewhere on the board
I0: U1.20 (I0), U13.29 (IO_8)
I1: U1.21 (I1), U13.28 (IO_9)
LNAOUT: L8.1 (IN), U1.2 (LNAOUT)
MAX-CLKOUT: U5.5 (OUT), U13.32 (IO_5)
MAX-RF: U1.25 (LNA2); also elsewhere on the board
MAX_!IDLE: R9.2, U1.24 (!IDLE); also elsewhere on the board
MAX_!SHDN: R8.2, U1.7 (!SHDN); also elsewhere on the board
MAX_ANTFLAG: U1.1 (ANTFLAG); also elsewhere on the board
MAX_CFG_!CS: R5.1, U1.10 (!CS); also elsewhere on the board
MAX_CFG_SPI2_MOSI: U1.8 (SDATA); also elsewhere on the board
MAX_CFG_SPI2_SCLK: U1.9 (SCLK); also elsewhere on the board
MAX_CLK_OUT: R27.2, U1.16 (CLKOUT), U5.3 (+IN)
MAX_LD: U1.6 (LD); also elsewhere on the board
MIXIN: L8.4 (OUT), U1.5 (MIXIN)
unnamed: JP1.6, U13.10 (TMS)
unnamed: TP24.P$1, U13.44 (IO_21)
unnamed: TP23.P$1, U13.42 (IO_19)
unnamed: TP31.P$1, U13.40 (IO_17)
unnamed: JP1.5, U13.9 (TDI)
unnamed: C4.1, R2.2
unnamed: C84.1, R27.1, U5.1 (-IN)
unnamed: TP34.P$1, U13.38 (IO_0)
unnamed: JP1.4, U13.24 (TDO)
unnamed: C2.1, U4.3 (OUT)
unnamed: JP1.3, U13.11 (TCK)
PGM: R4.1, U1.26 (PGM)
Q0: U1.18 (Q0), U13.30 (IO_7)
Q1: U1.17 (Q1), U13.31 (IO_6)
XTAL: C2.2, TP1.P$1, U1.15 (XTAL)

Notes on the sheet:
Digital Supplies
Analog Supplies
MAX2769 SPI CONFIG port
4 bits I/Q data @ 4.092 Msps
42 Mbps SPI to STM32
SPI reference clock from STM32
JTAG Programming header
16.368 MHz TCXO
0.8V clipped sign
MAX2769 + CPLD interface

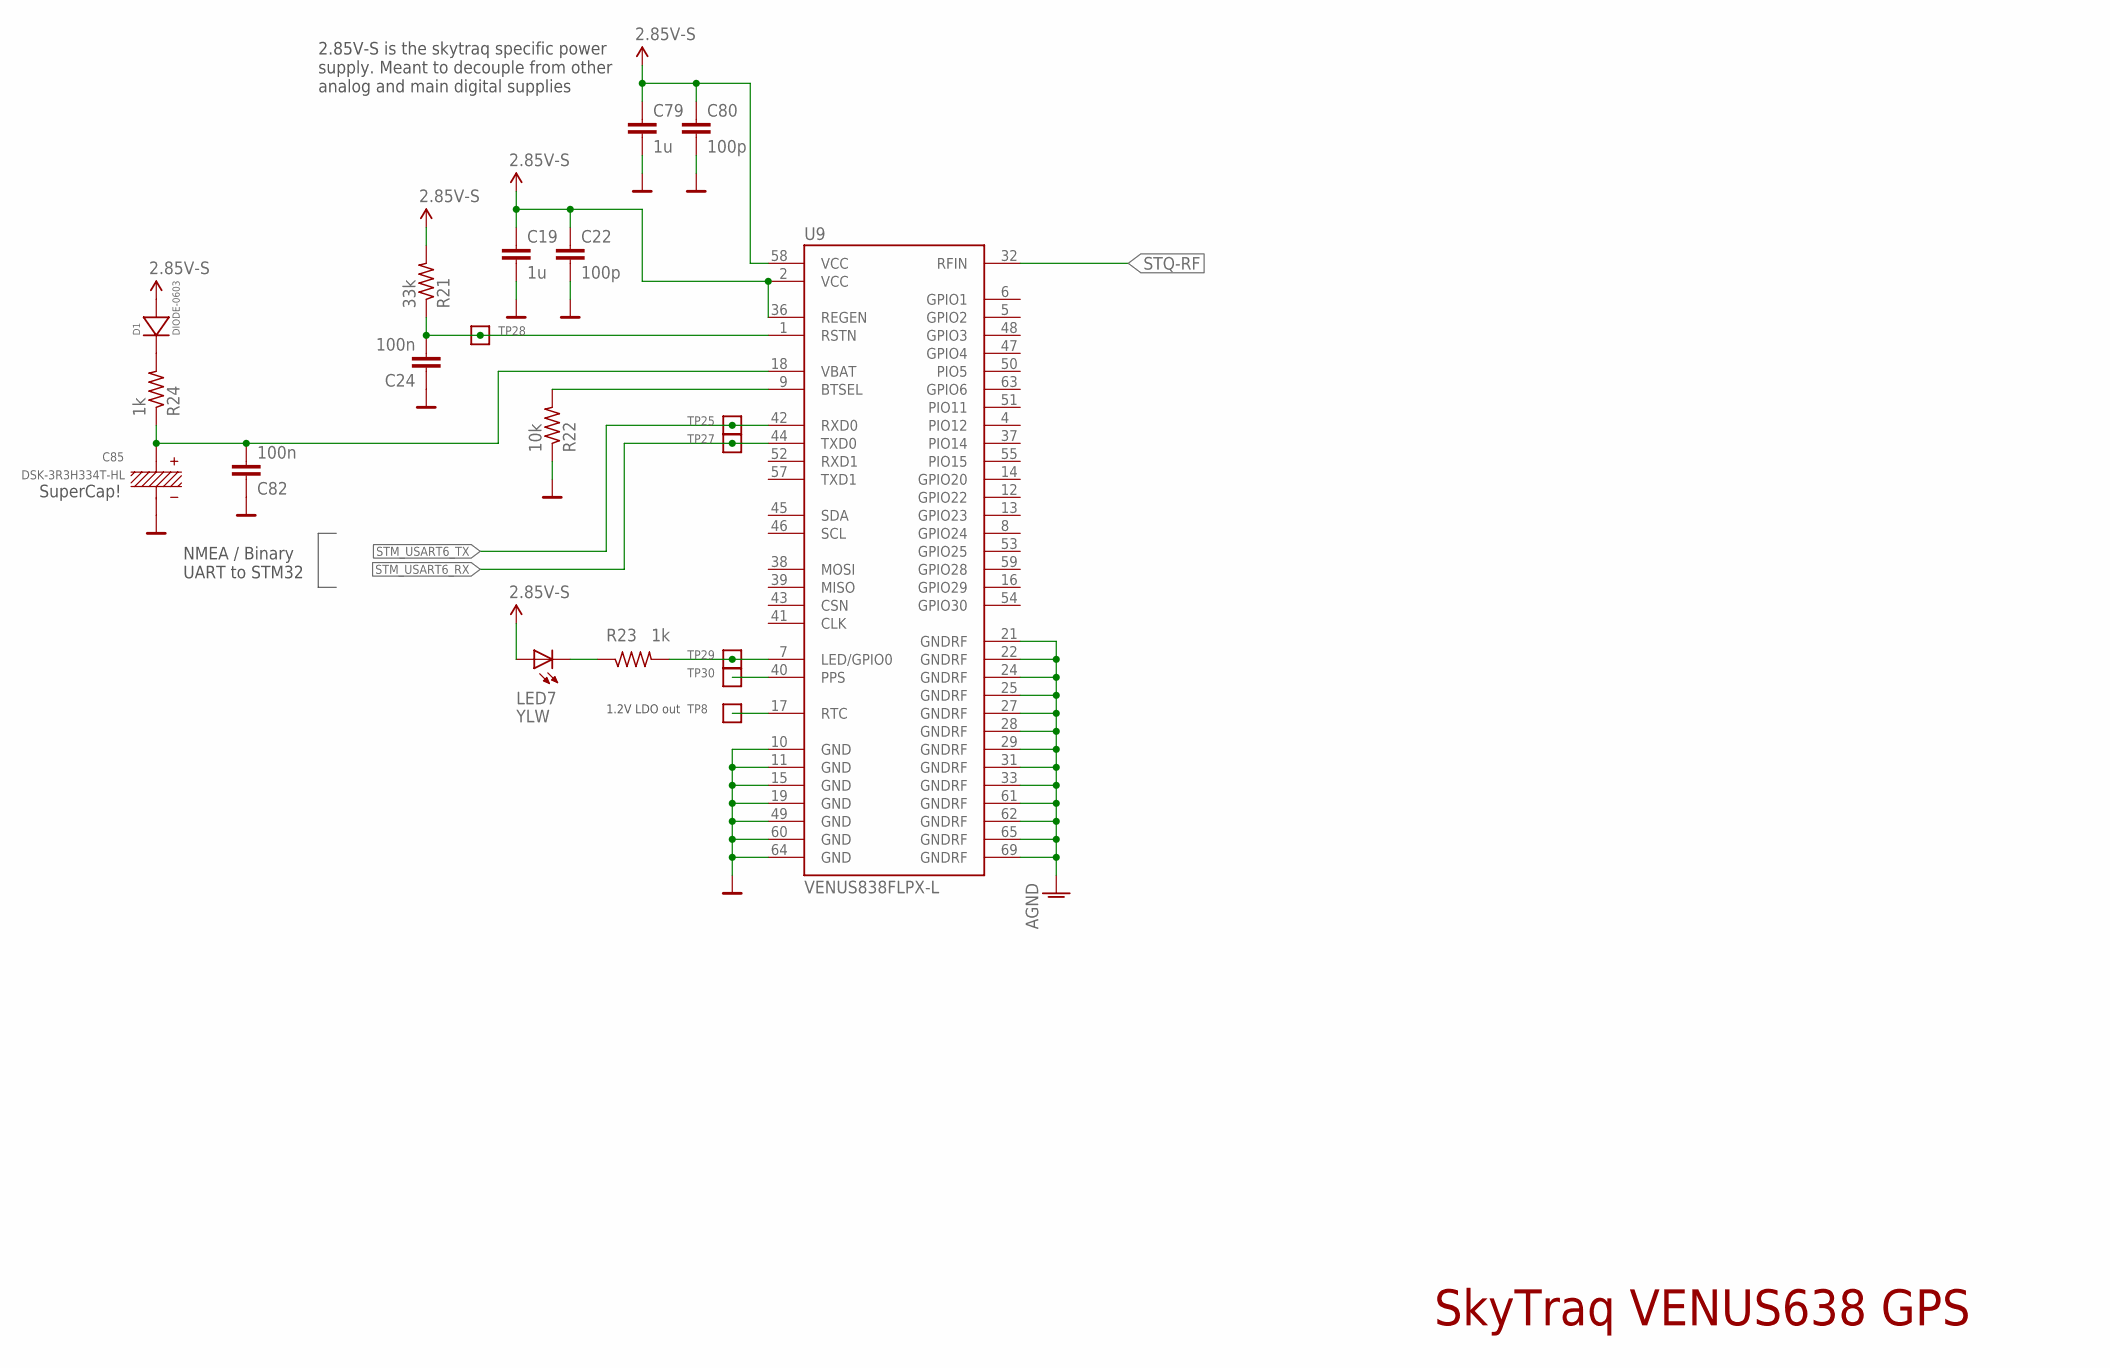
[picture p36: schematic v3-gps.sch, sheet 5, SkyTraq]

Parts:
C19, C79: 1u; .0603-C-NOSILK
C22, C80: 100p; .0402-C-NOSILK
C24, C82: 100n; .0402-C-NOSILK
C85: DSK-3R3H334T-HL; CAP-ELNA-DS-SERIES
D1: DIODE-0603; 0603-B-NOSILK-DIODE
LED7: YLW; CHIPLED_0603
R21: 33k; 0402-C-NOSILK@1
R22: 10k; 0402-C-NOSILK@1
R23, R24: 1k; 0402-C-NOSILK@1
TP8, TP25, TP27, TP28, TP29, TP30: TEST-POINT15MIL-TEST-POINT; 15MIL-TEST-POINT
U9: VENUS838FLPX-L; VENUS638FLPX

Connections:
2.85V-S: C19.1, C22.1, C79.1, C80.1, D1.ANODE, LED7.A, R21.2, U9.2 (VCC), U9.36 (REGEN), U9.58 (VCC); also elsewhere on the board
AGND: U9.21 (GNDRF), U9.22 (GNDRF), U9.24 (GNDRF), U9.25 (GNDRF), U9.27 (GNDRF), U9.28 (GNDRF), U9.29 (GNDRF), U9.31 (GNDRF), U9.33 (GNDRF), U9.61 (GNDRF), U9.62 (GNDRF), U9.65 (GNDRF), U9.69 (GNDRF); also elsewhere on the board
GND: C19.2, C22.2, C24.1, C79.2, C80.2, C82.1, C85.-, R22.1, U9.10 (GND), U9.11 (GND), U9.15 (GND), U9.19 (GND), U9.49 (GND), U9.60 (GND), U9.64 (GND); also elsewhere on the board
LED/GPIO: R23.2, TP29.P$1, U9.7 (LED/GPIO0)
unnamed: R22.2, U9.9 (BTSEL)
unnamed: LED7.C, R23.1
unnamed: D1.CATHODE, R24.2
RTC: TP8.P$1, U9.17 (RTC)
STM_USART6_RX: TP27.P$1, U9.44 (TXD0); also elsewhere on the board
STM_USART6_TX: TP25.P$1, U9.42 (RXD0); also elsewhere on the board
STQ-!RST: C24.2, R21.1, TP28.P$1, U9.1 (RSTN)
STQ-PPS: TP30.P$1, U9.40 (PPS)
STQ-RF: U9.32 (RFIN); also elsewhere on the board
STQ-VBAT: C82.2, C85.+, R24.1, U9.18 (VBAT)

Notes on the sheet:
1.2V LDO out
SuperCap!
2.85V-S is the skytraq specific power supply. Meant to decouple from other analog and main digital supplies
SkyTraq VENUS638 GPS
NMEA / Binary UART to STM32

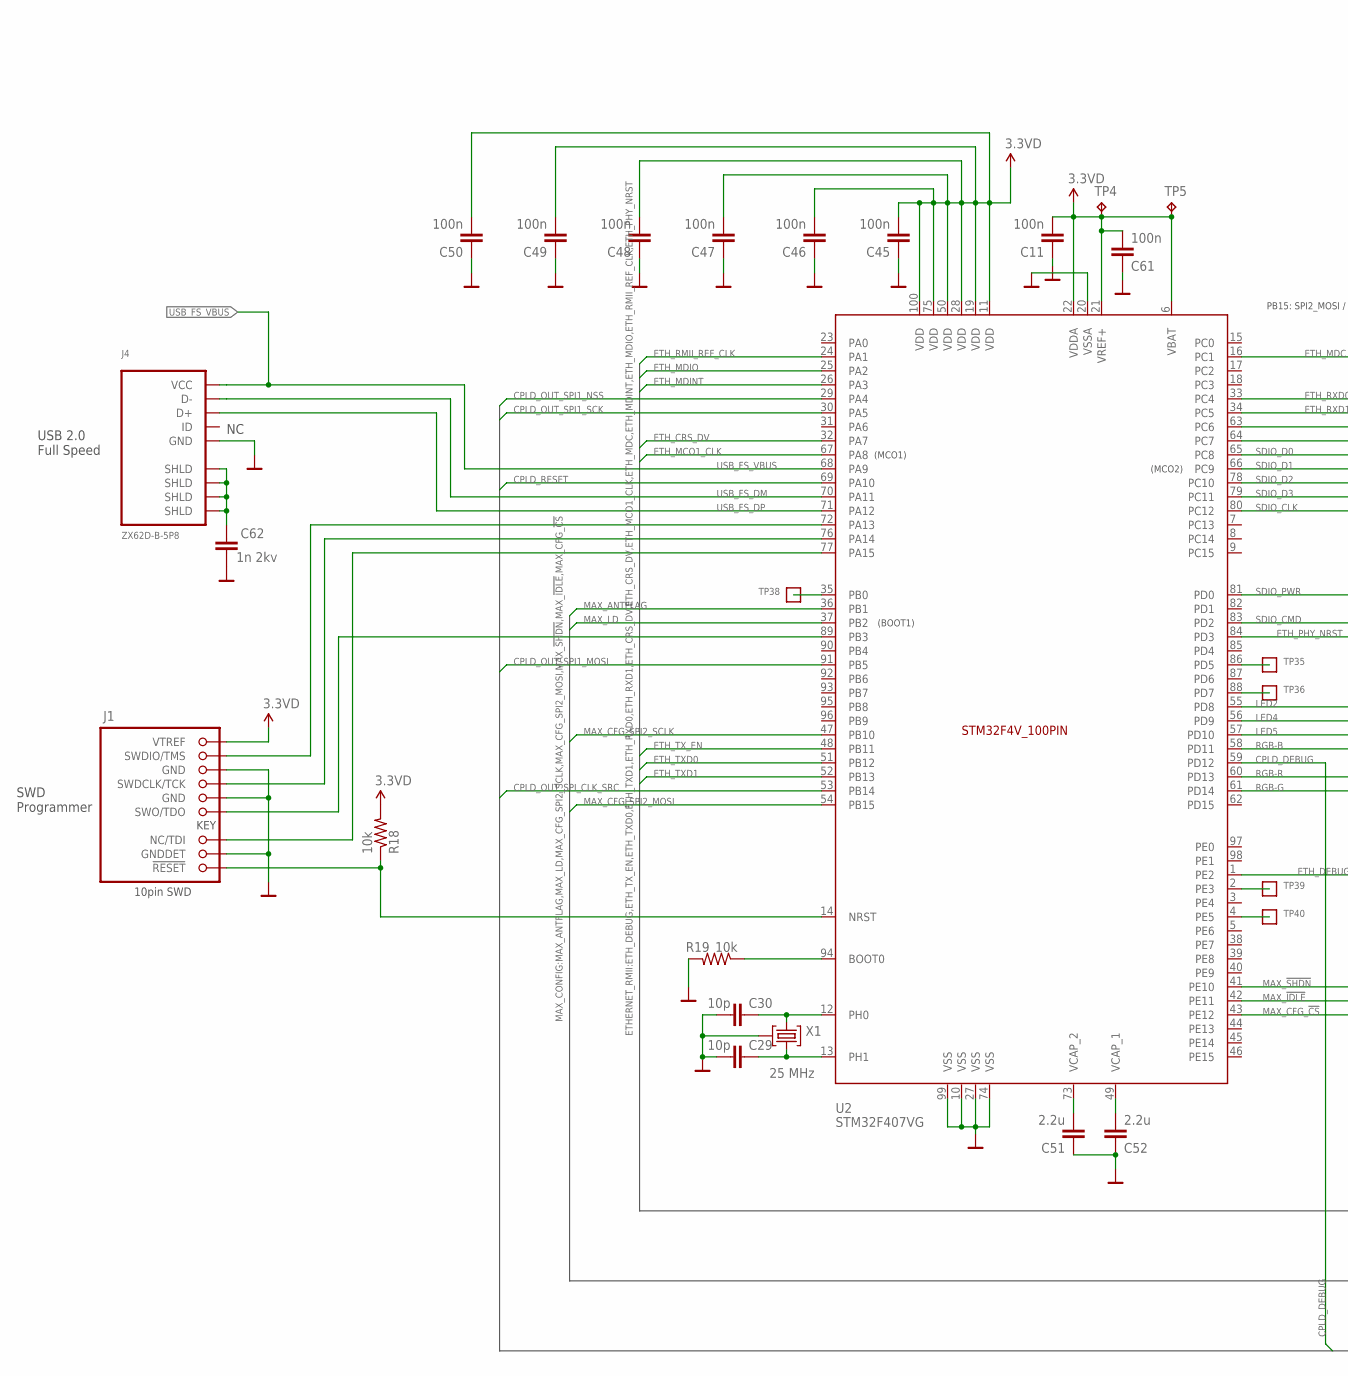
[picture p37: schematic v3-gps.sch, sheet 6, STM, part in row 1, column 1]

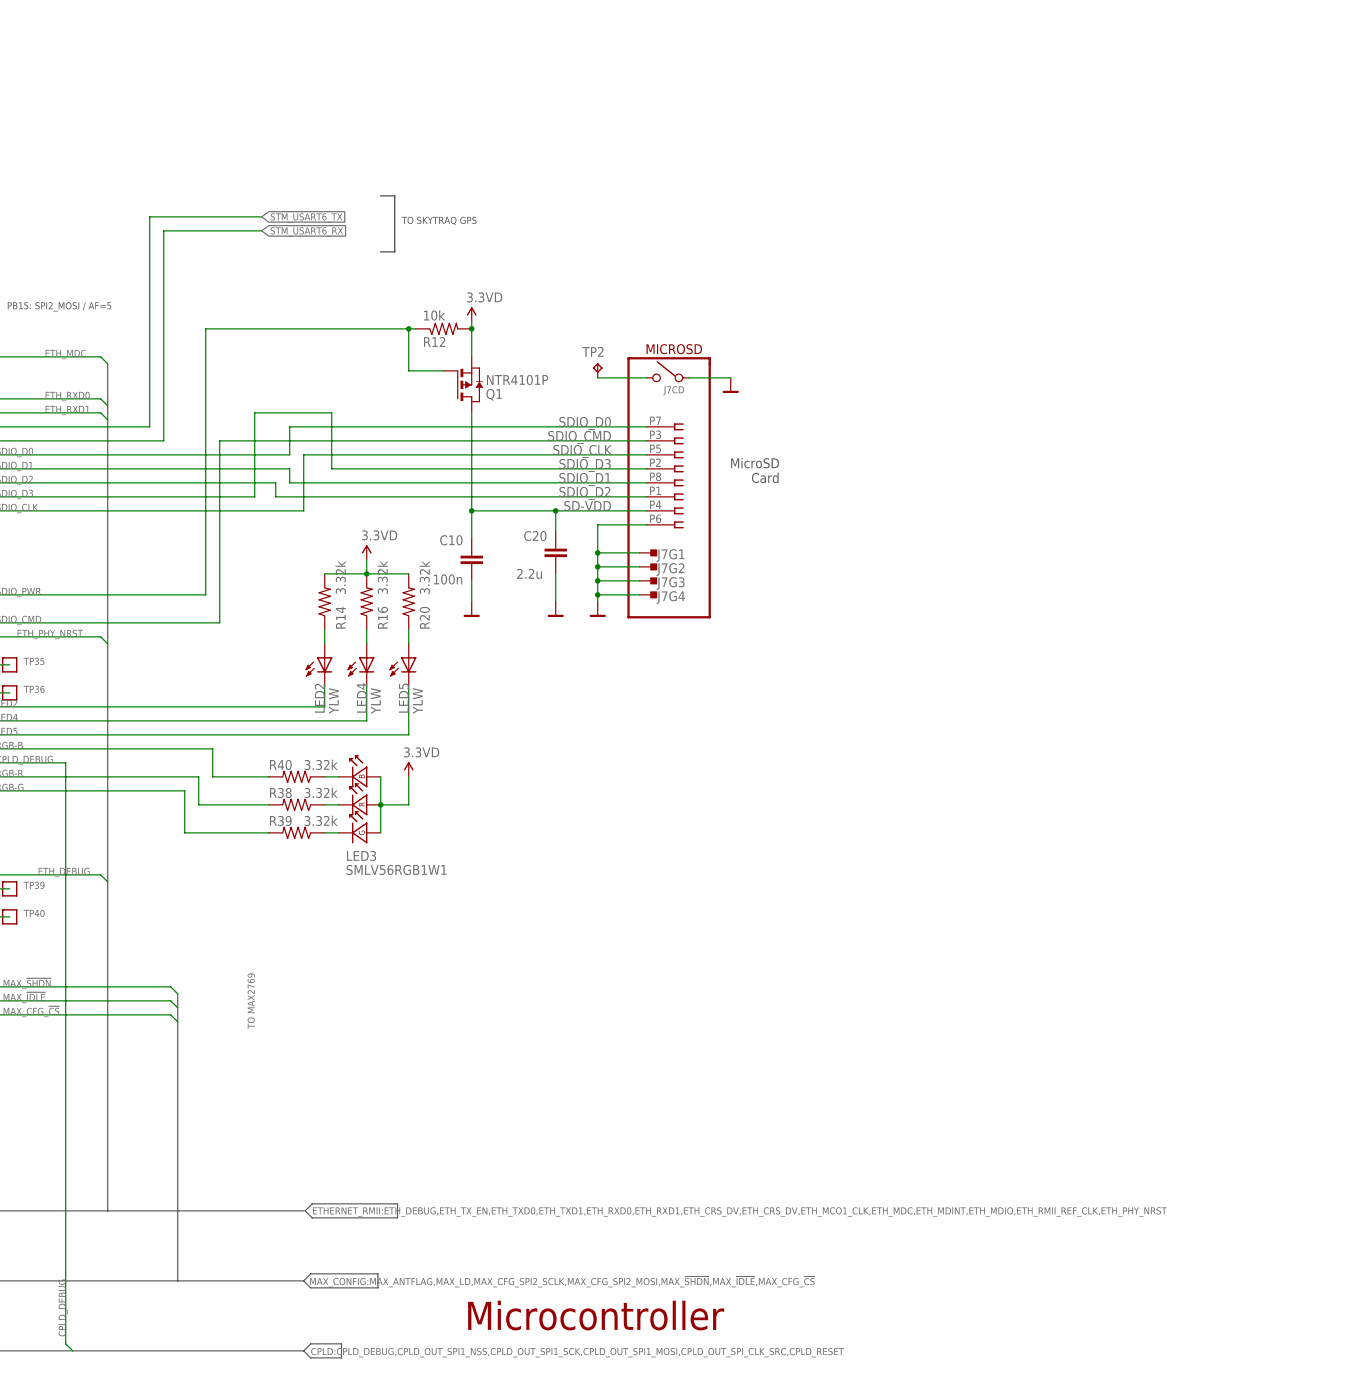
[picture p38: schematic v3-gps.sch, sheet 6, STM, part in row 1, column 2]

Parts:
C10, C11, C45, C46, C47, C48, C49, C50, C61: 100n; .0402-C-NOSILK
C20, C51, C52: 2.2u; .0603-B-NOSILK
C29, C30: 10p; .0402-C-NOSILK
C62: 1n 2kv; .0402-C-NOSILK
J1: 1.27MM-SWD-CONNECTOR; 1.27MM_2X5
J4: ZX62D-B-5P8
J7: CON_HIROSE_DM3D(MICROSD); HIROSE_DM3D(MICRO-SD)
LED2, LED4, LED5: YLW; CHIPLED_0603
LED3: SMLV56RGB1W1; LED-3528
Q1: NTR4101P; SOT23
R12, R18, R19: 10k; 0402-C-NOSILK@1
R14, R16, R20, R38, R39, R40: 3.32k; 0402-C-NOSILK@1
TP2, TP4, TP5: TPTP06R; TP06R
TP35, TP36, TP38, TP39, TP40: TEST-POINT15MIL-TEST-POINT; 15MIL-TEST-POINT
U2: STM32F407VG; LQFP100
X1: 25 MHz; 8Y

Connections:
3.3VD: C11.2, C45.2, C46.2, C47.2, C48.2, C49.2, C50.2, C61.2, J1.VTREF, LED3.1 (A), LED3.2 (A), LED3.3 (A), Q1.2 (S), R12.2, R14.2, R16.2, R18.2, R20.2, TP4.TP, TP5.TP, U2.6 (VBAT), U2.11 (VDD), U2.19 (VDD), U2.21 (VREF+), U2.22 (VDDA), U2.28 (VDD), U2.50 (VDD), U2.75 (VDD), U2.100 (VDD); also elsewhere on the board
!RST: J1.!RESET, R18.1, U2.14 (NRST)
BOOT0: R19.1, U2.94 (BOOT0)
CPLD_DEBUG: U2.59 (PD12); also elsewhere on the board
CPLD_OUT_SPI1_MOSI: U2.91 (PB5); also elsewhere on the board
CPLD_OUT_SPI1_NSS: U2.29 (PA4); also elsewhere on the board
CPLD_OUT_SPI1_SCK: U2.30 (PA5); also elsewhere on the board
CPLD_OUT_SPI_CLK_SRC: U2.53 (PB14); also elsewhere on the board
CPLD_RESET: U2.69 (PA10); also elsewhere on the board
ETH_CRS_DV: U2.32 (PA7); also elsewhere on the board
ETH_DEBUG: U2.1 (PE2); also elsewhere on the board
ETH_MCO1_CLK: U2.67 (PA8); also elsewhere on the board
ETH_MDC: U2.16 (PC1); also elsewhere on the board
ETH_MDINT: U2.26 (PA3); also elsewhere on the board
ETH_MDIO: U2.25 (PA2); also elsewhere on the board
ETH_PHY_NRST: U2.84 (PD3); also elsewhere on the board
ETH_RMII_REF_CLK: U2.24 (PA1); also elsewhere on the board
ETH_RXD0: U2.33 (PC4); also elsewhere on the board
ETH_RXD1: U2.34 (PC5); also elsewhere on the board
ETH_TXD0: U2.51 (PB12); also elsewhere on the board
ETH_TXD1: U2.52 (PB13); also elsewhere on the board
ETH_TX_EN: U2.48 (PB11); also elsewhere on the board
GND: C10.1, C11.1, C20.1, C29.1, C30.1, C45.1, C46.1, C47.1, C48.1, C49.1, C50.1, C51.1, C52.1, C61.1, C62.1, J1.GND, J1.GND@2 (GND), J1.GNDDET, J4.P5 (GND), J7.G1 (PAD), J7.G2 (PAD), J7.G3 (PAD), J7.G4 (PAD), J7.P6 (6), J7.S0 (0), R19.2, U2.10 (VSS), U2.20 (VSSA), U2.27 (VSS), U2.74 (VSS), U2.99 (VSS), X1.2 (3), X1.4 (3); also elsewhere on the board
LED2: LED2.C, U2.55 (PD8)
LED4: LED4.C, U2.56 (PD9)
LED5: LED5.C, U2.57 (PD10)
MAX_!IDLE: U2.42 (PE11); also elsewhere on the board
MAX_!SHDN: U2.41 (PE10); also elsewhere on the board
MAX_ANTFLAG: U2.36 (PB1); also elsewhere on the board
MAX_CFG_!CS: U2.43 (PE12); also elsewhere on the board
MAX_CFG_SPI2_MOSI: U2.54 (PB15); also elsewhere on the board
MAX_CFG_SPI2_SCLK: U2.47 (PB10); also elsewhere on the board
MAX_LD: U2.37 (PB2); also elsewhere on the board
unnamed: LED3.5 (K), R38.1
unnamed: LED3.4 (K), R39.1
unnamed: LED3.6 (K), R40.1
unnamed: J7.S1 (1), TP2.TP
unnamed: LED2.A, R14.1
unnamed: TP35.P$1, U2.86 (PD5)
unnamed: LED4.A, R16.1
unnamed: LED5.A, R20.1
unnamed: TP36.P$1, U2.88 (PD7)
unnamed: TP38.P$1, U2.35 (PB0)
unnamed: TP39.P$1, U2.2 (PE3)
unnamed: TP40.P$1, U2.4 (PE5)
OSC_IN: C30.2, U2.12 (PH0), X1.1
OSC_OUT: C29.2, U2.13 (PH1), X1.3 (2)
RGB-B: R40.2, U2.58 (PD11)
RGB-G: R39.2, U2.61 (PD14)
RGB-R: R38.2, U2.60 (PD13)
SD-VDD: C10.2, C20.2, J7.P4 (4), Q1.3 (D)
SDIO_CLK: J7.P5 (5), U2.80 (PC12)
SDIO_CMD: J7.P3 (3), U2.83 (PD2)
SDIO_D0: J7.P7 (7), U2.65 (PC8)
SDIO_D1: J7.P8 (8), U2.66 (PC9)
SDIO_D2: J7.P1 (1), U2.78 (PC10)
SDIO_D3: J7.P2 (2), U2.79 (PC11)
SDIO_PWR: Q1.1 (G), R12.1, U2.81 (PD0)
SHLD: C62.2, J4.P$1 (SHLD), J4.P$2 (SHLD), J4.P$3 (SHLD), J4.P$4 (SHLD)
STM_USART6_RX: U2.64 (PC7); also elsewhere on the board
STM_USART6_TX: U2.63 (PC6); also elsewhere on the board
TCK: J1.SWDCLK (SWDCLK/TCK), U2.76 (PA14)
TDI: J1.NC (NC/TDI), U2.77 (PA15)
TDO: J1.SWO (SWO/TDO), U2.89 (PB3)
TMS: J1.SWDIO (SWDIO/TMS), U2.72 (PA13)
USB_FS_DM: J4.P2 (D-), U2.70 (PA11)
USB_FS_DP: J4.P3 (D+), U2.71 (PA12)
USB_FS_VBUS: J4.P1 (VCC), U2.68 (PA9); also elsewhere on the board
VCAP_1: C52.2, U2.49 (VCAP_1)
VCAP_2: C51.2, U2.73 (VCAP_2)

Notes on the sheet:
MICROSD
PB15: SPI2_MOSI / AF=5
USB 2.0 Full Speed
MicroSD Card
SWD Programmer
TO MAX2769
TO SKYTRAQ GPS
(MCO1)
(BOOT1)
(MCO2)
Microcontroller

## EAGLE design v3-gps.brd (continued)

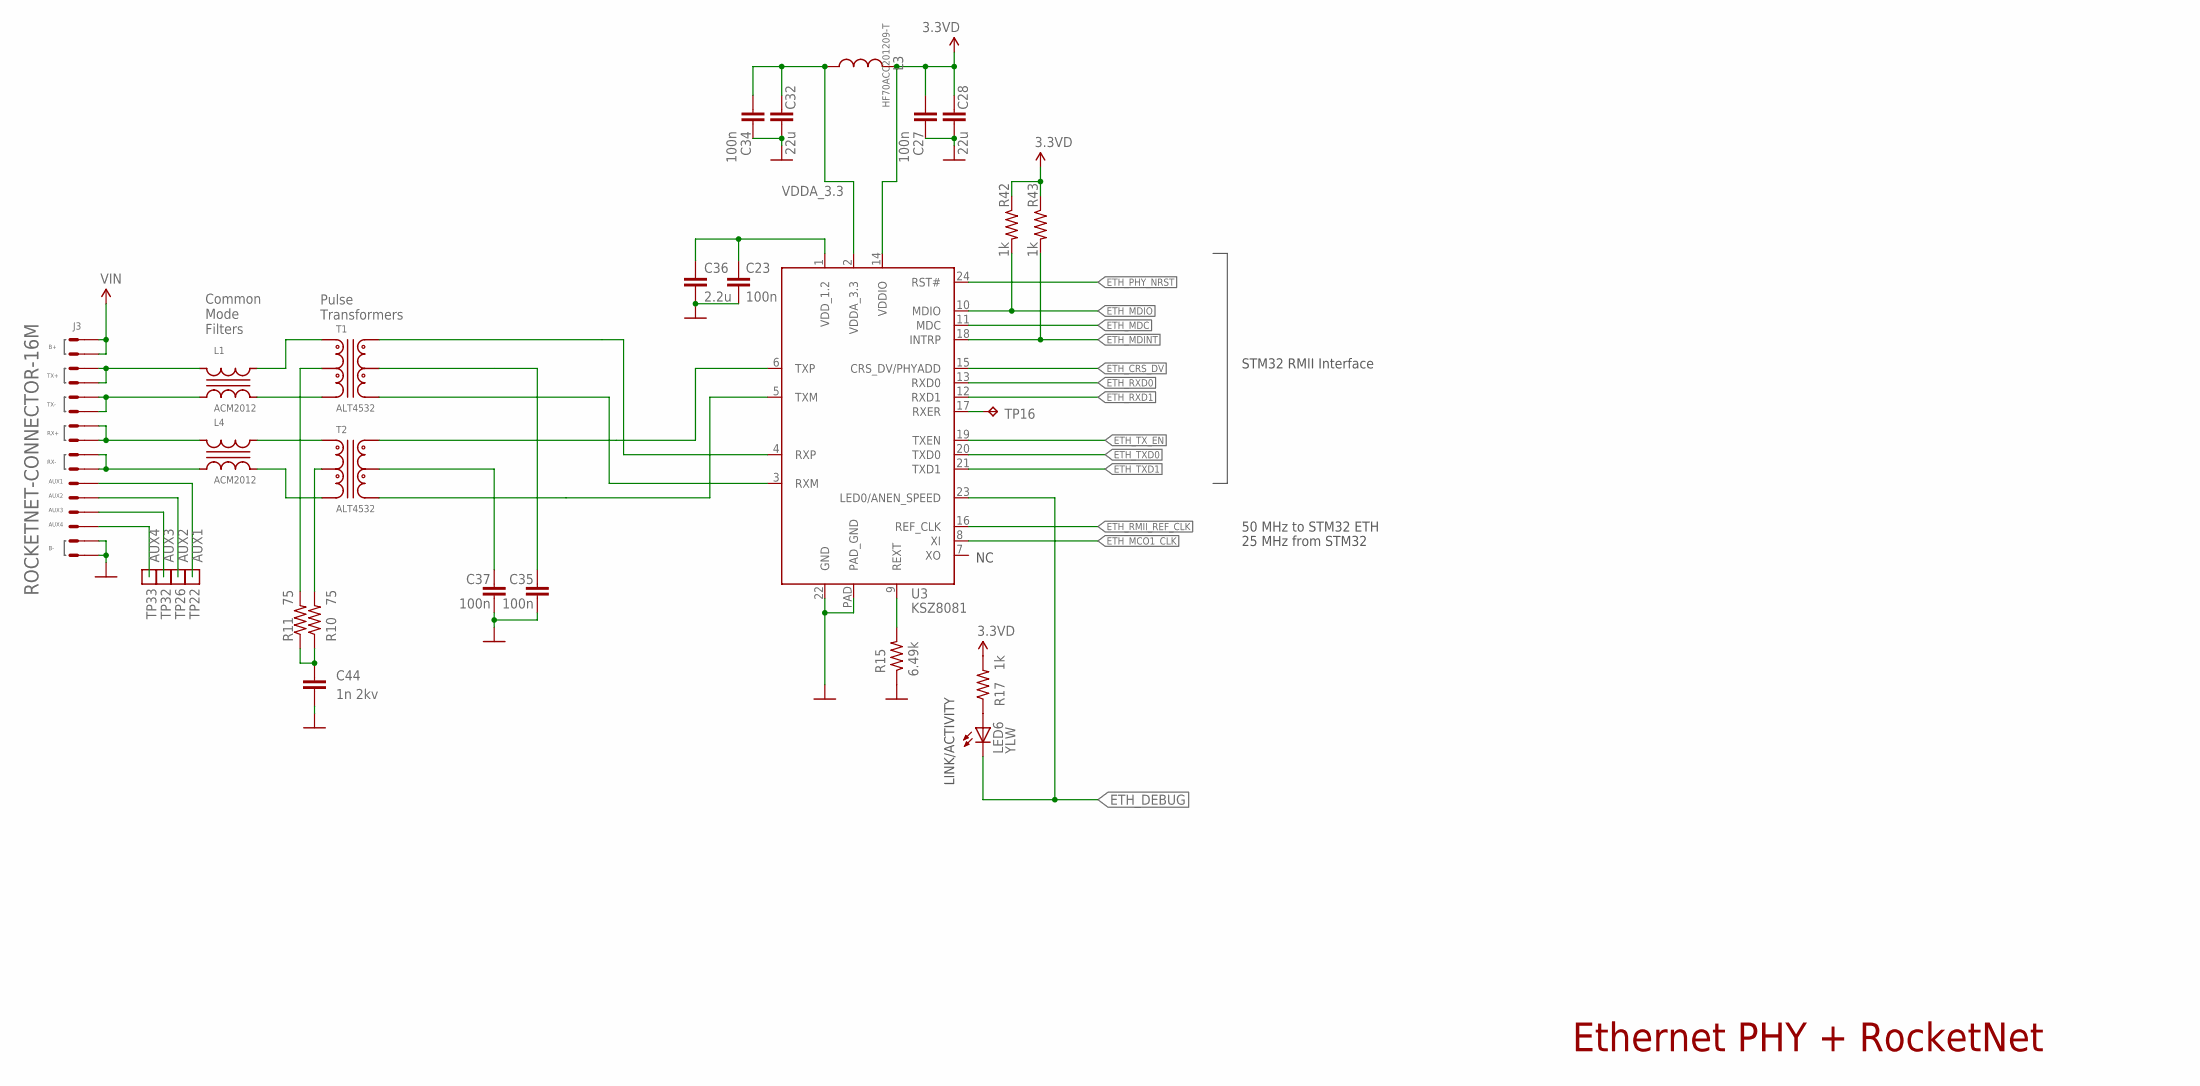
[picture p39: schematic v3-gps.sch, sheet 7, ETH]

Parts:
C23, C27, C34, C35, C37: 100n; .0402-C-NOSILK
C28, C32: 22u; 1206-C
C36: 2.2u; .0603-B-NOSILK
C44: 1n 2kv; .0402-C-NOSILK
J3: ROCKETNET-CONNECTOR-16M; ROCKETNET-M-16
L1, L4: ACM2012; TDK-ACM2012
L3: HF70ACC201209-T; .0805-C-NOSILK
LED6: YLW; CHIPLED_0603
R10, R11: 75; 0402-C-NOSILK@1
R15: 6.49k; 0402-C-NOSILK@1
R17, R42, R43: 1k; 0402-C-NOSILK@1
T1, T2: ALT4532; TDK-ALT4532
TP16: TPTP06R; TP06R
TP22, TP26, TP32, TP33: TEST-POINT15MIL-TEST-POINT; 15MIL-TEST-POINT
U3: KSZ8081; QFN-24

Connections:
3.3VD: C27.2, C28.2, L3.2, R17.2, R42.1, R43.1, U3.14 (VDDIO); also elsewhere on the board
AUX1: J3.A1 (AUX1), TP22.P$1
AUX2: J3.A2 (AUX2), TP26.P$1
AUX3: J3.A3 (AUX3), TP32.P$1
AUX4: J3.A4 (AUX4), TP33.P$1
ETH_CRS_DV: U3.15 (CRS_DV/PHYADD); also elsewhere on the board
ETH_DEBUG: LED6.C, U3.23 (LED0/ANEN_SPEED); also elsewhere on the board
ETH_MCO1_CLK: U3.8 (XI); also elsewhere on the board
ETH_MDC: U3.11 (MDC); also elsewhere on the board
ETH_MDINT: R43.2, U3.18 (INTRP); also elsewhere on the board
ETH_MDIO: R42.2, U3.10 (MDIO); also elsewhere on the board
ETH_PHY_NRST: U3.24 (RST#); also elsewhere on the board
ETH_RMII_REF_CLK: U3.16 (REF_CLK); also elsewhere on the board
ETH_RXD0: U3.13 (RXD0); also elsewhere on the board
ETH_RXD1: U3.12 (RXD1); also elsewhere on the board
ETH_TXD0: U3.20 (TXD0); also elsewhere on the board
ETH_TXD1: U3.21 (TXD1); also elsewhere on the board
ETH_TX_EN: U3.19 (TXEN); also elsewhere on the board
GND: C23.2, C27.1, C28.1, C32.1, C34.1, C35.1, C36.2, C37.1, C44.1, J3.B-@1 (B-), J3.B-@2 (B-), R15.1, U3.22 (GND), U3.PAD (PAD_GND); also elsewhere on the board
unnamed: TP16.TP, U3.17 (RXER)
unnamed: J3.T+@13 (TX+), J3.T+@14 (TX+), L1.1
unnamed: C44.2, R10.1, R11.1
unnamed: J3.T-@9 (TX-), J3.T-@11 (TX-), L1.2
unnamed: LED6.A, R17.1
unnamed: C35.2, T1.3
unnamed: J3.R+@5 (RX+), J3.R+@7 (RX+), L4.1
unnamed: J3.R-@3 (RX-), J3.R-@4 (RX-), L4.2
unnamed: L1.4, T1.1
unnamed: L1.3, T1.2
unnamed: L4.4, T2.1
unnamed: L4.3, T2.2
unnamed: R11.2, T1.6
unnamed: R10.2, T2.6
unnamed: T2.4, U3.5 (TXM)
unnamed: T1.5, U3.4 (RXP)
unnamed: T2.5, U3.6 (TXP)
unnamed: R15.2, U3.9 (REXT)
unnamed: C37.2, T2.3
unnamed: T1.4, U3.3 (RXM)
VDDA_3.3: C32.2, C34.2, L3.1, U3.2 (VDDA_3.3)
VDD_1.2: C23.1, C36.1, U3.1 (VDD_1.2)
VIN: J3.B+@15 (B+), J3.B+@16 (B+); also elsewhere on the board

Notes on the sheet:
Common Mode Filters
Pulse Transformers
LINK/ACTIVITY
25 MHz from STM32
50 MHz to STM32 ETH
Ethernet PHY + RocketNet
STM32 RMII Interface

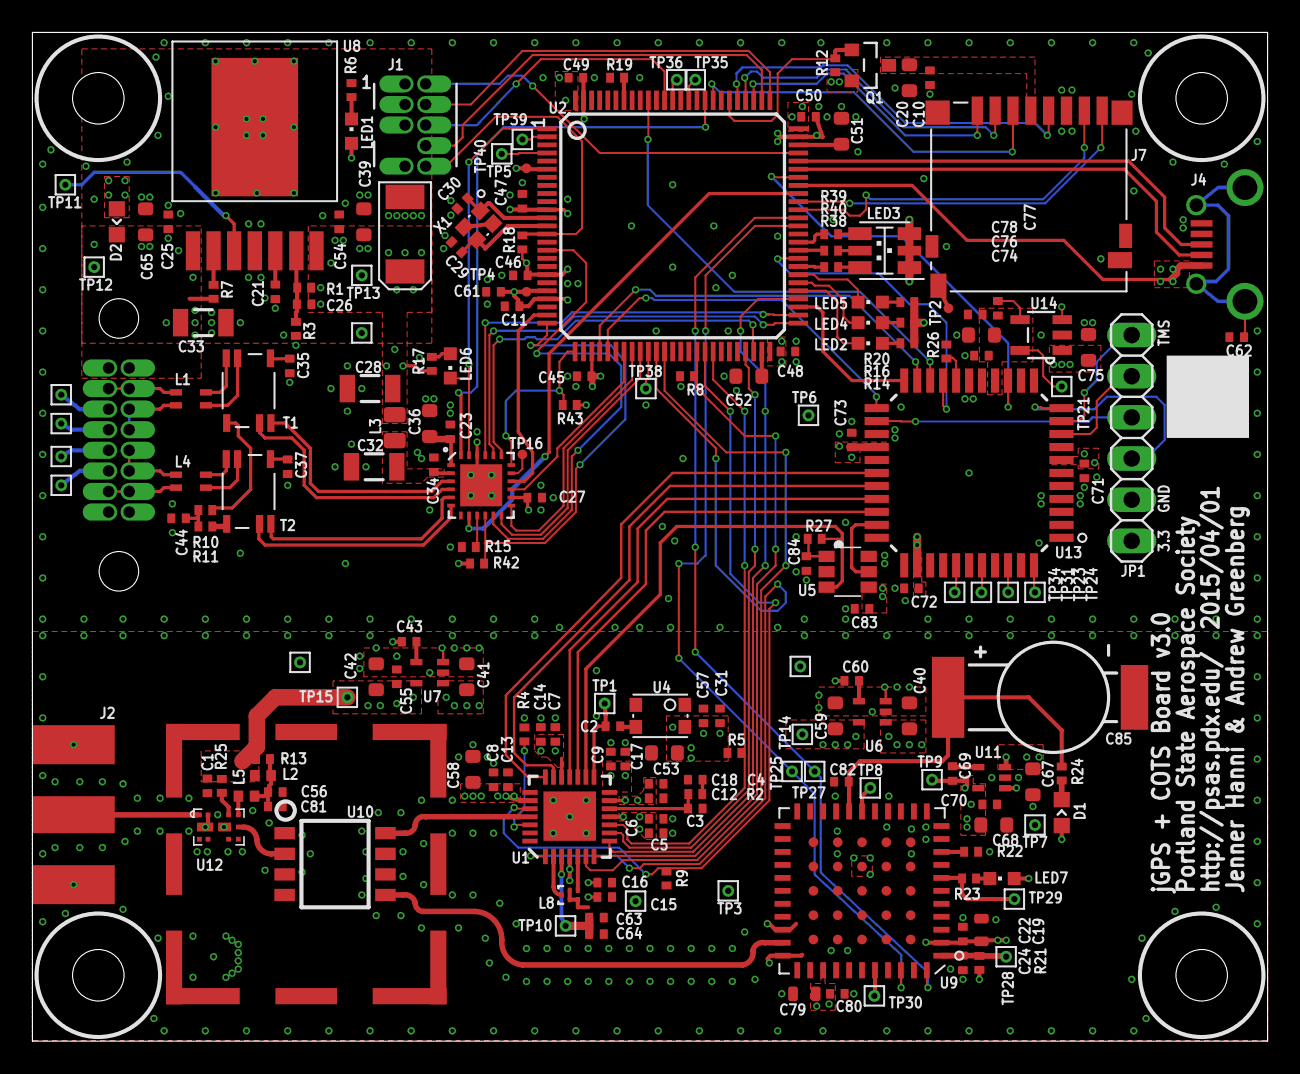
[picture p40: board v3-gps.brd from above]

Board: 4 copper layers, 76.2 x 62.2 mm, 199 parts (0 on the bottom side), 150 nets.

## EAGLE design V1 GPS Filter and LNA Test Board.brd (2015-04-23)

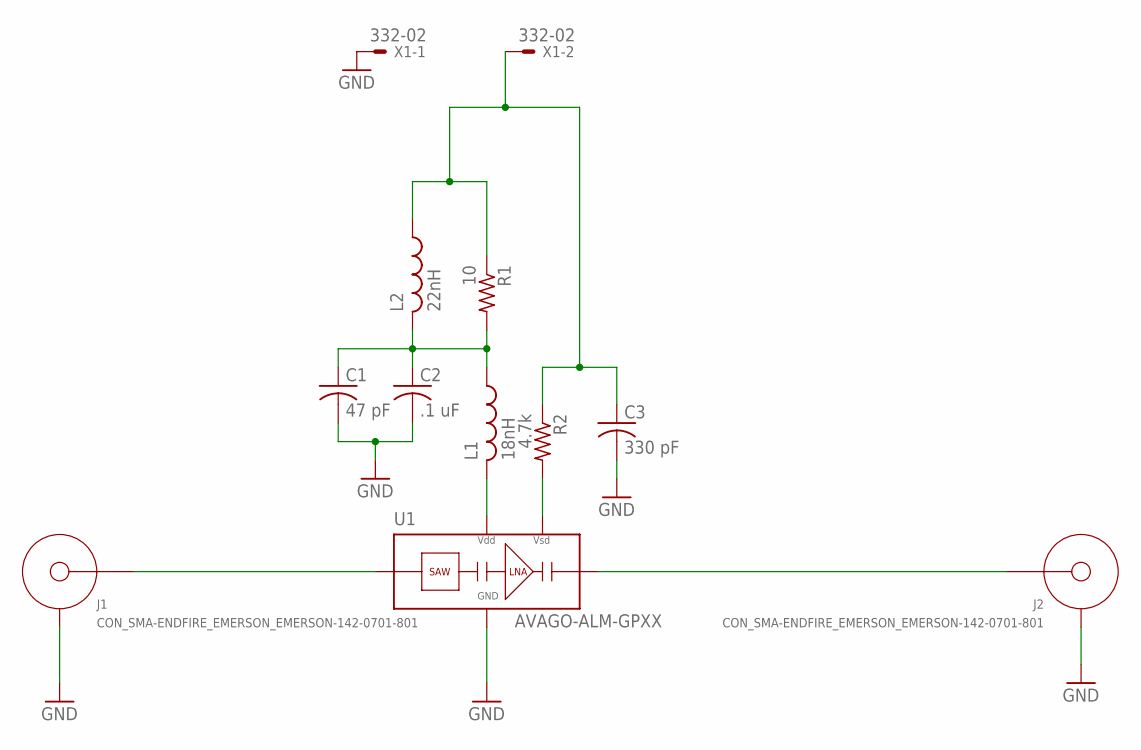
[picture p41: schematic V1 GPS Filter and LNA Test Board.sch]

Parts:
C1: 47 pF; C0402
C2: .1 uF; C0402
C3: 330 pF; C0402
J1, J2: CON_SMA-ENDFIRE_EMERSON_EMERSON-142-0701-801; SMA-CON-EMERSON
L1: 18nH; 0402-C
L2: 22nH; 0402-C
R1: 10; R0402
R2: 4.7k; R0402
U1: AVAGO-ALM-GPXX; AVAGO+SAW+LNA
X1: 332-02

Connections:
GND: C1.2, C2.2, C3.2, J1.GND, J1.GND@1 (GND), J1.GND@2 (GND), J1.GND@3 (GND), J2.GND, J2.GND@1 (GND), J2.GND@2 (GND), J2.GND@3 (GND), U1.2 (GND), U1.3 (GND), U1.4 (GND), U1.9 (GND), U1.P$1 (GND), U1.P$2 (GND), X1.1
unnamed: J1.SIG, U1.1 (RF-IN)
unnamed: L1.2, U1.7 (VDD)
unnamed: C3.1, L2.1, R1.1, R2.1, X1.2
unnamed: C1.1, C2.1, L1.1, L2.2, R1.2
unnamed: R2.2, U1.8 (SD)
unnamed: J2.SIG, U1.6 (RF-OUT)

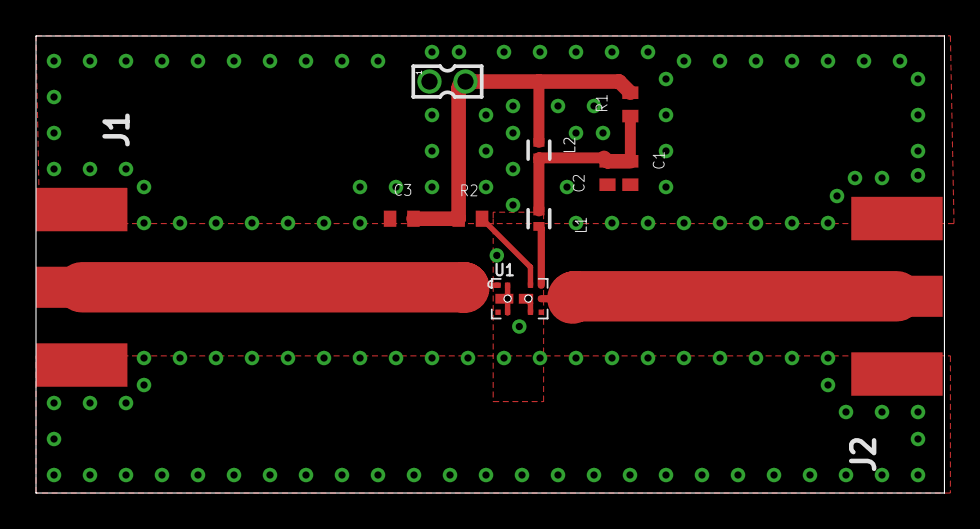
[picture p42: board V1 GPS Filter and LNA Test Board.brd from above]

Board: 2 copper layers, 50.5 x 25.4 mm, 11 parts (0 on the bottom side), 7 nets.

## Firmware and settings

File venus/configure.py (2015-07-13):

#!/usr/bin/python
import serial, time
from struct import pack
import sys

"""
Connects to a SkyTraq Venus on ttyUSB0 and sends some configuration commands

TODO: 
- Verify device has booted after each configuration command has been sent
- Confirm setting with appropriate read command and parse response
- Decide how to actually configure things


Things we definitely want to configure:
    Navigation mode = Airborn
    Bitrate = 115200
    Binary mode
    Update rate = 20 Hz
    Disable SAEE

Venus 8 ROM versions:
    Kernel Version 2.1.5
    ODM Version 1.7.27
    Revision 2015.1.27
"""

ser = serial.Serial('/dev/ttyUSB0', timeout=0.1)

def send_command(data):
    ser.flushInput()
    ser.write(format_data(data))
    time.sleep(.1)
    response = ser.read(100)
    print ' '.join('{:02X}'.format(ord(b)) for b in response)

def format_data(data):
    check = 0
    string = pack(">HH", 0xA0A1, len(data))
    for byte in data:
        check ^= byte
        string += pack("B", byte)
    string += pack(">BH", check, 0x0D0A)
    return string

def baud_rate(code):
    return [4800, 9600, 19200, 38400, 57600, 115200, 230400, 460800, 921600][code]

def meas_data_rate(code):
    """Update rate for binary measurement data output. See SkyTraq AN0030."""
    return [1, 2, 4, 5, 10, 20][code]

max_channels = 20 # we don't expect more than this many satellites locked at once

baud_rate_code = 5 # see baud_rate()
nav_data_rate = 20 # Hz; update rate for navigation data message (see AN0028)
meas_data_rate_code = 5 # see meas_data_rate()
meas_time_enabled = 0
raw_meas_enabled = 0
sv_ch_status_enabled = 0
rcv_state_enabled = 0

bytes_per_second = nav_data_rate * 66

if meas_time_enabled:
    bytes_per_second += meas_data_rate(meas_data_rate_code) * 17

if raw_meas_enabled:
    bytes_per_second += meas_data_rate(meas_data_rate_code) * (10 + 23 * max_channels)

if sv_ch_status_enabled:
    bytes_per_second += meas_data_rate(meas_data_rate_code) * (10 + 10 * max_channels)

if rcv_state_enabled:
    # this message is always sent at 1Hz
    bytes_per_second += 88

# GPS subframe messages
bytes_per_second += 40 * max_channels / 6

print "minimum baud rate: {}".format(bytes_per_second * 10)
print "selected baud rate: {}".format(baud_rate(baud_rate_code))

if bytes_per_second * 10 > baud_rate(baud_rate_code):
    print " *** can't keep up with this config at this baud rate!"
    sys.exit(1)


#ser.baudrate = 115200
#send_command([0x05, 0x00, baud_rate_code, 1])
#time.sleep(.1)

ser.baudrate = baud_rate(baud_rate_code)
time.sleep(.1)

send_command([2, 1]) # query software versions

send_command([0x09, 0x02, 1])    # Set binary output mode
send_command([0x64, 0x17, 5, 1]) # Navigation mode = airborne
send_command([0x63, 0x01, 2, 1]) # Disable "Self-Aided Ephemeris Estimation" (see http://navspark.mybigcommerce.com/content/GNSSViewerUserGuide.pdf)
send_command([0x0E, nav_data_rate, 1])   # System position rate
send_command([0x11, 1, 1])   # Navigation data message rate divider
send_command([0x1E, meas_data_rate_code, meas_time_enabled, raw_meas_enabled, sv_ch_status_enabled, rcv_state_enabled, 0b0001, 1])       # Binary measurement data enable and rate

#send_command([0x10])
#send_command([0x1F])

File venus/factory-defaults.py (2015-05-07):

#!/usr/bin/python
import serial, time

"""
Tries to figure out which baud rate the SkyTraq Venus is configured for
and issues the factory reset command.
"""

device = '/dev/ttyUSB0'
ser = serial.Serial(device)
print "Scanning %s baudrates" % device
for baud in [1200, 2400, 4800, 9600, 19200, 38400, 57600, 115200]:
    ser.baudrate=baud
    ser.flushOutput()
    ser.flushInput()
    ser.write('\xA0\xA1\x00\x02\x02\x01\x03\x0D\x0A')	# request version
    time.sleep(.2)
    if ser.inWaiting():
	read = ser.read(ser.inWaiting())
	if '\xA0\xA1' in read:
	    print "Connected to %s at %i baud" % (device, baud)
	    #print "\\x"+"\\x".join("{:02x}".format(ord(c)) for c in read)
	    ser.write('\xA0\xA1\x00\x02\x04\x01\x05\x0D\x0A')	# factory defaults and restart
	    ser.flush()
	    ser.baudrate=9600
	    ser.flushInput()
	    print "Factory reset complete."
	    print ser.read(100)[4:]
	    break

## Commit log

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2013-04-17 Swapped for 144-pin STM32F4 and started schema changes.
    [v2-rf-frontend-board.brd, v2-rf-frontend-board.sch]
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2013-09-28 Changed JTAG connector to standard 2x5 mini. Broke out GPIO and SPI lines to GPS chip. Added some testpoints. Added STM32F4 reset lines and hooked to JTAG.
    [v2-rf-frontend-board.sch]
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2013-09-28 Reconciled all ERC errors except for power/ground mismatches.
    [v2-rf-frontend-board.sch]
2013-09-29 Added testpoints. Verified pull-up and pull-down lines between STM32F4 and GPS chip. Verified Ethernet PHY circuit. Need Rocketnet connector info. ERC only complains about power/supply mismatch.
    [v2-rf-frontend-board.sch]
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2013-10-04 Cosmetic changes. Waiting on design review with Andrew. Ethernet not entirely done.
    [v2-rf-frontend-board.sch]
2013-10-05 Reviewed with Andrew. Changed 2.2uF packages to 0603. Removed bootloader pins on stm32f4. Added some names. Removed R values on JTAG T lines as per working rocketnet hub circuit. Made USB power pin N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
    [v2-rf-frontend-board.brd, v2-rf-frontend-board.sch]
2013-10-05 Found application circuit that does what we want and is OK for 4.5V-26V. Added backfeed protection from USB 5V input and connected to Rocketnet input. Added the linear regulator and LT4619 buck dc/dc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
    [v2-rf-frontend-board.brd, v2-rf-frontend-board.sch]
2013-10-06 Added LEDs to linear regulator for 5V and 3.3VA. Made another pass over Ethernet. The only weird place left is in the PHY_CLK_25MHz and REF_CLK signals. Also need to compare gps chip analog to piksi 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
    [v2-rf-frontend-board.brd, v2-rf-frontend-board.sch]
2013-10-16 Added pubs. Cleaned up non-power ERC errors. One last lookover. Added a couple testpads.
    [v2-rf-frontend-board.brd, v2-rf-frontend-board.sch]
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2013-12-05 Fixed FIXMEs. Added TP on LD.
    [v2-rf-frontend-board.brd, v2-rf-frontend-board.sch]
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2013-12-14 Laid the RF part. Four layers, AVDD and DVDD good where they meet.
    [v2-rf-frontend-board.brd, v2-rf-frontend-board.sch]
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2013-12-15 Took a first try at Ethernet section. Tight but a little worried about trace widths.
    [v2-rf-frontend-board.brd, v2-rf-frontend-board.sch]
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2014-01-06 BOM done. Board done. All parts reviewed. Ready for review & ship.
    [v2-parts.csv, v2-rf-frontend-board.brd, v2-rf-frontend-board.sch]
2014-01-06 Fixed BOM formatting so it's a pretty CSV file.
    [v2-parts.csv]
2014-01-20 Fixes as per design review. microUSB footprint needs help but symbol and signals OK. RF side placement adjusted but impedance 50 ohms wants 14mm wide trace. help.
    [v2-rf-frontend-board.brd, v2-rf-frontend-board.sch]
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2014-02-02 Major changes to to PWR and GPS sheets. No change to board layout yet, waiting on feedback.
    [v2-rf-frontend-board.brd, v2-rf-frontend-board.sch]
2014-02-05 Made a capacitor options footprint and symbol for the 'do not populate' choice capacitor hack.
    [v2-rf-frontend-board.brd, v2-rf-frontend-board.sch]
2014-02-05 New power parts added to layout and all power airwires resolved. Supply layer re-designed.
    [v2-rf-frontend-board.brd]
2014-02-05 Laid out new LNA1, LNA2, and ANTBIAS sections. Layout done. Passes ERC, DRC. Ready for design review.
    [v2-rf-frontend-board.brd, v2-rf-frontend-board.sch]
2014-02-05 CLeaned up 2.85VA as an example layout; set tnames to the smallest usable size.
    [v2-rf-frontend-board.brd]
2014-02-08 ERC and DRC passed. Added ground vias everywhere. Fixed 0.1in breakout header by making new symbol, should be able to drop in a proper header if we want. Changed order of IO pins on sch to make sense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
    [v2-rf-frontend-board.brd, v2-rf-frontend-board.sch]
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2014-02-12 Fixed merge issues. Board opens OK.
    [v2-rf-frontend-board.brd]
2014-02-12 Cleanup on Jenner's fine work. Mostly adding polygons to power signals, some additional caps, moving parts around for optimal placement, added mounting holes, made polygon lines consistent. NOT DONE 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
    [v2-rf-frontend-board.brd, v2-rf-frontend-board.sch]
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2014-03-26 Beeeeg changes to GPS board. Caught many small mistakes in STM and LAN wiring and footprints, fixed. Better layout of magnetics, replumbed the lines between STM32 and LAN, and more. Passes ERC and DR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
    [v2-rf-frontend-board.brd, v2-rf-frontend-board.sch]
2014-03-30 Switched to the KSZ8081RNA PHY layer IC, the best PHY layer IC ever. I'm sure we'll hate it later, but for now, it's great. New library and datasheet and schematic, still need to wire it up.
    [v2-rf-frontend-board.brd, v2-rf-frontend-board.sch]
2014-03-30 PHY layout, plus connection to COTS GPS board via a 0.1" header that could also be (shock!) an FTDI cable. Last thing left: SAW filters!
    [v2-rf-frontend-board.brd, v2-rf-frontend-board.sch]
2014-03-31 Checked SAW and LNA, moved to endfire SMA, still need to cleanup RF and also, see README for the beginning of a component writeup and a todo list.
    [v2-rf-frontend-board.brd, v2-rf-frontend-board.sch]
2014-03-31 Better RF layout. Now doing tented vias for a tighter layout, also changed design rules to get same signal vias closer in to pads. Is 1x width enough clearance to ground for RF signals? And then the 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
    [v2-rf-frontend-board.brd, v2-rf-frontend-board.sch]
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2014-06-12 Added modwire proposals for SPI 3-wire fix. See Issue 4 in gps-rf-board github repository.
    [v2-rf-frontend-board.brd, v2-rf-frontend-board.sch]
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2014-06-13 Removed !SS line from patch, made it pretty, in schematic. Added older docs that should have been added. Updated BOM with digikey part numbers.
    [v2-parts.xls, v2-rf-frontend-board.brd, v2-rf-frontend-board.sch]
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2014-06-28 Added modwire for SPI1-NSS. This should enable the use of STM32 SPI1 in slave mode to read data output.
    [v2-rf-frontend-board.brd, v2-rf-frontend-board.sch]
2014-06-29 Cleaned up modwire patches a bit. Added cuts in 0.1" double header.
    [v2-rf-frontend-board.brd, v2-rf-frontend-board.sch]
2014-06-29 Whoops, fixed CLK and DATA mixup from MAX using even MORE modwires.
    [v2-rf-frontend-board.brd, v2-rf-frontend-board.sch]
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2014-12-17 OMG, what did I just do? GPS 4 bit output to SPI converter, in EAGLE. Not sure if it works, but somebody should prototype this.
    [gps-to-spi.sch]
2014-12-17 OK, I had to polish it: names, test points, header inputs/outputs, no ERC errors.
    [gps-to-spi.sch]
2014-12-31 First cut at monolithic GPS board for AV4: MAX2769 + COTS GPS chip (SkyTraq 638). Still TONS to do, including the CPLD the stupid MAX2769 requires.
    [v3-gps.brd, v3-gps.sch]
2015-01-28 First commit of the GPS v3 board, which includes the CPLD and SkyTraq ICs.
    [v3-gps.brd, v3-gps.sch]
2015-01-28 More rough drafting on the CPLD. Added 1.8V supply (kind of), added some cleanup notes on clock, etc. TODO: everything still, including cleanup up 1.8V supply and probably splitting the power domains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
    [gps-to-spi.sch, v3-gps.brd, v3-gps.sch]
2015-02-01 using the GPS Carrier from AV4, expanded the size of the board to fit in the AV4 C channel and give more room. Moved everything onto that larger board, with preliminary placement. About to rip up and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
    [v3-gps.brd, v3-gps.sch]
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2015-03-01 Digital portion of v3 basically laid out, RF sections laid out. To do: verify CPLD power supply, think more about ground/power separation for RF section.
    [v3-gps.brd, v3-gps.sch]
2015-03-02 Added link to the MAX2769 google doc, as well as renamed things to be BOM, and committed some minor changes in the layout and notes in the schematic.
    [v1-bom.ods, v2-bom.xls, v3-gps.brd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]
2015-03-04 Added Test Board
    Added eagle file of GPS test board for Saw Filter and LNA chip
    [V1 GPS Filter and LNA Test Board.brd, V1 GPS Filter and LNA Test Board.sch]
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2015-03-25 Forgot to add comparator library earlier. Added bzillions of test points, to CPLD and STM, for future mod wires :) Also left RF class isolate to 25 mils, forgot to reset that during the last commit. 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
    [v3-gps.brd, v3-gps.sch]
2015-03-25 Added part numbers to some of the odder components. Found the supercap is no longer made, so switched it to an instock item. Also checked on other components, like the LNA and splitter. Cleaned up sc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
    [v3-gps.brd, v3-gps.sch]
2015-03-28 So many little tweaks: updated ground planes, created BOM and then found out that everything doesn't exist anymore, so found new part numbers and in some cases (like the supercap) found new parts, ar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
    [v3-gps.brd, v3-gps.sch, v3-gps.xlsx]
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2015-04-01 We broke oshpark! So we generated gerbers. Also, glad we did, because there were errors in the solder mask in some of the library parts, now fixed.
    [v3-gps.brd, v3-gps.sch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]
2015-04-29 Added Xilinx docs, and changed the SAW/LNA to the *correct* part number
    [v3-gps.brd, v3-gps.sch, v3-gps.xlsx]
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2015-06-10 Updated Schematic and BOM with problems, wrong values, etc.
    [v3-gps.brd, v3-gps.sch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]
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

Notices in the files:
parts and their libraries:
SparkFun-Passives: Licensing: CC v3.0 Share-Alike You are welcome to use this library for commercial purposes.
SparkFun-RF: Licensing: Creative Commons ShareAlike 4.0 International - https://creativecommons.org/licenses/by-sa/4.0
